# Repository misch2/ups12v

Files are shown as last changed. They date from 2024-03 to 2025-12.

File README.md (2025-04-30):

# Goal

A hobby project to create simple 12 V UPS to backup my router and mini PC. Both appliances use 12 volts on input. 
This UPS:
 - should be powered by 18650 batteries
 - does not need to run for a long time, 15 minutes is perfectly OK, 30 minutes is luxury
 - should allow some sort of monitoring, ideally with an HomeAssistant integration (for charts etc.)
 - should provide at least this amount of power
   - 1A (for router)
   - or 3A (for mini PC)
 - should run primarily from the main source and switch to the batteries only when the main voltage drops. This is to protect the batteries and charging circuit so that it doesn't need to constantly provide relatively high power for a device.
 - might allow powering off itself on request when running on batteries, to allow mini PC to automatically power on later after a shutdown.

# Features

 - Can be controlled and monitored using HomeAssistant (ESP32C3 chip, ESPHome software)
 - 12 V / 3 A output
 - (optional) SW controllable output poweroff, can be used to power cycle the device attached to UPS
 - (optional) Battery calibration, i.e. one-off measuring of real available battery capacity.
 - (optional) UPS cut off on power loss and low battery, to allow for a full shutdown of both UPS and the attached device.

# Inspiration
* https://www.hackster.io/news/a-diy-mini-ups-for-wi-fi-router-9b8f11540294
* https://digitalab.org/2021/08/router-ups/
* Lithium battery charger module (12W, 3A) with 5V to 12V booster from Aliexpress:
https://vi.aliexpress.com/item/1005005742927465.html?gatewayAdapt=glo2vnm

# Version 1

Deployed to production, used for a backup of my Archer C6 router only. 
But it's mostly a proof of concept, with power limitations and without a proper PCB (components are just wired up together).

Schema: [schema_v1.pdf](hardware/v1/schema.pdf)

Some photos: [photo1](hardware/v1/IMG_20240301_100945.jpg), [photo2](hardware/v1/IMG_20240302_140645.jpg), [photo3](hardware/v1/IMG_20240302_140731.jpg).

"boosterEnable" input is there not to save power but to prevent running the XL6009 booster in an undervoltage condition. This could have been implemented using a voltage comparator (LM311?) + schmitt trigger for hysteresis. I used software solution because tbne undervoltage condition doesn't occur "suddenly" but it's only a startup condition. And using software to control it allows me to use it for powering off the UPS when it runs on battery.

## Development progress

Replaced AMS1117 with a buck converter due to a large voltage difference and therefore large heat dissipation with LDO.

Added XL6009 "EN" pin control (initial pull down + software control from ESP32).

Used Schottky diodes.

Added a diode between battery power line and XL6009 to prevent backpropagation of voltage when XL6009 is powered down.

The limitations were caused by:
 - BMS module for 18650 batteries can handle only 2A (FIXME?) of current. This is not enough for the mini PC.
 - INA219 module can handle only 3.2A of current. Again, this is not enough for the mini PC (especially not for the battery side of the UPS where the max current can easily be larger).
 - The specific XL6009 booster module doesn't have an undervoltage protection and it can produce more than 12 V on it's output when the input voltage is low. This is not good!

Anyway, this works well for the router. It can run for more than 2 hours from batteries because the router consumes only about 3 watts and the output current is therefore mostly below 300 mA. So I might call this a success ✅!

# Version 1.5

I wanted to overcome the limitations of the first version and to make it handle larger current to power the mini PC which might need up to 3 A. This higher current would also require something better than the INA219.

I also added relays to allow the UPS to be powered off completely when running on batteries. This is to allow the mini PC to power on automatically after a power outage. And a 2nd relay allows to power cycle the UPS or to run calibration.

ACS712 sensors paired with an ADS1115 ADC are used for current and voltage monitoring. It can handle up to 20 A. 

A pair of XL74610 ideal diodes is used instead of Schottky diodes in v1, to achieve a lower voltage drop and to allow for higher currents.

TP5100 charger module is used for charging the batteries, combined with BMS for 2S 8.4V/20A.

Alas, while everything looked good on the paper, reality was different ❌. The "better" booster module ([LM2587 version](https://www.laskakit.cz/step-up-boost-menic-lm2587--4-30v-30w/)) advertises up to 5A and 30W, but something might be wrong with it. I'm not able to pull more than 1 A from the UPS, the voltage drastically drops if I try to pull more.

Possible causes (investigating ⌛):
 - Batteries don't provide enough current? Not very probable, I'm using 3000 mAh cells from a reputable manufacturer.
 - BMS module can't handle the current? It should be able to handle 20 A but does it?
 - Booster module can't handle the current? It should be able to handle 5 A but does it?
 - Something else?

An idea: disconnect the LM2587 booster and attach an electronic load to the battery instead of it. Then try to pull whatever it takes to see if the batteries can provide the current. If they can, then the problem is with the booster. If they can't, then the problem is with the batteries or BMS.

Result: ⌛

# FIXME TODO 

Maybe this was a completely bad approach. Sticking to 2x 18650 doesn't make sense if I need to pull 3 A. I should have used 4S 18650 (13.6 V - 16.8 V) and eliminate the boost converter completely. When stepping down to 12 V, the current would be lower and the voltage drop would be lower.
Also no need to stick with 12 V and a boost converter on input.

# Version 2

Using **BQ25798** battery charger IC from Texas Instruments. According to the datasheet it can handle up to 5 A on the output and 3A on the input and has a built-in buck-boost converter usable for either battery charging or for the UPS backup mode. It can also be controlled and monitored extensively using I2C.

Product info: https://www.ti.com/product/BQ25798

Most important features:
* Buck-boost charger for 1-4 cell batteries
* Narrow voltage DC (NVDC) power path
* Backup Mode with Ultra-fast switchover to adjustable voltage
* Flexible autonomous and I2C mode for optimal system performance
* Intelligent current management to prevent source overload when charging batteries
* Integrated 16-bit ADC for voltage, current, and temperature monitoring

It's essentially a battery charger capable of using boost converter to charge the batteries, but it can also detect a drop in input voltage and switch to the backup mode aka battery mode very fast. In the backup mode it works as buck converter and uses the batteries to power the load.

So, theoretically, with this IC I can eliminate all the former external circuitry because BQ25798 will take care of both charging the batteries and providing power to the load. And it has hundreds of I2C registers to set up and monitor the system.

#### Normal mode power path:

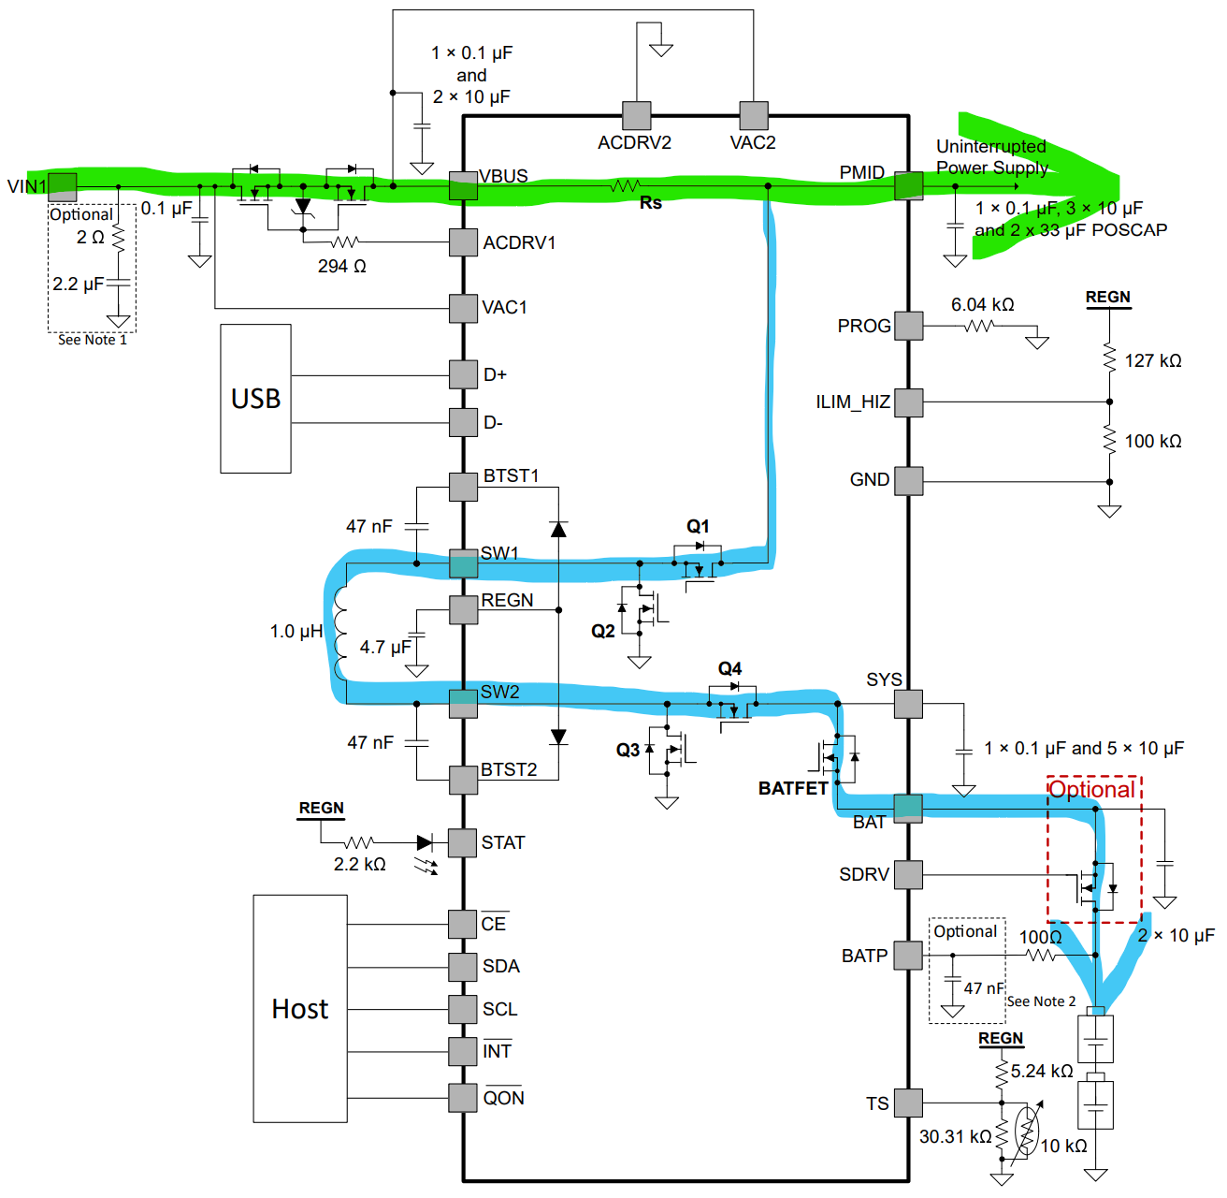
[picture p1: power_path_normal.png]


#### Backup mode power path:

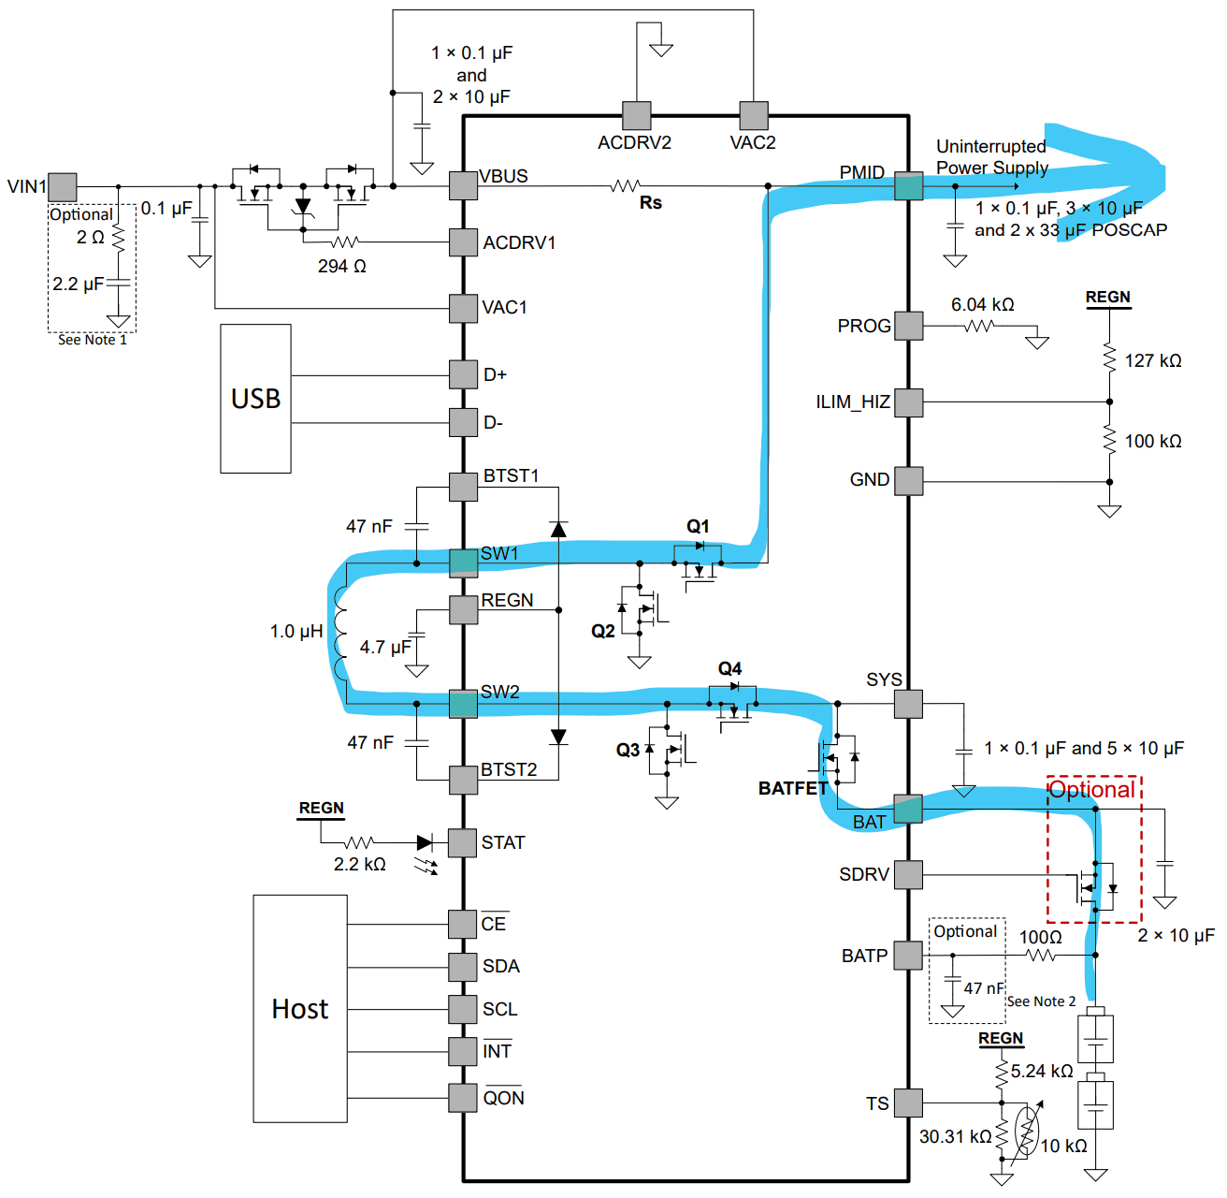
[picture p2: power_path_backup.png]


#### Inductor selection

See page 133 of datasheet:

```
L = 2.2 µH (only two inductor values are available: 2.2 µH and 1 µH)

Isat >= MAX((Iin + Iripple/2), Ichg + Iripple/2)

Iripple_buck = Vsys / Vbus * (Vbus - Vsys) / (Fsw * L)
Iripple_boost = Vbus /Vsys * (Vsys - Vbus) / (Fsw * L)
```

For my purposes (12 V input, 12 V output, 4S Li-Ion battery pack, 3 A power source) the values are:

```
Iin = 3 A (input current)
Vbus = 12 V (input voltage)
Vsys = +16.8 V (battery voltage)

Iripple_buck = 12 V / 16.8 V * (16.8 V - 12 V) / (750 kHz * 2.2 uH) = 3.43 / 1.65 = 2.08 A
Iripple_boost = 16.8 V / 12 V * (12 V - 16.8 V) / (750 kHz * 2.2 uH) = -6.72 / 1.65 = -4.07 A

Isat >= MAX(5.08 A, 7.07 A) = 7.07 A
```

#### PROG resistor selection

See page 25 of datasheet:

2.2 uH inductor requires 750 kHz switching frequency. Therefore the PROG resistor = **27 kOhm** which means:
 - Switching frequency = 750 kHz
 - Cell count: 4
 - ICHG: 1 A
 - VSYSMIN: 12 V
 - VREG: 16.8 V (range 14 V - 18.8 V)

### Principle:

#### Forward (battery charge) mode:

In this mode PMID follows VBUS, i.e. it's not regulated. PMID is also the input to the buck-boost converter. 

#### Battery backup mode:

The FETs between AC1 and VBUS provide reverse blocking (prevents battery voltage from being seen at VBUS). PMID is output of the buck/boost converter.

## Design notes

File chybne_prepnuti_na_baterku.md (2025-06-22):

```
[T+ 90.540s]      ADC_DONE_STAT (bool) = TRUE                                                   (was false)
[T+ 90.540s]             ADC_EN (bool) = false                                                  (was TRUE)
[T+ 90.540s]         TS_ADC (float, %) = 60.059                  (was 58.887)
[T+ 90.540s]       DPLUS_ADC (int, mV) = 4                        (was     3)
Main stats: VSYS_REG! NO_VBAT! +EN_BACKUP +EN_CHG +EN_ACDRV1 CHG=[1]"Trickle Charge" 

[T+ 94.714s]           CHG_FLAG (bool) = TRUE                                                   (was false)
[T+ 94.714s]   VBATOTG_LOW_FLAG (bool) = TRUE                                                   (was false)
Main stats: VSYS_REG! NO_VBAT! +EN_BACKUP +EN_CHG +EN_ACDRV1 CHG=[1]"Trickle Charge"

[T+ 96.702s]           CHG_STAT (enum) = [0] "Not Charging"                                     (was [1] "Trickle Charge")
[T+ 96.702s]          VSYS_STAT (enum) = [0] "Not in VSYSMIN regulation (VBAT > VSYSMIN)"       (was [1] "In VSYSMIN regulation (VBAT < VSYSMIN)")
[T+ 96.702s]   VBATOTG_LOW_STAT (enum) = [0] "VBAT is too low to enable OTG mode"               (was [1] "VBAT is high enough to enable OTG operation")
[T+ 96.702s]      VBAT_OVP_STAT (bool) = TRUE                                                   (was false)
[T+ 96.702s]           CHG_FLAG (bool) = TRUE                                                   (was false)
Main stats: NO_VBAT! +EN_BACKUP +EN_CHG +EN_ACDRV1 CHG=[0]"Not Charging"

[T+ 96.958s]           CHG_STAT (enum) = [1] "Trickle Charge"                                   (was [0] "Not Charging")
[T+ 96.958s]          VSYS_STAT (enum) = [1] "In VSYSMIN regulation (VBAT < VSYSMIN)"           (was [0] "Not in VSYSMIN regulation (VBAT > VSYSMIN)")
[T+ 96.958s]   VBATOTG_LOW_STAT (enum) = [1] "VBAT is high enough to enable OTG operation"      (was [0] "VBAT is too low to enable OTG mode")
[T+ 96.958s]      VBAT_OVP_STAT (bool) = false                                                  (was TRUE)
[T+ 96.958s]   VBATOTG_LOW_FLAG (bool) = TRUE                                                   (was false)
Main stats: VSYS_REG! NO_VBAT! +EN_BACKUP +EN_CHG +EN_ACDRV1 CHG=[1]"Trickle Charge" 

[T+ 98.198s]           CHG_STAT (enum) = [0] "Not Charging"                                     (was [1] "Trickle Charge")
[T+ 98.198s]          VSYS_STAT (enum) = [0] "Not in VSYSMIN regulation (VBAT > VSYSMIN)"       (was [1] "In VSYSMIN regulation (VBAT < VSYSMIN)")
[T+ 98.198s]   VBATOTG_LOW_STAT (enum) = [0] "VBAT is too low to enable OTG mode"               (was [1] "VBAT is high enough to enable OTG operation")
[T+ 98.198s]      VBAT_OVP_STAT (bool) = TRUE                                                   (was false)
[T+ 98.198s]           CHG_FLAG (bool) = TRUE                                                   (was false)
Main stats: NO_VBAT! +EN_BACKUP +EN_CHG +EN_ACDRV1 CHG=[0]"Not Charging"
```

Tady se to po připojení baterie krásně přepnulo a drželo:
```
[T+ 99.635s]  VBAT_PRESENT_STAT (enum) = [1] "VBAT present"                                     (was [0] "VBAT NOT present")
Main stats: +EN_BACKUP +EN_CHG +EN_ACDRV1 CHG=[0]"Not Charging" 

[T+120.330s]      ADC_DONE_STAT (bool) = false                                                  (was TRUE)
[T+120.330s]             ADC_EN (bool) = TRUE                                                   (was false)
[T+120.330s]        IBUS_ADC (int, mA) = 19                       (was    58)
[T+120.330s]        VBUS_ADC (int, mV) = 4814                     (was  5025)
[T+120.330s]        VAC1_ADC (int, mV) = 4799                     (was  5010)
[T+120.330s]        VAC2_ADC (int, mV) = 4800                     (was  5009)
[T+120.330s]        VBAT_ADC (int, mV) = 7922                     (was  2014)
[T+120.330s]        VSYS_ADC (int, mV) = 16130                    (was  3397)
Main stats: +EN_BACKUP +EN_CHG +EN_ACDRV1 CHG=[0]"Not Charging"

[T+120.586s]      ADC_DONE_STAT (bool) = TRUE                                                   (was false)
[T+120.586s]             ADC_EN (bool) = false                                                  (was TRUE)
[T+120.586s]         TS_ADC (float, %) = 61.816                  (was 60.059)
[T+120.586s]    TDIE_ADC (float, degC) = 61.500                  (was 18.500)
[T+120.586s]       DPLUS_ADC (int, mV) = 35                       (was     4)
[T+120.586s]      DMINUS_ADC (int, mV) = 35                       (was     3)
Main stats: +EN_BACKUP +EN_CHG +EN_ACDRV1 CHG=[0]"Not Charging"
```

Ale po chvíli se to přepnulo zpátky do normálního režimu, což při odpojeném napájení znamená problém:
```
[T+131.261s]          EN_BACKUP (bool) = false                                                  (was TRUE)
[T+131.261s]          EN_ACDRV1 (bool) = false                                                  (was TRUE)
[T+131.261s]        ICO_ILIM (int, mA) = 500                      (was  3000)
[T+131.261s]            PG_STAT (enum) = [0] "Not in power good status"                         (was [1] "Power good")
[T+131.261s]   AC2_PRESENT_STAT (enum) = [0] "VAC2 NOT present"                                 (was [1] "VAC2 present (above present threshold)")
[T+131.261s]   AC1_PRESENT_STAT (enum) = [0] "VAC1 NOT present"                                 (was [1] "VAC1 present (above present threshold)")
[T+131.261s]  VBUS_PRESENT_STAT (enum) = [0] "VBUS NOT present"                                 (was [1] "VBUS present (above present threshold)")
[T+131.261s]          VBUS_STAT (enum) = [0] "No Input or BHOT or BCOLD in OTG mode"            (was [5] "Unknown adaptor (3A)")
[T+131.261s]      VBAT_OVP_STAT (bool) = false                                                  (was TRUE)
Main stats: NOT_PG! NO_VBUS! NO_AC1! +EN_CHG CHG=[0]"Not Charging"

[T+150.471s]      ADC_DONE_STAT (bool) = false                                                  (was TRUE)
[T+150.471s]      VBAT_OVP_STAT (bool) = TRUE                                                   (was false)
[T+150.471s]             ADC_EN (bool) = TRUE                                                   (was false)
[T+150.471s]        IBUS_ADC (int, mA) = 0                        (was    19)
[T+150.471s]        VBUS_ADC (int, mV) = 0                        (was  4814)
[T+150.471s]        VAC1_ADC (int, mV) = 0                        (was  4799)
[T+150.471s]        VAC2_ADC (int, mV) = 0                        (was  4800)
[T+150.471s]        VBAT_ADC (int, mV) = 7989                     (was  7922)
[T+150.471s]        VSYS_ADC (int, mV) = 16194                    (was 16130)
Main stats: NOT_PG! NO_VBUS! NO_AC1! +EN_CHG CHG=[0]"Not Charging"

[T+150.738s]      ADC_DONE_STAT (bool) = TRUE                                                   (was false)
[T+150.738s]      VBAT_OVP_STAT (bool) = false                                                  (was TRUE)
[T+150.738s]             ADC_EN (bool) = false                                                  (was TRUE)
[T+150.738s]         TS_ADC (float, %) = 61.426                  (was 61.816)
[T+150.738s]    TDIE_ADC (float, degC) = 20.000                  (was 61.500)
[T+150.738s]       DPLUS_ADC (int, mV) = 25                       (was    35)
[T+150.738s]      DMINUS_ADC (int, mV) = 25                       (was    35)
Main stats: NOT_PG! NO_VBUS! NO_AC1! +EN_CHG CHG=[0]"Not Charging"
```

Proč? Viz VBAT_OVP_STAT. Myslelo si to, že je baterka přebitá. Důvodem bylo toto, chybná startovací konfigurace:
```
[T+  0.000s]         VSYSMIN (int, mV) = 3500
[T+  0.000s]            VREG (int, mV) = 4200
[T+  0.000s]            ICHG (int, mA) = 1000
[T+  0.000s]               CELL (enum) = [0] "1S"
[T+  0.000s]           PWM_FREQ (enum) = [1] "750 kHz"
[T+  0.000s]  VBAT_PRESENT_STAT (enum) = [0] "VBAT NOT present"
```
To odpovídá PROG rezistoru 4k7, nikoli 27k:
```
Table 9-1. PROG Pin Resistance to Set Default Switching Frequency and Battery Cell Count
SWITCHING FREQUENCY CELL COUNT TYPICAL RESISTANCE AT PROG PIN
1.5 MHz 1s 3.0 kΩ
750 kHz 1s 4.7 kΩ
1.5 MHz 2s 6.04 kΩ
750 kHz 2s 8.2 kΩ
1.5 MHz 3s 10.5 kΩ
750 kHz 3s 13.7 kΩ
1.5 MHz 4s 17.4 kΩ
750 kHz 4s 27.0 kΩ
```

!!! OK !!!

Po kontrole PCB je to už OK:
```
[T+  0.000s]         VSYSMIN (int, mV) = 12000
[T+  0.000s]            VREG (int, mV) = 16800
[T+  0.000s]            ICHG (int, mA) = 1000
[T+  0.000s]               CELL (enum) = [3] "4S"
[T+  0.000s]        VBUS_ADC (int, mV) = 5064
```

Nastavení a detekce napětí z 5V taky vypadá dobře (5 V na VAC1, 12 V na SYS -- tedy přes boost converter):
```
[T+  1.435s]      ADC_DONE_STAT (bool) = TRUE                                                   (was false)
[T+  1.435s]             ADC_EN (bool) = false                                                  (was TRUE)
[T+  1.435s]        VAC1_ADC (int, mV) = 5068                     (was  5151)
[T+  1.435s]        VAC2_ADC (int, mV) = 5064                     (was  5151)
[T+  1.435s]        VBAT_ADC (int, mV) = 266                      (was   348)
[T+  1.435s]        VSYS_ADC (int, mV) = 12269                    (was  2893)
[T+  1.435s]    TDIE_ADC (float, degC) = 30.500                  (was 12.000)
[T+  1.435s]       DPLUS_ADC (int, mV) = 0                        (was  3388)
Main stats: VSYS_REG! NO_VBAT! +EN_BACKUP +EN_CHG +EN_ACDRV1 CHG=[0]"Not Charging"
```

Po připojení baterie se mimo jiné zvedne proud IBUS na 230 mA. Napětí VBUS i VAC1 zůstávají na 5 V, nově je detekováno 16.5 V na VBAT, a zvedne se automaticky VSYS na 17.1 V:
```
[T+ 16.824s]          VSYS_STAT (enum) = [0] "Not in VSYSMIN regulation (VBAT > VSYSMIN)"       (was [1] "In VSYSMIN regulation (VBAT < VSYSMIN)")
[T+ 16.824s]   VBATOTG_LOW_STAT (enum) = [0] "VBAT is too low to enable OTG mode"               (was [1] "VBAT is high enough to enable OTG operation")

Main stats: NO_VBAT! +EN_BACKUP +EN_CHG +EN_ACDRV1 CHG=[0]"Not Charging"

[T+ 18.032s]  VBAT_PRESENT_STAT (enum) = [1] "VBAT present"                                     (was [0] "VBAT NOT present")
Main stats: +EN_BACKUP +EN_CHG +EN_ACDRV1 CHG=[0]"Not Charging"

[T+ 30.250s]      ADC_DONE_STAT (bool) = false                                                  (was TRUE)
[T+ 30.250s]             ADC_EN (bool) = TRUE                                                   (was false)
[T+ 30.250s]        IBUS_ADC (int, mA) = 231                      (was   155)
[T+ 30.250s]        VBUS_ADC (int, mV) = 5007                     (was  5064)
[T+ 30.250s]        VAC1_ADC (int, mV) = 5003                     (was  5068)
[T+ 30.250s]        VAC2_ADC (int, mV) = 4996                     (was  5064)
[T+ 30.250s]        VBAT_ADC (int, mV) = 16474                    (was   266)
[T+ 30.250s]        VSYS_ADC (int, mV) = 17124                    (was 12269)
Main stats: +EN_BACKUP +EN_CHG +EN_ACDRV1 CHG=[0]"Not Charging"

[T+ 30.506s]      ADC_DONE_STAT (bool) = TRUE                                                   (was false)
[T+ 30.506s]             ADC_EN (bool) = false                                                  (was TRUE)
[T+ 30.506s]         TS_ADC (float, %) = 84.473                  (was 84.570)
[T+ 30.506s]    TDIE_ADC (float, degC) = 46.000                  (was 30.500)
Main stats: +EN_BACKUP +EN_CHG +EN_ACDRV1 CHG=[0]"Not Charging"

[T+ 60.279s]      ADC_DONE_STAT (bool) = false                                                  (was TRUE)
[T+ 60.279s]             ADC_EN (bool) = TRUE                                                   (was false)
[T+ 60.279s]        IBUS_ADC (int, mA) = 233                      (was   231)
[T+ 60.279s]        VAC2_ADC (int, mV) = 4999                     (was  4996)
[T+ 60.279s]        VBAT_ADC (int, mV) = 16477                    (was 16474)
[T+ 60.279s]        VSYS_ADC (int, mV) = 17127                    (was 17124)
Main stats: +EN_BACKUP +EN_CHG +EN_ACDRV1 CHG=[0]"Not Charging"

[T+ 60.525s]      ADC_DONE_STAT (bool) = TRUE                                                   (was false)
[T+ 60.525s]             ADC_EN (bool) = false                                                  (was TRUE)
[T+ 60.525s]    TDIE_ADC (float, degC) = 48.000                  (was 46.000)
Main stats: +EN_BACKUP +EN_CHG +EN_ACDRV1 CHG=[0]"Not Charging"

[T+ 90.290s]      ADC_DONE_STAT (bool) = false                                                  (was TRUE)
[T+ 90.290s]             ADC_EN (bool) = TRUE                                                   (was false)
[T+ 90.290s]        VAC1_ADC (int, mV) = 4999                     (was  5003)
[T+ 90.290s]        VAC2_ADC (int, mV) = 4995                     (was  4999)
[T+ 90.290s]        VBAT_ADC (int, mV) = 16483                    (was 16477)
[T+ 90.290s]        VSYS_ADC (int, mV) = 17133                    (was 17127)
Main stats: +EN_BACKUP +EN_CHG +EN_ACDRV1 CHG=[0]"Not Charging"

[T+ 90.535s]      ADC_DONE_STAT (bool) = TRUE                                                   (was false)
[T+ 90.535s]             ADC_EN (bool) = false                                                  (was TRUE)
[T+ 90.535s]    TDIE_ADC (float, degC) = 49.000                  (was 48.000)
Main stats: +EN_BACKUP +EN_CHG +EN_ACDRV1 CHG=[0]"Not Charging"
```

(PMID jsem bohužel neměřil)

Po odpojení napájení:
 
- vypne se ACDRV, to je OK
- zapne se OTG, což je taky OK
- !!! VBUS_STAT se změní na [0] "No Input or BHOT or BCOLD in OTG mode", ale má to správně být [7] "In OTG mode"
- VBUS_PRESENT_STAT se správně změní na [0] "VBUS NOT present" 

??? Proč si myslí že je BHOT či BCOLD?

Ale s napětími a proudem je to horší:
IBUS klesne na 0 A (OK), VBUS na 1.5 V (OK), VBAT zůstává na 16.4 V a VSYS zůstává na 17.1 V.

Zatím OK, ale proč nejede v OTG režimu a neposkytuje napětí na VBUS?

```
[T+136.913s]          EN_BACKUP (bool) = false                                                  (was TRUE)
[T+136.913s]          DIS_ACDRV (bool) = TRUE                                                   (was false)
[T+136.913s]             EN_OTG (bool) = TRUE                                                   (was false)
[T+136.913s]          EN_ACDRV1 (bool) = false                                                  (was TRUE)
[T+136.913s]        ICO_ILIM (int, mA) = 500                      (was  3000)
[T+136.913s]            PG_STAT (enum) = [0] "Not in power good status"                         (was [1] "Power good")
[T+136.913s]   AC1_PRESENT_STAT (enum) = [0] "VAC1 NOT present"                                 (was [1] "VAC1 present (above present threshold)")
[T+136.913s]          VBUS_STAT (enum) = [0] "No Input or BHOT or BCOLD in OTG mode"            (was [5] "Unknown adaptor (3A)")
[T+136.913s]        IINDPM_FLAG (bool) = TRUE                                                   (was false)
Main stats: NOT_PG! NO_AC1! +EN_OTG +EN_CHG CHG=[0]"Not Charging"

[T+138.973s]  VBUS_PRESENT_STAT (enum) = [0] "VBUS NOT present"                                 (was [1] "VBUS present (above present threshold)")
Main stats: NOT_PG! NO_VBUS! NO_AC1! +EN_OTG +EN_CHG CHG=[0]"Not Charging"

[T+139.187s]   AC2_PRESENT_STAT (enum) = [0] "VAC2 NOT present"                                 (was [1] "VAC2 present (above present threshold)")
Main stats: NOT_PG! NO_VBUS! NO_AC1! +EN_OTG +EN_CHG CHG=[0]"Not Charging"

[T+150.431s]      ADC_DONE_STAT (bool) = false                                                  (was TRUE)
[T+150.431s]             ADC_EN (bool) = TRUE                                                   (was false)
[T+150.431s]        IBUS_ADC (int, mA) = 0                        (was   234)
[T+150.431s]        VBUS_ADC (int, mV) = 1457                     (was  5005)
[T+150.431s]        VAC1_ADC (int, mV) = 8                        (was  4990)
[T+150.431s]        VAC2_ADC (int, mV) = 1455                     (was  4997)
[T+150.431s]        VBAT_ADC (int, mV) = 16400                    (was 16485)
[T+150.431s]        VSYS_ADC (int, mV) = 16429                    (was 17130)
Main stats: NOT_PG! NO_VBUS! NO_AC1! +EN_OTG +EN_CHG CHG=[0]"Not Charging"

[T+150.687s]      ADC_DONE_STAT (bool) = TRUE                                                   (was false)
[T+150.687s]             ADC_EN (bool) = false                                                  (was TRUE)
[T+150.687s]         TS_ADC (float, %) = 84.570                  (was 84.473)
[T+150.687s]    TDIE_ADC (float, degC) = 38.000                  (was 49.000)
Main stats: NOT_PG! NO_VBUS! NO_AC1! +EN_OTG +EN_CHG CHG=[0]"Not Charging"
```

Ale:
CHG_STAT pin = 4.99 v
REGN pin = 0.1 V
PMID pin = 1.43 V
BAT pin = 16.12 V

tzn. zjevně neposílá nic na výstup. Ale proč?
A proč je REGN tak nízký?

Přitom ale funguje a komunikuje přes I2C. Tzn. napětí si z baterie bere, jen na výstup nic neposílá.

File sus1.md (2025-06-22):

```
[T+  1.433s]        VBUS_ADC (int, mV) = 5213                     (was  5215)
Main stats: +EN_CHG +EN_ACDRV1 CHG=[0]"Not Charging"

[T+  1.636s]        VBUS_ADC (int, mV) = 5211                     (was  5213)
Main stats: +EN_CHG +EN_ACDRV1 CHG=[0]"Not Charging"

[T+  2.229s]        IINDPM_FLAG (bool) = TRUE                                                   (was false)
[T+  2.229s]        VBUS_ADC (int, mV) = 5216                     (was  5211)
Main stats: +EN_CHG +EN_ACDRV1 CHG=[0]"Not Charging"

[T+  2.832s]        IINDPM_FLAG (bool) = TRUE                                                   (was false)
[T+  2.832s]        VBUS_ADC (int, mV) = 5213                     (was  5216)
Main stats: +EN_CHG +EN_ACDRV1 CHG=[0]"Not Charging"

[T+  3.240s]        VBUS_ADC (int, mV) = 5209                     (was  5213)
Main stats: +EN_CHG +EN_ACDRV1 CHG=[0]"Not Charging"

[T+  3.443s]             EN_HIZ (bool) = TRUE                                                   (was false)
[T+  3.443s]        ICO_ILIM (int, mA) = 500                      (was  3000)
[T+  3.443s]        IINDPM_FLAG (bool) = TRUE                                                   (was false)
[T+  3.443s]        IBAT_ADC (int, mA) = 0                        (was    -1)
[T+  3.443s]        VBUS_ADC (int, mV) = 5215                     (was  5209)
[T+  3.443s]        VAC1_ADC (int, mV) = 5200                     (was  5203)
[T+  3.443s]        VBAT_ADC (int, mV) = 16384                    (was 16378)
[T+  3.443s]        VSYS_ADC (int, mV) = 16421                    (was 16418)
Main stats: HIZ_EN! +EN_CHG +EN_ACDRV1 CHG=[0]"Not Charging"
```

Čím to může být, že se sám od sebe zapnul EN_HIZ?

No, jelikož se sám od sebe změnil i ICO_ILIM (ale ICO_STAT zůstal v \[0] "ICO disabled"), tak ...???

Doc:

Reset to 0:

> (EN_HIZ) This bit will be also reset to 0, when the adapter is plugged in at VBUS

> The EN_HIZ bit is cleared automatically when the adapter is plugged in, so cycling the adapter will also force an
> immediate retry of the poor source qualification.

Set to 1:

> Alternatively, some of the faults, like VSYS_SHORT and IBUS_OCP, force the charger into HIZ mode by setting EN_HIZ=1.

> If a poor source is detected (when pulling IPOORSRC, the VBUS voltage drops below VPOORSRC), the EN_HIZ bit
> is set to 1, PG_STAT bit remains low, PG_FLAG will be set to 1, and an INT pulse will be asserted if PG_MASK
> = 0. The device will repeat the poor source qualification routine every 7 minutes until either the adapter is
> removed or the source is qualified. Each failed poor source qualification will cause EN_HIZ and PG_FLAG to
> be set to 1, and an INT pulse will be asserted if PG_MASK = 0. In the 7 minute interim between poor source
> qualification attempts, the host may set EN_HIZ = 0 to force an immediate retry of the poor source qualification.

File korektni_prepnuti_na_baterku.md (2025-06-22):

Po připojení teplotního čidla už funguje vše:

Otestováno:
 - připojení baterie
 - odpojení původního USB
 - připojení zátěže na výstup
     - nejprve 1 A
     - pak 2 A
     - pak 3 A
     - pak 3,2 A (simulace přetížení výstupu)
- odpojení zátěže

Všechno zafungovalo!

```
[T+  0.000s]         VSYSMIN (int, mV) = 12000
[T+  0.000s]            VREG (int, mV) = 16800
[T+  0.000s]            ICHG (int, mA) = 1000
[T+  0.000s]          VINDPM (int, mV) = 4400
[T+  0.000s]          IINDPM (int, mA) = 3000
[T+  0.000s]          VBAT_LOWV (enum) = [3] "71.4%(VREG)"
[T+  0.000s]         IPRECHG (int, mA) = 120
[T+  0.000s]            REG_RST (bool) = false
[T+  0.000s]        STOP_WD_CHG (bool) = false
[T+  0.000s]           ITERM (int, mA) = 200
[T+  0.000s]               CELL (enum) = [3] "4S"
[T+  0.000s]             TRECHG (enum) = [2] "1024 ms"
[T+  0.000s]          VRECHG (int, mV) = 200
[T+  0.000s]            VOTG (int, mV) = 12000
[T+  0.000s]         PRECHG_TMR (enum) = [0] "2 hours"
[T+  0.000s]            IOTG (int, mA) = 3000
[T+  0.000s]         TOPOFF_TMR (enum) = [0] "Disabled"
[T+  0.000s]      EN_TRICHG_TMR (bool) = TRUE
[T+  0.000s]      EN_PRECHG_TMR (bool) = TRUE
[T+  0.000s]         EN_CHG_TMR (bool) = TRUE
[T+  0.000s]            CHG_TMR (enum) = [2] "12 hours"
[T+  0.000s]           TMR2X_EN (bool) = TRUE
[T+  0.000s]    EN_AUTO_IBATDIS (bool) = TRUE
[T+  0.000s]      FORCE_IBATDIS (bool) = false
[T+  0.000s]             EN_CHG (bool) = TRUE
[T+  0.000s]             EN_ICO (bool) = false
[T+  0.000s]          FORCE_ICO (bool) = false
[T+  0.000s]             EN_HIZ (bool) = false
[T+  0.000s]            EN_TERM (bool) = TRUE                                                   
[T+  0.000s]          EN_BACKUP (bool) = TRUE
[T+  0.000s]        VBUS_BACKUP (enum) = [2] "<80%(VINDPM)"
[T+  0.000s]            VAC_OVP (enum) = [0] ">26V"
[T+  0.000s]             WD_RST (bool) = false
[T+  0.000s]           WATCHDOG (enum) = [5] "40s"
[T+  0.000s]        FORCE_INDET (bool) = false
[T+  0.000s]      AUTO_INDET_EN (bool) = TRUE
[T+  0.000s]             EN_12V (bool) = false
[T+  0.000s]              EN_9V (bool) = false                                                  
[T+  0.000s]           HVDCP_EN (bool) = false
[T+  0.000s]          SDRV_CTRL (enum) = [0] "Idle"
[T+  0.000s]           SDRV_DLY (enum) = [0] "10s"
[T+  0.000s]          DIS_ACDRV (bool) = false
[T+  0.000s]             EN_OTG (bool) = false
[T+  0.000s]        PFM_OTG_DIS (bool) = false
[T+  0.000s]        PFM_FWD_DIS (bool) = false
[T+  0.000s]           WKUP_DLY (enum) = [0] "1s"
[T+  0.000s]            DIS_LDO (bool) = false
[T+  0.000s]        DIS_OTG_OOA (bool) = false
[T+  0.000s]        DIS_FWD_OOA (bool) = false                                                  
[T+  0.000s]          EN_ACDRV2 (bool) = false
[T+  0.000s]          EN_ACDRV1 (bool) = TRUE
[T+  0.000s]           PWM_FREQ (enum) = [1] "750 kHz"
[T+  0.000s]           DIS_STAT (bool) = false
[T+  0.000s]     DIS_VSYS_SHORT (bool) = false
[T+  0.000s]       DIS_VOTG_UVP (bool) = false
[T+  0.000s]   FORCE_VINDPM_DET (bool) = false
[T+  0.000s]        EN_IBUS_OCP (bool) = TRUE
[T+  0.000s]       SFET_PRESENT (bool) = false                                                  
[T+  0.000s]            EN_IBAT (bool) = false
[T+  0.000s]           IBAT_REG (enum) = [3] "Disabled"
[T+  0.000s]          EN_IINDPM (bool) = TRUE
[T+  0.000s]         EN_EXTILIM (bool) = TRUE
[T+  0.000s]           EN_BATOC (bool) = false
[T+  0.000s]            VOC_PCT (enum) = [5] "0.875"
[T+  0.000s]            VOC_DLY (enum) = [2] "2s"
[T+  0.000s]           VOC_RATE (enum) = [2] "10min"
[T+  0.000s]            EN_MPPT (bool) = false
[T+  0.000s]               TREG (enum) = [3] "120'C"
[T+  0.000s]              TSHUT (enum) = [0] "150'C"
[T+  0.000s]         VBUS_PD_EN (bool) = false
[T+  0.000s]         VAC1_PD_EN (bool) = false
[T+  0.000s]         VAC2_PD_EN (bool) = false
[T+  0.000s]     BKUP_ACFET1_ON (enum) = [0] "Idle"
[T+  0.000s]         JEITA_VSET (enum) = [3] "Set VREG to VREG-400mV (default)"
[T+  0.000s]        JEITA_ISETH (enum) = [3] "ICHG unchanged"
[T+  0.000s]        JEITA_ISETC (enum) = [1] "Set ICHG to 20%* ICHG (default)"
[T+  0.000s]            TS_COOL (enum) = [1] "10'C (default)"
[T+  0.000s]            TS_WARM (enum) = [1] "45'C (default)"
[T+  0.000s]               BHOT (enum) = [1] "60'C (default)"
[T+  0.000s]              BCOLD (enum) = [0] "-10'C (default)"                                  
[T+  0.000s]          TS_IGNORE (bool) = false
[T+  0.000s]        ICO_ILIM (int, mA) = 3000
[T+  0.000s]        IINDPM_STAT (enum) = [0] "Normal"
[T+  0.000s]        VINDPM_STAT (enum) = [0] "Normal"
[T+  0.000s]            WD_STAT (enum) = [0] "Normal"
[T+  0.000s]            PG_STAT (enum) = [1] "Power good"
[T+  0.000s]   AC2_PRESENT_STAT (enum) = [1] "VAC2 present (above present threshold)"
[T+  0.000s]   AC1_PRESENT_STAT (enum) = [1] "VAC1 present (above present threshold)"
[T+  0.000s]  VBUS_PRESENT_STAT (enum) = [1] "VBUS present (above present threshold)"
[T+  0.000s]           CHG_STAT (enum) = [0] "Not Charging"
[T+  0.000s]          VBUS_STAT (enum) = [5] "Unknown adaptor (3A)"
[T+  0.000s]     BC12_DONE_STAT (bool) = false
[T+  0.000s]           ICO_STAT (enum) = [0] "ICO disabled"
[T+  0.000s]          TREG_STAT (enum) = [0] "Normal"
[T+  0.000s]          DPDM_STAT (enum) = [0] "D+/D- detection NOT started yet or done"          
[T+  0.000s]  VBAT_PRESENT_STAT (enum) = [0] "VBAT NOT present"
[T+  0.000s]         ACRB2_STAT (bool) = false
[T+  0.000s]         ACRB1_STAT (bool) = TRUE
[T+  0.000s]      ADC_DONE_STAT (bool) = false
[T+  0.000s]          VSYS_STAT (enum) = [1] "In VSYSMIN regulation (VBAT < VSYSMIN)"
[T+  0.000s]       CHG_TMR_STAT (enum) = [0] "Normal"
[T+  0.000s]    TRICHG_TMR_STAT (enum) = [0] "Normal"
[T+  0.000s]    PRECHG_TMR_STAT (enum) = [0] "Normal"
[T+  0.000s]   VBATOTG_LOW_STAT (enum) = [1] "VBAT is high enough to enable OTG operation"
[T+  0.000s]       TS_COLD_STAT (enum) = [1] "TS in cold range"
[T+  0.000s]       TS_COOL_STAT (enum) = [0] "TS NOT in cool range"
[T+  0.000s]       TS_WARM_STAT (enum) = [0] "TS NOT in warm range"
[T+  0.000s]        TS_HOT_STAT (enum) = [0] "TS NOT in hot range"
[T+  0.000s]      IBAT_REG_STAT (bool) = false
[T+  0.000s]      VBUS_OVP_STAT (bool) = false
[T+  0.000s]      VBAT_OVP_STAT (bool) = false
[T+  0.000s]      IBUS_OCP_STAT (bool) = false
[T+  0.000s]      IBAT_OCP_STAT (bool) = false
[T+  0.000s]      CONV_OCP_STAT (bool) = false
[T+  0.000s]      VAC2_OVP_STAT (bool) = false
[T+  0.000s]      VAC1_OVP_STAT (bool) = false
[T+  0.000s]    VSYS_SHORT_STAT (bool) = false
[T+  0.000s]      VSYS_OVP_STAT (bool) = false
[T+  0.000s]       OTG_OVP_STAT (bool) = false                                                  
[T+  0.000s]       OTG_UVP_STAT (bool) = false
[T+  0.000s]         TSHUT_STAT (bool) = false
[T+  0.000s]             ADC_EN (bool) = TRUE
[T+  0.000s]           ADC_RATE (enum) = [1] "One-shot"
[T+  0.000s]         ADC_SAMPLE (enum) = [0] "15-bit"
[T+  0.000s]            ADC_AVG (enum) = [0] "No averaging"
[T+  0.000s]       ADC_AVG_INIT (bool) = false
[T+  0.000s]       IBUS_ADC_DIS (bool) = false
[T+  0.000s]       IBAT_ADC_DIS (bool) = false
[T+  0.000s]       VBUS_ADC_DIS (bool) = false
[T+  0.000s]       VBAT_ADC_DIS (bool) = false
[T+  0.000s]       VSYS_ADC_DIS (bool) = false
[T+  0.000s]         TS_ADC_DIS (bool) = false
[T+  0.000s]       TDIE_ADC_DIS (bool) = false
[T+  0.000s]      DPLUS_ADC_DIS (bool) = false
[T+  0.000s]     DMINUS_ADC_DIS (bool) = false
[T+  0.000s]       VAC2_ADC_DIS (bool) = false
[T+  0.000s]       VAC1_ADC_DIS (bool) = false
[T+  0.000s]        IBUS_ADC (int, mA) = 160
[T+  0.000s]        IBAT_ADC (int, mA) = 0
[T+  0.000s]        VBUS_ADC (int, mV) = 5039
[T+  0.000s]        VAC1_ADC (int, mV) = 5040
[T+  0.000s]        VAC2_ADC (int, mV) = 4975
[T+  0.000s]        VBAT_ADC (int, mV) = 255
[T+  0.000s]        VSYS_ADC (int, mV) = 12268
[T+  0.000s]         TS_ADC (float, %) = 84.570
[T+  0.000s]    TDIE_ADC (float, degC) = 31.000
[T+  0.000s]       DPLUS_ADC (int, mV) = 0
[T+  0.000s]      DMINUS_ADC (int, mV) = 0
[T+  0.000s]          DPLUS_DAC (enum) = [0] "HIZ"
[T+  0.000s]         DMINUS_DAC (enum) = [0] "HIZ"
[T+  0.000s]                 PN (enum) = [3] "BQ25798"
[T+  0.000s]            DEV_REV (enum) = [1] "BQ25798"
Main stats: VSYS_REG! NO_VBAT! +EN_BACKUP +EN_CHG +EN_ACDRV1 CHG=[0]"Not Charging"

[T+  1.434s]      ADC_DONE_STAT (bool) = TRUE                                                   (was false)
[T+  1.434s]             ADC_EN (bool) = false                                                  (was TRUE)
[T+  1.434s]        VAC1_ADC (int, mV) = 5041                     (was  5040)
[T+  1.434s]        VAC2_ADC (int, mV) = 5040                     (was  4975)
Main stats: VSYS_REG! NO_VBAT! +EN_BACKUP +EN_CHG +EN_ACDRV1 CHG=[0]"Not Charging"

[T+ 30.382s]      ADC_DONE_STAT (bool) = false                                                  (was TRUE)
[T+ 30.382s]             ADC_EN (bool) = TRUE                                                   (was false)
[T+ 30.382s]        IBUS_ADC (int, mA) = 163                      (was   160)
[T+ 30.382s]        VBUS_ADC (int, mV) = 5048                     (was  5039)
[T+ 30.382s]        VAC1_ADC (int, mV) = 5037                     (was  5041)
[T+ 30.382s]        VAC2_ADC (int, mV) = 5033                     (was  5040)
[T+ 30.382s]        VBAT_ADC (int, mV) = 260                      (was   255)
[T+ 30.382s]        VSYS_ADC (int, mV) = 12266                    (was 12268)
Main stats: VSYS_REG! NO_VBAT! +EN_BACKUP +EN_CHG +EN_ACDRV1 CHG=[0]"Not Charging" 

[T+ 30.640s]      ADC_DONE_STAT (bool) = TRUE                                                   (was false)
[T+ 30.640s]             ADC_EN (bool) = false                                                  (was TRUE)
[T+ 30.640s]    TDIE_ADC (float, degC) = 33.500                  (was 31.000)
Main stats: VSYS_REG! NO_VBAT! +EN_BACKUP +EN_CHG +EN_ACDRV1 CHG=[0]"Not Charging" 

[T+ 50.881s]           CHG_STAT (enum) = [1] "Trickle Charge"                                   (was [0] "Not Charging")
[T+ 50.881s]       TS_COLD_STAT (enum) = [0] "TS NOT in cold range"                             (was [1] "TS in cold range")
[T+ 50.881s]           CHG_FLAG (bool) = TRUE                                                   (was false)
Main stats: VSYS_REG! NO_VBAT! +EN_BACKUP +EN_CHG +EN_ACDRV1 CHG=[1]"Trickle Charge"

[T+ 51.307s]           CHG_STAT (enum) = [0] "Not Charging"                                     (was [1] "Trickle Charge")
[T+ 51.307s]       TS_COLD_STAT (enum) = [1] "TS in cold range"                                 (was [0] "TS NOT in cold range")
Main stats: VSYS_REG! NO_VBAT! +EN_BACKUP +EN_CHG +EN_ACDRV1 CHG=[0]"Not Charging"

[T+ 51.733s]           CHG_STAT (enum) = [1] "Trickle Charge"                                   (was [0] "Not Charging")
[T+ 51.733s]       TS_COLD_STAT (enum) = [0] "TS NOT in cold range"                             (was [1] "TS in cold range")
[T+ 51.733s]           CHG_FLAG (bool) = TRUE                                                   (was false)
Main stats: VSYS_REG! NO_VBAT! +EN_BACKUP +EN_CHG +EN_ACDRV1 CHG=[1]"Trickle Charge"

[T+ 60.477s]      ADC_DONE_STAT (bool) = false                                                  (was TRUE)
[T+ 60.477s]             ADC_EN (bool) = TRUE                                                   (was false)
[T+ 60.477s]        IBUS_ADC (int, mA) = 192                      (was   163)
[T+ 60.477s]        VBUS_ADC (int, mV) = 4895                     (was  5048)
[T+ 60.477s]        VAC1_ADC (int, mV) = 4877                     (was  5037)
[T+ 60.477s]        VAC2_ADC (int, mV) = 4816                     (was  5033)
[T+ 60.477s]        VBAT_ADC (int, mV) = 1902                     (was   260)
[T+ 60.477s]        VSYS_ADC (int, mV) = 12091                    (was 12266)
Main stats: VSYS_REG! NO_VBAT! +EN_BACKUP +EN_CHG +EN_ACDRV1 CHG=[1]"Trickle Charge"

[T+ 60.735s]      ADC_DONE_STAT (bool) = TRUE                                                   (was false)
[T+ 60.735s]             ADC_EN (bool) = false                                                  (was TRUE)
[T+ 60.735s]         TS_ADC (float, %) = 60.352                  (was 84.570)
[T+ 60.735s]    TDIE_ADC (float, degC) = 38.500                  (was 33.500)
[T+ 60.735s]       DPLUS_ADC (int, mV) = 191                      (was     0)
[T+ 60.735s]      DMINUS_ADC (int, mV) = 178                      (was     0)
Main stats: VSYS_REG! NO_VBAT! +EN_BACKUP +EN_CHG +EN_ACDRV1 CHG=[1]"Trickle Charge"

[T+ 65.141s]          VSYS_STAT (enum) = [0] "Not in VSYSMIN regulation (VBAT > VSYSMIN)"       (was [1] "In VSYSMIN regulation (VBAT < VSYSMIN)")
[T+ 65.141s]   VBATOTG_LOW_STAT (enum) = [0] "VBAT is too low to enable OTG mode"               (was [1] "VBAT is high enough to enable OTG operation")
Main stats: NO_VBAT! +EN_BACKUP +EN_CHG +EN_ACDRV1 CHG=[1]"Trickle Charge"

✅Připojení baterie:

[T+ 66.556s]        VINDPM_STAT (enum) = [1] "In VINDPM regulation or VOTG regulation"          (was [0] "Normal")
[T+ 66.556s]           CHG_STAT (enum) = [3] "Fast Charge (CC mode)"                            (was [1] "Trickle Charge")
[T+ 66.556s]  VBAT_PRESENT_STAT (enum) = [1] "VBAT present"                                     (was [0] "VBAT NOT present")
[T+ 66.556s]           CHG_FLAG (bool) = TRUE                                                   (was false)
Main stats: IN_DPM! +EN_BACKUP +EN_CHG +EN_ACDRV1 CHG=[3]"Fast Charge (CC mode)"

✅Odpojení napájení (a automatické přepnutí na baterku):

[T+ 78.734s]          DIS_ACDRV (bool) = TRUE                                                   (was false)
[T+ 78.734s]             EN_OTG (bool) = TRUE                                                   (was false)
[T+ 78.734s]          EN_ACDRV1 (bool) = false                                                  (was TRUE)
[T+ 78.734s]        ICO_ILIM (int, mA) = 500                      (was  3000)
[T+ 78.734s]            PG_STAT (enum) = [0] "Not in power good status"                         (was [1] "Power good")
[T+ 78.734s]   AC1_PRESENT_STAT (enum) = [0] "VAC1 NOT present"                                 (was [1] "VAC1 present (above present threshold)")
[T+ 78.734s]           CHG_STAT (enum) = [0] "Not Charging"                                     (was [3] "Fast Charge (CC mode)")
[T+ 78.734s]          VBUS_STAT (enum) = [7] "In OTG mode"                                      (was [5] "Unknown adaptor (3A)")
[T+ 78.734s]        IINDPM_FLAG (bool) = TRUE                                                   (was false)
[T+ 78.734s]           CHG_FLAG (bool) = TRUE                                                   (was false)
Main stats: IN_DPM! NOT_PG! NO_AC1! +EN_OTG +EN_CHG CHG=[0]"Not Charging" 

[T+ 79.034s]          EN_BACKUP (bool) = false                                                  (was TRUE)
Main stats: IN_DPM! NOT_PG! NO_AC1! +EN_OTG +EN_CHG CHG=[0]"Not Charging"

❗Teď bych si měl začít hlídat vstup, a případně znovu zapnout EN_BACKUP aby se po opětovném připojení napájení opět přepnul provoz na AC1.

✅Správně teď platí že VSYS = VBAT = 16.4 V, přičemž VBUS (=PMID) je cca 11.9 V

[T+ 90.527s]          VINDPM (int, mV) = 10500                    (was  4400)
[T+ 90.527s]      ADC_DONE_STAT (bool) = false                                                  (was TRUE)
[T+ 90.527s]             ADC_EN (bool) = TRUE                                                   (was false)
[T+ 90.527s]        IBUS_ADC (int, mA) = -13                      (was   192)
[T+ 90.527s]        IBAT_ADC (int, mA) = -1                       (was     0)
[T+ 90.527s]        VBUS_ADC (int, mV) = 11911                    (was  4895)
[T+ 90.527s]        VAC1_ADC (int, mV) = 19                       (was  4877)
[T+ 90.527s]        VAC2_ADC (int, mV) = 11893                    (was  4816)
[T+ 90.527s]        VBAT_ADC (int, mV) = 16414                    (was  1902)
[T+ 90.527s]        VSYS_ADC (int, mV) = 16435                    (was 12091)
Main stats: IN_DPM! NOT_PG! NO_AC1! +EN_OTG +EN_CHG CHG=[0]"Not Charging"

[T+ 90.805s]      ADC_DONE_STAT (bool) = TRUE                                                   (was false)
[T+ 90.805s]             ADC_EN (bool) = false                                                  (was TRUE)
[T+ 90.805s]         TS_ADC (float, %) = 59.082                  (was 60.352)
[T+ 90.805s]    TDIE_ADC (float, degC) = 36.000                  (was 38.500)
[T+ 90.805s]       DPLUS_ADC (int, mV) = 44                       (was   191)
[T+ 90.805s]      DMINUS_ADC (int, mV) = 35                       (was   178)
Main stats: IN_DPM! NOT_PG! NO_AC1! +EN_OTG +EN_CHG CHG=[0]"Not Charging" 

[T+120.556s]      ADC_DONE_STAT (bool) = false                                                  (was TRUE)
[T+120.556s]             ADC_EN (bool) = TRUE                                                   (was false)
[T+120.556s]        IBUS_ADC (int, mA) = -10                      (was   -13)
[T+120.556s]        IBAT_ADC (int, mA) = 0                        (was    -1)
[T+120.556s]        VBUS_ADC (int, mV) = 11906                    (was 11911)
[T+120.556s]        VAC2_ADC (int, mV) = 11894                    (was 11893)
[T+120.556s]        VBAT_ADC (int, mV) = 16405                    (was 16414)
[T+120.556s]        VSYS_ADC (int, mV) = 16429                    (was 16435)
Main stats: IN_DPM! NOT_PG! NO_AC1! +EN_OTG +EN_CHG CHG=[0]"Not Charging"

[T+120.814s]      ADC_DONE_STAT (bool) = TRUE                                                   (was false)
[T+120.814s]             ADC_EN (bool) = false                                                  (was TRUE)
[T+120.814s]         TS_ADC (float, %) = 54.199                  (was 59.082)
[T+120.814s]    TDIE_ADC (float, degC) = 35.500                  (was 36.000)
[T+120.814s]       DPLUS_ADC (int, mV) = 58                       (was    44)
[T+120.814s]      DMINUS_ADC (int, mV) = 46                       (was    35)
Main stats: IN_DPM! NOT_PG! NO_AC1! +EN_OTG +EN_CHG CHG=[0]"Not Charging"

[T+150.572s]      ADC_DONE_STAT (bool) = false                                                  (was TRUE)
[T+150.572s]             ADC_EN (bool) = TRUE                                                   (was false)
[T+150.572s]        VBUS_ADC (int, mV) = 11914                    (was 11906)
[T+150.572s]        VAC1_ADC (int, mV) = 24                       (was    19)
[T+150.572s]        VAC2_ADC (int, mV) = 11893                    (was 11894)
[T+150.572s]        VBAT_ADC (int, mV) = 16407                    (was 16405)
[T+150.572s]        VSYS_ADC (int, mV) = 16423                    (was 16429)
Main stats: IN_DPM! NOT_PG! NO_AC1! +EN_OTG +EN_CHG CHG=[0]"Not Charging"

[T+150.830s]      ADC_DONE_STAT (bool) = TRUE                                                   (was false)
[T+150.830s]             ADC_EN (bool) = false                                                  (was TRUE)
[T+150.830s]         TS_ADC (float, %) = 59.473                  (was 54.199)
[T+150.830s]       DPLUS_ADC (int, mV) = 47                       (was    58)
[T+150.830s]      DMINUS_ADC (int, mV) = 38                       (was    46)
Main stats: IN_DPM! NOT_PG! NO_AC1! +EN_OTG +EN_CHG CHG=[0]"Not Charging"

[T+180.768s]      ADC_DONE_STAT (bool) = false                                                  (was TRUE)
[T+180.768s]             ADC_EN (bool) = TRUE                                                   (was false)
[T+180.768s]        IBUS_ADC (int, mA) = -13                      (was   -10)
[T+180.768s]        IBAT_ADC (int, mA) = -1                       (was     0)
[T+180.768s]        VBUS_ADC (int, mV) = 11906                    (was 11914)
[T+180.768s]        VAC1_ADC (int, mV) = 20                       (was    24)
[T+180.768s]        VAC2_ADC (int, mV) = 11888                    (was 11893)
[T+180.768s]        VBAT_ADC (int, mV) = 16406                    (was 16407)
[T+180.768s]        VSYS_ADC (int, mV) = 16425                    (was 16423)
Main stats: IN_DPM! NOT_PG! NO_AC1! +EN_OTG +EN_CHG CHG=[0]"Not Charging" 

[T+181.036s]      ADC_DONE_STAT (bool) = TRUE                                                   (was false)
[T+181.036s]             ADC_EN (bool) = false                                                  (was TRUE)
[T+181.036s]         TS_ADC (float, %) = 58.984                  (was 59.473)
[T+181.036s]       DPLUS_ADC (int, mV) = 43                       (was    47)
[T+181.036s]      DMINUS_ADC (int, mV) = 33                       (was    38)
Main stats: IN_DPM! NOT_PG! NO_AC1! +EN_OTG +EN_CHG CHG=[0]"Not Charging"

[T+210.776s]      ADC_DONE_STAT (bool) = false                                                  (was TRUE)
[T+210.776s]             ADC_EN (bool) = TRUE                                                   (was false)
[T+210.776s]        IBUS_ADC (int, mA) = -12                      (was   -13)
[T+210.776s]        IBAT_ADC (int, mA) = 0                        (was    -1)
[T+210.776s]        VBUS_ADC (int, mV) = 11912                    (was 11906)
[T+210.776s]        VAC1_ADC (int, mV) = 24                       (was    20)
[T+210.776s]        VAC2_ADC (int, mV) = 11893                    (was 11888)
[T+210.776s]        VBAT_ADC (int, mV) = 16399                    (was 16406)
[T+210.776s]        VSYS_ADC (int, mV) = 16422                    (was 16425)
Main stats: IN_DPM! NOT_PG! NO_AC1! +EN_OTG +EN_CHG CHG=[0]"Not Charging" 

[T+211.044s]      ADC_DONE_STAT (bool) = TRUE                                                   (was false)
[T+211.044s]             ADC_EN (bool) = false                                                  (was TRUE)
[T+211.044s]         TS_ADC (float, %) = 59.570                  (was 58.984)
[T+211.044s]    TDIE_ADC (float, degC) = 36.000                  (was 35.500)
[T+211.044s]       DPLUS_ADC (int, mV) = 38                       (was    43)
[T+211.044s]      DMINUS_ADC (int, mV) = 29                       (was    33)
Main stats: IN_DPM! NOT_PG! NO_AC1! +EN_OTG +EN_CHG CHG=[0]"Not Charging" 

[T+240.795s]      ADC_DONE_STAT (bool) = false                                                  (was TRUE)
[T+240.795s]             ADC_EN (bool) = TRUE                                                   (was false)
[T+240.795s]        IBUS_ADC (int, mA) = -13                      (was   -12)
[T+240.795s]        VBUS_ADC (int, mV) = 11908                    (was 11912)
[T+240.795s]        VAC1_ADC (int, mV) = 25                       (was    24)
[T+240.795s]        VAC2_ADC (int, mV) = 11891                    (was 11893)
[T+240.795s]        VBAT_ADC (int, mV) = 16408                    (was 16399)
[T+240.795s]        VSYS_ADC (int, mV) = 16421                    (was 16422)
Main stats: IN_DPM! NOT_PG! NO_AC1! +EN_OTG +EN_CHG CHG=[0]"Not Charging" 

[T+241.053s]      ADC_DONE_STAT (bool) = TRUE                                                   (was false)
[T+241.053s]             ADC_EN (bool) = false                                                  (was TRUE)
[T+241.053s]         TS_ADC (float, %) = 58.496                  (was 59.570)
[T+241.053s]    TDIE_ADC (float, degC) = 36.500                  (was 36.000)
[T+241.053s]       DPLUS_ADC (int, mV) = 34                       (was    38)
[T+241.053s]      DMINUS_ADC (int, mV) = 25                       (was    29)
Main stats: IN_DPM! NOT_PG! NO_AC1! +EN_OTG +EN_CHG CHG=[0]"Not Charging"

[T+270.808s]      ADC_DONE_STAT (bool) = false                                                  (was TRUE)
[T+270.808s]             ADC_EN (bool) = TRUE                                                   (was false)
[T+270.808s]        IBAT_ADC (int, mA) = -1                       (was     0)
[T+270.808s]        VAC1_ADC (int, mV) = 26                       (was    25)
[T+270.808s]        VAC2_ADC (int, mV) = 11893                    (was 11891)
[T+270.808s]        VBAT_ADC (int, mV) = 16399                    (was 16408)
[T+270.808s]        VSYS_ADC (int, mV) = 16422                    (was 16421)
Main stats: IN_DPM! NOT_PG! NO_AC1! +EN_OTG +EN_CHG CHG=[0]"Not Charging"

[T+271.066s]      ADC_DONE_STAT (bool) = TRUE                                                   (was false)
[T+271.066s]             ADC_EN (bool) = false                                                  (was TRUE)
[T+271.066s]         TS_ADC (float, %) = 58.008                  (was 58.496)
[T+271.066s]       DPLUS_ADC (int, mV) = 36                       (was    34)
[T+271.066s]      DMINUS_ADC (int, mV) = 29                       (was    25)
Main stats: IN_DPM! NOT_PG! NO_AC1! +EN_OTG +EN_CHG CHG=[0]"Not Charging" 

[T+300.866s]      ADC_DONE_STAT (bool) = false                                                  (was TRUE)
[T+300.866s]             ADC_EN (bool) = TRUE                                                   (was false)
[T+300.866s]        IBUS_ADC (int, mA) = -14                      (was   -13)
[T+300.866s]        VBUS_ADC (int, mV) = 11907                    (was 11908)
[T+300.866s]        VAC1_ADC (int, mV) = 23                       (was    26)
[T+300.866s]        VAC2_ADC (int, mV) = 11888                    (was 11893)
[T+300.866s]        VBAT_ADC (int, mV) = 16398                    (was 16399)
[T+300.866s]        VSYS_ADC (int, mV) = 16419                    (was 16422)
Main stats: IN_DPM! NOT_PG! NO_AC1! +EN_OTG +EN_CHG CHG=[0]"Not Charging"

[T+301.124s]      ADC_DONE_STAT (bool) = TRUE                                                   (was false)
[T+301.124s]             ADC_EN (bool) = false                                                  (was TRUE)
[T+301.124s]         TS_ADC (float, %) = 53.711                  (was 58.008)
[T+301.124s]    TDIE_ADC (float, degC) = 37.000                  (was 36.500)
[T+301.124s]       DPLUS_ADC (int, mV) = 37                       (was    36)
[T+301.124s]      DMINUS_ADC (int, mV) = 27                       (was    29)
Main stats: IN_DPM! NOT_PG! NO_AC1! +EN_OTG +EN_CHG CHG=[0]"Not Charging" 

[T+331.008s]      ADC_DONE_STAT (bool) = false                                                  (was TRUE)
[T+331.008s]             ADC_EN (bool) = TRUE                                                   (was false)
[T+331.008s]        IBUS_ADC (int, mA) = -49                      (was   -14)
[T+331.008s]        IBAT_ADC (int, mA) = -5                       (was    -1)
[T+331.008s]        VBUS_ADC (int, mV) = 11896                    (was 11907)
[T+331.008s]        VAC1_ADC (int, mV) = 31                       (was    23)
[T+331.008s]        VAC2_ADC (int, mV) = 11880                    (was 11888)
[T+331.008s]        VBAT_ADC (int, mV) = 15770                    (was 16398)
[T+331.008s]        VSYS_ADC (int, mV) = 15766                    (was 16419)
Main stats: IN_DPM! NOT_PG! NO_AC1! +EN_OTG +EN_CHG CHG=[0]"Not Charging" 

[T+331.276s]      ADC_DONE_STAT (bool) = TRUE                                                   (was false)
[T+331.276s]             ADC_EN (bool) = false                                                  (was TRUE)
[T+331.276s]         TS_ADC (float, %) = 54.785                  (was 53.711)
[T+331.276s]    TDIE_ADC (float, degC) = 36.000                  (was 37.000)
[T+331.276s]       DPLUS_ADC (int, mV) = 325                      (was    37)
[T+331.276s]      DMINUS_ADC (int, mV) = 279                      (was    27)
Main stats: IN_DPM! NOT_PG! NO_AC1! +EN_OTG +EN_CHG CHG=[0]"Not Charging" 

[T+349.832s]        VAC2_ADC (int, mV) = 11985                    (was 11880)
Main stats: IN_DPM! NOT_PG! NO_AC1! +EN_OTG +EN_CHG CHG=[0]"Not Charging"

[T+351.039s]            ICHG (int, mA) = 950                      (was  1000)
[T+351.039s]         IPRECHG (int, mA) = 0                        (was   120)
[T+351.039s]        VAC2_ADC (int, mV) = 11880                    (was 11985)
Main stats: IN_DPM! NOT_PG! NO_AC1! +EN_OTG +EN_CHG CHG=[0]"Not Charging"

[T+351.256s]            ICHG (int, mA) = 1000                     (was   950)
[T+351.256s]         IPRECHG (int, mA) = 120                      (was     0)
Main stats: IN_DPM! NOT_PG! NO_AC1! +EN_OTG +EN_CHG CHG=[0]"Not Charging" 

[T+355.068s]        VBUS_BACKUP (enum) = [0] "<40%(VINDPM)"                                     (was [2] "<80%(VINDPM)")
[T+355.068s]          EN_IINDPM (bool) = false                                                  (was TRUE)
Main stats: IN_DPM! NOT_PG! NO_AC1! +EN_OTG +EN_CHG CHG=[0]"Not Charging"

[T+355.284s]      EN_TRICHG_TMR (bool) = false                                                  (was TRUE)
[T+355.284s]        VBUS_BACKUP (enum) = [2] "<80%(VINDPM)"                                     (was [0] "<40%(VINDPM)")
[T+355.284s]          EN_IINDPM (bool) = TRUE                                                   (was false)
Main stats: IN_DPM! NOT_PG! NO_AC1! +EN_OTG +EN_CHG CHG=[0]"Not Charging"

[T+355.511s]      EN_TRICHG_TMR (bool) = TRUE                                                   (was false)
Main stats: IN_DPM! NOT_PG! NO_AC1! +EN_OTG +EN_CHG CHG=[0]"Not Charging" 

[T+355.716s]      EN_TRICHG_TMR (bool) = false                                                  (was TRUE)
[T+355.716s]           IBAT_REG (enum) = [0] "3A"                                               (was [3] "Disabled")
Main stats: IN_DPM! NOT_PG! NO_AC1! +EN_OTG +EN_CHG CHG=[0]"Not Charging" 

[T+356.933s]          VINDPM (int, mV) = 0                        (was 10500)
[T+356.933s]      EN_TRICHG_TMR (bool) = TRUE                                                   (was false)
[T+356.933s]           IBAT_REG (enum) = [3] "Disabled"                                         (was [0] "3A")
Main stats: IN_DPM! NOT_PG! NO_AC1! +EN_OTG +EN_CHG CHG=[0]"Not Charging"

[T+358.160s]          VINDPM (int, mV) = 10500                    (was     0)
[T+358.160s]        EN_IBUS_OCP (bool) = false                                                  (was TRUE)
Main stats: IN_DPM! NOT_PG! NO_AC1! +EN_OTG +EN_CHG CHG=[0]"Not Charging" 

[T+358.375s]        EN_IBUS_OCP (bool) = TRUE                                                   (was false)
[T+358.375s]        IBAT_ADC (int, mA) = 0                        (was    -5)
Main stats: IN_DPM! NOT_PG! NO_AC1! +EN_OTG +EN_CHG CHG=[0]"Not Charging" 

[T+358.592s]        IBAT_ADC (int, mA) = -5                       (was     0)
Main stats: IN_DPM! NOT_PG! NO_AC1! +EN_OTG +EN_CHG CHG=[0]"Not Charging"

[T+360.196s]         TS_ADC (float, %) = 0.000                   (was 54.785)
Main stats: IN_DPM! NOT_PG! NO_AC1! +EN_OTG +EN_CHG CHG=[0]"Not Charging"

[T+360.402s]         JEITA_VSET (enum) = [0] "Charge Suspend"                                   (was [3] "Set VREG to VREG-400mV (default)")
[T+360.402s]         TS_ADC (float, %) = 54.785                  (was 0.000)
Main stats: IN_DPM! NOT_PG! NO_AC1! +EN_OTG +EN_CHG CHG=[0]"Not Charging"

[T+360.619s]         JEITA_VSET (enum) = [3] "Set VREG to VREG-400mV (default)"                 (was [0] "Charge Suspend")
Main stats: IN_DPM! NOT_PG! NO_AC1! +EN_OTG +EN_CHG CHG=[0]"Not Charging" 

✅Po zvýšení zátěže (na 3 A?) se postupně zvedla teplota čipu až na 70 °C, což je ale naprosto v pohodě.

[T+362.035s]      ADC_DONE_STAT (bool) = false                                                  (was TRUE)
[T+362.035s]        IBUS_ADC (int, mA) = -178                     (was   -49)
[T+362.035s]        IBAT_ADC (int, mA) = -122                     (was    -5)
[T+362.035s]        VBUS_ADC (int, mV) = 11841                    (was 11896)
[T+362.035s]        VAC1_ADC (int, mV) = 74                       (was    31)
[T+362.035s]        VAC2_ADC (int, mV) = 11828                    (was 11880)
[T+362.035s]        VBAT_ADC (int, mV) = 14637                    (was 15770)
[T+362.035s]        VSYS_ADC (int, mV) = 14580                    (was 15766)
[T+362.035s]         TS_ADC (float, %) = 54.297                  (was 54.785)
[T+362.035s]    TDIE_ADC (float, degC) = 68.500                  (was 36.000)
[T+362.035s]       DPLUS_ADC (int, mV) = 445                      (was   325)
[T+362.035s]      DMINUS_ADC (int, mV) = 406                      (was   279)
Main stats: IN_DPM! NOT_PG! NO_AC1! +EN_OTG +EN_CHG CHG=[0]"Not Charging" 

[T+364.325s]        ICO_ILIM (int, mA) = 0                        (was   500)
[T+364.325s]      ADC_DONE_STAT (bool) = TRUE                                                   (was false)
Main stats: IN_DPM! NOT_PG! NO_AC1! +EN_OTG +EN_CHG CHG=[0]"Not Charging" 

[T+366.542s]               TREG (enum) = [0] "60'C"                                             (was [3] "120'C")
[T+366.542s]        ICO_ILIM (int, mA) = 500                      (was     0)
Main stats: IN_DPM! NOT_PG! NO_AC1! +EN_OTG +EN_CHG CHG=[0]"Not Charging" 

[T+367.758s]      EN_TRICHG_TMR (bool) = false                                                  (was TRUE)
[T+367.758s]               TREG (enum) = [3] "120'C"                                            (was [0] "60'C")
Main stats: IN_DPM! NOT_PG! NO_AC1! +EN_OTG +EN_CHG CHG=[0]"Not Charging"

[T+367.975s]      EN_TRICHG_TMR (bool) = TRUE                                                   (was false)
Main stats: IN_DPM! NOT_PG! NO_AC1! +EN_OTG +EN_CHG CHG=[0]"Not Charging" 

[T+369.974s]             EN_CHG (bool) = false                                                  (was TRUE)
Main stats: IN_DPM! NOT_PG! NO_AC1! +EN_OTG +EN_CHG CHG=[0]"Not Charging"

[T+370.180s]             EN_CHG (bool) = TRUE                                                   (was false)
[T+370.180s]         ACRB1_STAT (bool) = false                                                  (was TRUE)
Main stats: IN_DPM! NOT_PG! NO_AC1! +EN_OTG +EN_CHG CHG=[0]"Not Charging" 

[T+370.396s]         ACRB1_STAT (bool) = TRUE                                                   (was false)
Main stats: IN_DPM! NOT_PG! NO_AC1! +EN_OTG +EN_CHG CHG=[0]"Not Charging"

[T+374.582s]        IBAT_ADC (int, mA) = 0                        (was  -122)
Main stats: IN_DPM! NOT_PG! NO_AC1! +EN_OTG +EN_CHG CHG=[0]"Not Charging"

[T+374.788s]        IBAT_ADC (int, mA) = -122                     (was     0)
Main stats: IN_DPM! NOT_PG! NO_AC1! +EN_OTG +EN_CHG CHG=[0]"Not Charging" 

[T+388.739s]          IINDPM (int, mA) = 0                        (was  3000)
Main stats: IN_DPM! NO_AC1! +EN_OTG +EN_CHG CHG=[0]"Not Charging"

[T+396.944s]          IINDPM (int, mA) = 3000                     (was     0)
[T+396.944s]           ITERM (int, mA) = 0                        (was   200)
[T+396.944s]            CHG_TMR (enum) = [0] "5 hours"                                          (was [2] "12 hours")
[T+396.944s]            EN_IBAT (bool) = TRUE                                                   (was false)
[T+396.944s]         JEITA_VSET (enum) = [0] "Charge Suspend"                                   (was [3] "Set VREG to VREG-400mV (default)")
[T+396.944s]        JEITA_ISETH (enum) = [0] "Charge Suspend"                                   (was [3] "ICHG unchanged")
[T+396.944s]               BHOT (enum) = [0] "55'C"                                             (was [1] "60'C (default)")
[T+396.944s]      VAC1_OVP_FLAG (bool) = TRUE                                                   (was false)
[T+396.944s]        VBAT_ADC (int, mV) = 0                        (was 14637)
[T+396.944s]        VSYS_ADC (int, mV) = 0                        (was 14580)
Main stats: NOT_PG! NO_AC1! +EN_OTG +EN_CHG CHG=[0]"Not Charging" 

[T+400.231s]           ITERM (int, mA) = 200                      (was     0)
[T+400.231s]             TRECHG (enum) = [0] "64 ms"                                            (was [2] "1024 ms")
[T+400.231s]            CHG_TMR (enum) = [2] "12 hours"                                         (was [0] "5 hours")
[T+400.231s]            EN_TERM (bool) = false                                                  (was TRUE)
[T+400.231s]           PWM_FREQ (enum) = [0] "1.5 MHz"                                          (was [1] "750 kHz")
[T+400.231s]            EN_IBAT (bool) = false                                                  (was TRUE)
[T+400.231s]         EN_EXTILIM (bool) = false                                                  (was TRUE)
[T+400.231s]            VOC_PCT (enum) = [0] "0.5625"                                           (was [5] "0.875")
[T+400.231s]         JEITA_VSET (enum) = [3] "Set VREG to VREG-400mV (default)"                 (was [0] "Charge Suspend")
[T+400.231s]        JEITA_ISETH (enum) = [3] "ICHG unchanged"                                   (was [0] "Charge Suspend")
[T+400.231s]               BHOT (enum) = [1] "60'C (default)"                                   (was [0] "55'C")
[T+400.231s]        IBUS_ADC (int, mA) = -186                     (was  -178)
[T+400.231s]        IBAT_ADC (int, mA) = -124                     (was  -122)
[T+400.231s]        VBUS_ADC (int, mV) = 11850                    (was 11841)
[T+400.231s]        VAC1_ADC (int, mV) = 96                       (was    74)
[T+400.231s]        VAC2_ADC (int, mV) = 11833                    (was 11828)
[T+400.231s]        VBAT_ADC (int, mV) = 29183                    (was     0)
[T+400.231s]        VSYS_ADC (int, mV) = 14345                    (was     0)
[T+400.231s]    TDIE_ADC (float, degC) = 66.500                  (was 68.500)
[T+400.231s]       DPLUS_ADC (int, mV) = 511                      (was   445)
[T+400.231s]      DMINUS_ADC (int, mV) = 473                      (was   406)
Main stats: IN_DPM! NOT_PG! NO_AC1! +EN_OTG +EN_CHG CHG=[0]"Not Charging" 

[T+406.602s]            ICHG (int, mA) = 0                        (was  1000)
[T+406.602s]             TRECHG (enum) = [2] "1024 ms"                                          (was [0] "64 ms")
[T+406.602s]            VOTG (int, mV) = 2800                     (was 12000)
[T+406.602s]    EN_AUTO_IBATDIS (bool) = false                                                  (was TRUE)
[T+406.602s]            EN_TERM (bool) = TRUE                                                   (was false)
[T+406.602s]           PWM_FREQ (enum) = [1] "750 kHz"                                          (was [0] "1.5 MHz")
[T+406.602s]           IBAT_REG (enum) = [0] "3A"                                               (was [3] "Disabled")
[T+406.602s]         EN_EXTILIM (bool) = TRUE                                                   (was false)
[T+406.602s]            VOC_PCT (enum) = [5] "0.875"                                            (was [0] "0.5625")
[T+406.602s]         JEITA_VSET (enum) = [0] "Charge Suspend"                                   (was [3] "Set VREG to VREG-400mV (default)")
[T+406.602s]        JEITA_ISETH (enum) = [2] "Set ICHG to 40%* ICHG"                            (was [3] "ICHG unchanged")
[T+406.602s]        JEITA_ISETC (enum) = [0] "Charge Suspend"                                   (was [1] "Set ICHG to 20%* ICHG (default)")
[T+406.602s]        ICO_ILIM (int, mA) = 0                        (was   500)
[T+406.602s]      ADC_DONE_STAT (bool) = false                                                  (was TRUE)
[T+406.602s]        VBAT_ADC (int, mV) = 14404                    (was 29183)
[T+406.602s]        VSYS_ADC (int, mV) = 14340                    (was 14345)
Main stats: IN_DPM! NOT_PG! NO_AC1! +EN_OTG +EN_CHG CHG=[0]"Not Charging"

[T+407.952s]            ICHG (int, mA) = 1000                     (was     0)
[T+407.952s]            VOTG (int, mV) = 12000                    (was  2800)
[T+407.952s]    EN_AUTO_IBATDIS (bool) = TRUE                                                   (was false)
[T+407.952s]        VBUS_BACKUP (enum) = [0] "<40%(VINDPM)"                                     (was [2] "<80%(VINDPM)")
[T+407.952s]           IBAT_REG (enum) = [3] "Disabled"                                         (was [0] "3A")
[T+407.952s]        JEITA_ISETH (enum) = [3] "ICHG unchanged"                                   (was [2] "Set ICHG to 40%* ICHG")
[T+407.952s]        JEITA_ISETC (enum) = [1] "Set ICHG to 20%* ICHG (default)"                  (was [0] "Charge Suspend")
[T+407.952s]        ICO_ILIM (int, mA) = 500                      (was     0)
[T+407.952s]      ADC_DONE_STAT (bool) = TRUE                                                   (was false)
Main stats: IN_DPM! NOT_PG! NO_AC1! +EN_OTG +EN_CHG CHG=[0]"Not Charging" 

[T+408.231s]        VBUS_BACKUP (enum) = [2] "<80%(VINDPM)"                                     (was [0] "<40%(VINDPM)")
[T+408.231s]         JEITA_VSET (enum) = [3] "Set VREG to VREG-400mV (default)"                 (was [0] "Charge Suspend")
[T+408.231s]        ICO_ILIM (int, mA) = 0                        (was   500)
Main stats: IN_DPM! NOT_PG! NO_AC1! +EN_OTG +EN_CHG CHG=[0]"Not Charging"

[T+409.458s]        ICO_ILIM (int, mA) = 500                      (was     0)
Main stats: IN_DPM! NOT_PG! NO_AC1! +EN_OTG +EN_CHG CHG=[0]"Not Charging" 

[T+411.261s]  VBAT_PRESENT_STAT (enum) = [0] "VBAT NOT present"                                 (was [1] "VBAT present")
Main stats: IN_DPM! NOT_PG! NO_AC1! +EN_OTG +EN_CHG CHG=[0]"Not Charging" 

[T+412.479s]            VOC_PCT (enum) = [0] "0.5625"                                           (was [5] "0.875")
[T+412.479s]  VBAT_PRESENT_STAT (enum) = [1] "VBAT present"                                     (was [0] "VBAT NOT present")
Main stats: IN_DPM! NOT_PG! NO_AC1! +EN_OTG +EN_CHG CHG=[0]"Not Charging" 

[T+413.705s]            VOC_PCT (enum) = [5] "0.875"                                            (was [0] "0.5625")
[T+413.705s]               TREG (enum) = [0] "60'C"                                             (was [3] "120'C")
[T+413.705s]        VSYS_ADC (int, mV) = 0                        (was 14340)
Main stats: IN_DPM! NOT_PG! NO_AC1! +EN_OTG +EN_CHG CHG=[0]"Not Charging"

[T+413.932s]               TREG (enum) = [3] "120'C"                                            (was [0] "60'C")
[T+413.932s]        VSYS_ADC (int, mV) = 14340                    (was     0)
Main stats: IN_DPM! NOT_PG! NO_AC1! +EN_OTG +EN_CHG CHG=[0]"Not Charging"

[T+414.149s]            VOC_DLY (enum) = [3] "5s"                                               (was [2] "2s")
Main stats: IN_DPM! NOT_PG! NO_AC1! +EN_OTG +EN_CHG CHG=[0]"Not Charging"

[T+415.355s]            VOC_DLY (enum) = [2] "2s"                                               (was [3] "5s")
Main stats: IN_DPM! NOT_PG! NO_AC1! +EN_OTG +EN_CHG CHG=[0]"Not Charging" 

[T+416.760s]          EN_BACKUP (bool) = TRUE                                                   (was false)
Main stats: IN_DPM! NOT_PG! NO_AC1! +EN_OTG +EN_CHG CHG=[0]"Not Charging"

[T+416.966s]          EN_BACKUP (bool) = false                                                  (was TRUE)
Main stats: IN_DPM! NOT_PG! NO_AC1! +EN_OTG +EN_CHG CHG=[0]"Not Charging"

[T+417.370s]     DIS_VSYS_SHORT (bool) = TRUE                                                   (was false)
[T+417.370s]            VOC_PCT (enum) = [0] "0.5625"                                           (was [5] "0.875")
Main stats: IN_DPM! NOT_PG! NO_AC1! +EN_OTG +EN_CHG CHG=[0]"Not Charging"

[T+417.587s]     DIS_VSYS_SHORT (bool) = false                                                  (was TRUE)
[T+417.587s]            VOC_PCT (enum) = [5] "0.875"                                            (was [0] "0.5625")
Main stats: IN_DPM! NOT_PG! NO_AC1! +EN_OTG +EN_CHG CHG=[0]"Not Charging"

[T+418.003s]        VAC1_ADC (int, mV) = 0                        (was    96)
Main stats: IN_DPM! NOT_PG! NO_AC1! +EN_OTG +EN_CHG CHG=[0]"Not Charging"

[T+419.209s]        VAC1_ADC (int, mV) = 96                       (was     0)
Main stats: IN_DPM! NOT_PG! NO_AC1! +EN_OTG +EN_CHG CHG=[0]"Not Charging"

[T+419.416s]        VAC2_ADC (int, mV) = 0                        (was 11833)
Main stats: IN_DPM! NOT_PG! NO_AC1! +EN_OTG +EN_CHG CHG=[0]"Not Charging"

[T+422.623s]        VAC2_ADC (int, mV) = 11833                    (was     0)
Main stats: IN_DPM! NOT_PG! NO_AC1! +EN_OTG +EN_CHG CHG=[0]"Not Charging"

[T+423.028s]           PWM_FREQ (enum) = [0] "1.5 MHz"                                          (was [1] "750 kHz")
[T+423.028s]        VBUS_ADC (int, mV) = 11839                    (was 11850)
Main stats: IN_DPM! NOT_PG! NO_AC1! +EN_OTG +EN_CHG CHG=[0]"Not Charging" 

[T+423.244s]             EN_CHG (bool) = false                                                  (was TRUE)
[T+423.244s]           PWM_FREQ (enum) = [1] "750 kHz"                                          (was [0] "1.5 MHz")
[T+423.244s]        VBUS_ADC (int, mV) = 11850                    (was 11839)
Main stats: IN_DPM! NOT_PG! NO_AC1! +EN_OTG +EN_CHG CHG=[0]"Not Charging"

[T+424.471s]             EN_CHG (bool) = TRUE                                                   (was false)
Main stats: IN_DPM! NOT_PG! NO_AC1! +EN_OTG +EN_CHG CHG=[0]"Not Charging"

[T+426.273s]      DMINUS_ADC (int, mV) = 0                        (was   473)
Main stats: IN_DPM! NOT_PG! NO_AC1! +EN_OTG +EN_CHG CHG=[0]"Not Charging"

[T+428.479s]               TREG (enum) = [0] "60'C"                                             (was [3] "120'C")
[T+428.479s]       CHG_TMR_STAT (enum) = [1] "Safety timer expired"                             (was [0] "Normal")
Main stats: IN_DPM! NOT_PG! NO_AC1! +EN_OTG +EN_CHG CHG=[0]"Not Charging"

[T+428.696s]               TREG (enum) = [3] "120'C"                                            (was [0] "60'C")
[T+428.696s]      ADC_DONE_STAT (bool) = false                                                  (was TRUE)
[T+428.696s]       CHG_TMR_STAT (enum) = [0] "Normal"                                           (was [1] "Safety timer expired")
[T+428.696s]             ADC_EN (bool) = TRUE                                                   (was false)
[T+428.696s]        IBUS_ADC (int, mA) = -173                     (was  -186)
[T+428.696s]        IBAT_ADC (int, mA) = -117                     (was  -124)
[T+428.696s]        VBUS_ADC (int, mV) = 11841                    (was 11850)
[T+428.696s]        VAC1_ADC (int, mV) = 67                       (was    96)
[T+428.696s]        VAC2_ADC (int, mV) = 11826                    (was 11833)
[T+428.696s]        VBAT_ADC (int, mV) = 14571                    (was 14404)
[T+428.696s]        VSYS_ADC (int, mV) = 14515                    (was 14340)
[T+428.696s]      DMINUS_ADC (int, mV) = 473                      (was     0)
Main stats: IN_DPM! NOT_PG! NO_AC1! +EN_OTG +EN_CHG CHG=[0]"Not Charging"

❓Myslím že teď někdy byla zátěž přepnutá na 3,2 A:

[T+428.996s]      ADC_DONE_STAT (bool) = TRUE                                                   (was false)
[T+428.996s]             ADC_EN (bool) = false                                                  (was TRUE)
[T+428.996s]         TS_ADC (float, %) = 53.906                  (was 54.297)
[T+428.996s]    TDIE_ADC (float, degC) = 68.500                  (was 66.500)
[T+428.996s]       DPLUS_ADC (int, mV) = 453                      (was   511)
[T+428.996s]      DMINUS_ADC (int, mV) = 419                      (was   473)
Main stats: IN_DPM! NOT_PG! NO_AC1! +EN_OTG +EN_CHG CHG=[0]"Not Charging"

[T+429.442s]         JEITA_VSET (enum) = [0] "Charge Suspend"                                   (was [3] "Set VREG to VREG-400mV (default)")
Main stats: IN_DPM! NOT_PG! NO_AC1! +EN_OTG +EN_CHG CHG=[0]"Not Charging" 

[T+429.658s]         JEITA_VSET (enum) = [3] "Set VREG to VREG-400mV (default)"                 (was [0] "Charge Suspend")
Main stats: IN_DPM! NOT_PG! NO_VBUS! NO_AC1! +EN_OTG +EN_CHG CHG=[0]"Not Charging" 

[T+431.073s]      ADC_DONE_STAT (bool) = false                                                  (was TRUE)
Main stats: IN_DPM! NOT_PG! NO_VBUS! NO_AC1! +EN_OTG +EN_CHG CHG=[0]"Not Charging" 

[T+431.279s]      ADC_DONE_STAT (bool) = TRUE                                                   (was false)
Main stats: IN_DPM! NOT_PG! NO_AC1! +EN_OTG +EN_CHG CHG=[0]"Not Charging"

[T+433.485s]         TS_ADC (float, %) = 49.902                  (was 53.906)
Main stats: NOT_PG! NO_AC1! +EN_OTG +EN_CHG CHG=[0]"Not Charging" 

[T+433.691s]         TS_ADC (float, %) = 53.906                  (was 49.902)
Main stats: IN_DPM! NOT_PG! NO_AC1! +EN_OTG +EN_CHG CHG=[0]"Not Charging"

[T+433.897s]           ADC_RATE (enum) = [0] "Continuous"                                       (was [1] "One-shot")
[T+433.897s]        VAC2_ADC (int, mV) = 8191                     (was 11826)
[T+433.897s]         TS_ADC (float, %) = 53.027                  (was 53.906)
Main stats: IN_DPM! NOT_PG! NO_AC1! +EN_OTG +EN_CHG CHG=[0]"Not Charging"

[T+434.124s]           ADC_RATE (enum) = [1] "One-shot"                                         (was [0] "Continuous")
[T+434.124s]        VAC2_ADC (int, mV) = 11826                    (was  8191)
[T+434.124s]         TS_ADC (float, %) = 53.906                  (was 53.027)
Main stats: IN_DPM! NOT_PG! NO_AC1! +EN_OTG +EN_CHG CHG=[0]"Not Charging" 

[T+434.549s]         EN_EXTILIM (bool) = false                                                  (was TRUE)
[T+434.549s]           ADC_RATE (enum) = [0] "Continuous"                                       (was [1] "One-shot")
Main stats: IN_DPM! NOT_PG! NO_AC1! +EN_OTG +EN_CHG CHG=[0]"Not Charging"

[T+435.765s]            TS_COOL (enum) = [0] "5'C"                                              (was [1] "10'C (default)")
[T+435.765s]              BCOLD (enum) = [1] "-20'C"                                            (was [0] "-10'C (default)")
[T+435.765s]           ADC_RATE (enum) = [1] "One-shot"                                         (was [0] "Continuous")
[T+435.765s]         TS_ADC (float, %) = 0.000                   (was 53.906)
Main stats: IN_DPM! NOT_PG! NO_AC1! +EN_OTG +EN_CHG CHG=[0]"Not Charging"

[T+436.003s]         EN_EXTILIM (bool) = TRUE                                                   (was false)
[T+436.003s]            TS_COOL (enum) = [1] "10'C (default)"                                   (was [0] "5'C")
[T+436.003s]              BCOLD (enum) = [0] "-10'C (default)"                                  (was [1] "-20'C")
[T+436.003s]         TS_ADC (float, %) = 53.906                  (was 0.000)
Main stats: IN_DPM! NOT_PG! NO_AC1! +EN_OTG +EN_CHG CHG=[0]"Not Charging"

[T+458.813s]      ADC_DONE_STAT (bool) = false                                                  (was TRUE)
[T+458.813s]             ADC_EN (bool) = TRUE                                                   (was false)
[T+458.813s]        IBUS_ADC (int, mA) = -14                      (was  -173)
[T+458.813s]        IBAT_ADC (int, mA) = -2                       (was  -117)
[T+458.813s]        VBUS_ADC (int, mV) = 11909                    (was 11841)
[T+458.813s]        VAC1_ADC (int, mV) = 19                       (was    67)
[T+458.813s]        VAC2_ADC (int, mV) = 11894                    (was 11826)
[T+458.813s]        VBAT_ADC (int, mV) = 16192                    (was 14571)
[T+458.813s]        VSYS_ADC (int, mV) = 16204                    (was 14515)
Main stats: IN_DPM! NOT_PG! NO_AC1! +EN_OTG +EN_CHG CHG=[0]"Not Charging" 

[T+459.081s]      ADC_DONE_STAT (bool) = TRUE                                                   (was false)
[T+459.081s]             ADC_EN (bool) = false                                                  (was TRUE)
[T+459.081s]         TS_ADC (float, %) = 59.082                  (was 53.906)
[T+459.081s]    TDIE_ADC (float, degC) = 41.000                  (was 68.500)
[T+459.081s]       DPLUS_ADC (int, mV) = 47                       (was   453)
[T+459.081s]      DMINUS_ADC (int, mV) = 39                       (was   419)
Main stats: IN_DPM! NOT_PG! NO_AC1! +EN_OTG +EN_CHG CHG=[0]"Not Charging"

[T+488.832s]      ADC_DONE_STAT (bool) = false                                                  (was TRUE)
[T+488.832s]             ADC_EN (bool) = TRUE                                                   (was false)
[T+488.832s]        IBAT_ADC (int, mA) = 0                        (was    -2)
[T+488.832s]        VBUS_ADC (int, mV) = 11908                    (was 11909)
[T+488.832s]        VAC1_ADC (int, mV) = 23                       (was    19)
[T+488.832s]        VAC2_ADC (int, mV) = 11892                    (was 11894)
[T+488.832s]        VBAT_ADC (int, mV) = 16243                    (was 16192)
[T+488.832s]        VSYS_ADC (int, mV) = 16261                    (was 16204)
Main stats: IN_DPM! NOT_PG! NO_AC1! +EN_OTG +EN_CHG CHG=[0]"Not Charging" 

[T+489.090s]      ADC_DONE_STAT (bool) = TRUE                                                   (was false)
[T+489.090s]             ADC_EN (bool) = false                                                  (was TRUE)
[T+489.090s]         TS_ADC (float, %) = 59.570                  (was 59.082)
[T+489.090s]    TDIE_ADC (float, degC) = 40.000                  (was 41.000)
[T+489.090s]       DPLUS_ADC (int, mV) = 49                       (was    47)
[T+489.090s]      DMINUS_ADC (int, mV) = 43                       (was    39)
Main stats: IN_DPM! NOT_PG! NO_AC1! +EN_OTG +EN_CHG CHG=[0]"Not Charging"

[T+505.919s]             EN_HIZ (bool) = TRUE                                                   (was false)
[T+505.919s]             EN_OTG (bool) = false                                                  (was TRUE)
[T+505.919s]           PWM_FREQ (enum) = [0] "1.5 MHz"                                          (was [1] "750 kHz")
[T+505.919s]        EN_IBUS_OCP (bool) = false                                                  (was TRUE)
[T+505.919s]           IBAT_REG (enum) = [0] "3A"                                               (was [3] "Disabled")
[T+505.919s]          EN_IINDPM (bool) = false                                                  (was TRUE)
[T+505.919s]         EN_EXTILIM (bool) = false                                                  (was TRUE)
[T+505.919s]            VOC_PCT (enum) = [0] "0.5625"                                           (was [5] "0.875")
[T+505.919s]            VOC_DLY (enum) = [0] "50ms"                                             (was [2] "2s")
[T+505.919s]           VOC_RATE (enum) = [0] "30s"                                              (was [2] "10min")
[T+505.919s]               TREG (enum) = [0] "60'C"                                             (was [3] "120'C")
[T+505.919s]         JEITA_VSET (enum) = [0] "Charge Suspend"                                   (was [3] "Set VREG to VREG-400mV (default)")
[T+505.919s]        JEITA_ISETH (enum) = [0] "Charge Suspend"                                   (was [3] "ICHG unchanged")
[T+505.919s]        JEITA_ISETC (enum) = [0] "Charge Suspend"                                   (was [1] "Set ICHG to 20%* ICHG (default)")
[T+505.919s]            TS_COOL (enum) = [0] "5'C"                                              (was [1] "10'C (default)")
[T+505.919s]            TS_WARM (enum) = [0] "40'C"                                             (was [1] "45'C (default)")
[T+505.919s]               BHOT (enum) = [0] "55'C"                                             (was [1] "60'C (default)")
[T+505.919s]        ICO_ILIM (int, mA) = 0                        (was   500)
[T+505.919s]        VINDPM_STAT (enum) = [0] "Normal"                                           (was [1] "In VINDPM regulation or VOTG regulation")
[T+505.919s]   AC2_PRESENT_STAT (enum) = [0] "VAC2 NOT present"                                 (was [1] "VAC2 present (above present threshold)")
[T+505.919s]  VBUS_PRESENT_STAT (enum) = [0] "VBUS NOT present"                                 (was [1] "VBUS present (above present threshold)")
[T+505.919s]          VBUS_STAT (enum) = [0] "No Input or BHOT or BCOLD in OTG mode"            (was [7] "In OTG mode")
[T+505.919s]  VBAT_PRESENT_STAT (enum) = [0] "VBAT NOT present"                                 (was [1] "VBAT present")
[T+505.919s]         ACRB1_STAT (bool) = false                                                  (was TRUE)
[T+505.919s]      ADC_DONE_STAT (bool) = false                                                  (was TRUE)
[T+505.919s]           ADC_RATE (enum) = [0] "Continuous"                                       (was [1] "One-shot")
[T+505.919s]        IBUS_ADC (int, mA) = 0                        (was   -14)
[T+505.919s]        VBUS_ADC (int, mV) = 0                        (was 11908)
[T+505.919s]        VAC1_ADC (int, mV) = 0                        (was    23)
[T+505.919s]        VAC2_ADC (int, mV) = 0                        (was 11892)
[T+505.919s]        VBAT_ADC (int, mV) = 0                        (was 16243)
[T+505.919s]        VSYS_ADC (int, mV) = 0                        (was 16261)
[T+505.919s]         TS_ADC (float, %) = 0.000                   (was 59.570)
[T+505.919s]    TDIE_ADC (float, degC) = 0.000                   (was 40.000)
[T+505.919s]       DPLUS_ADC (int, mV) = 0                        (was    49)
[T+505.919s]      DMINUS_ADC (int, mV) = 0                        (was    43)
[T+505.919s]                 PN (enum) = [0] "?"                                                (was [3] "BQ25798")
[T+505.919s]            DEV_REV (enum) = [0] "?"                                                (was [1] "BQ25798")
Main stats: NOT_PG! NO_VBUS! NO_AC1! NO_VBAT! CHG=[0]"Not Charging"

[T+506.401s]         VSYSMIN (int, mV) = 2500                     (was 12000)
[T+506.401s]            VREG (int, mV) = 0                        (was 16800)
[T+506.401s]            ICHG (int, mA) = 0                        (was  1000)
[T+506.401s]          VINDPM (int, mV) = 0                        (was 10500)
[T+506.401s]          IINDPM (int, mA) = 0                        (was  3000)
[T+506.401s]          VBAT_LOWV (enum) = [0] "15%(VREG)"                                        (was [3] "71.4%(VREG)")
[T+506.401s]         IPRECHG (int, mA) = 0                        (was   120)
[T+506.401s]           ITERM (int, mA) = 0                        (was   200)
[T+506.401s]               CELL (enum) = [0] "1S"                                               (was [3] "4S")
[T+506.401s]             TRECHG (enum) = [0] "64 ms"                                            (was [2] "1024 ms")
[T+506.401s]          VRECHG (int, mV) = 50                       (was   200)
[T+506.401s]            VOTG (int, mV) = 2800                     (was 12000)
[T+506.401s]            IOTG (int, mA) = 0                        (was  3000)
[T+506.401s]      EN_TRICHG_TMR (bool) = false                                                  (was TRUE)
[T+506.401s]      EN_PRECHG_TMR (bool) = false                                                  (was TRUE)
[T+506.401s]         EN_CHG_TMR (bool) = false                                                  (was TRUE)
[T+506.401s]            CHG_TMR (enum) = [0] "5 hours"                                          (was [2] "12 hours")
[T+506.401s]           TMR2X_EN (bool) = false                                                  (was TRUE)
[T+506.401s]    EN_AUTO_IBATDIS (bool) = false                                                  (was TRUE)
[T+506.401s]             EN_CHG (bool) = false                                                  (was TRUE)
[T+506.401s]             EN_HIZ (bool) = false                                                  (was TRUE)
[T+506.401s]            EN_TERM (bool) = false                                                  (was TRUE)
[T+506.401s]        VBUS_BACKUP (enum) = [0] "<40%(VINDPM)"                                     (was [2] "<80%(VINDPM)")
[T+506.401s]           WATCHDOG (enum) = [0] "Disabled"                                         (was [5] "40s")
[T+506.401s]      AUTO_INDET_EN (bool) = false                                                  (was TRUE)
[T+506.401s]          DIS_ACDRV (bool) = false                                                  (was TRUE)
Main stats: NOT_PG! NO_VBUS! NO_AC1! NO_VBAT! CHG=[0]"Not Charging" 
```

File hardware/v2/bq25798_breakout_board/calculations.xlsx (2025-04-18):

VSYS | 16.8 | V
VBUS | 12 | V
Fsw | 750000 | Hz
L | 2.2e-05 | H | inductor
I_ripple_buck | -0.4072727273 | A
I_ripple_boost | 0.2077922078 | A
I_ripple_max | 0.4072727273 | A
I_in | 3.5 | A
I_chg | 2 | A
I_sat | 3.703636364 | A

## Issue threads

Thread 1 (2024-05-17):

Ideas for V3

misch2, 2024-05-17:
Because the V1 works but for small currents only and the V2 failed, I'm considering a new approach:

1. Use 4S 18650 to achieve 12.8 - 16.8 V which could then be connected to a much more efficient buck (step down) converter
2. Power the whole thing from 19 V or 24 V source, eliminating a need for boost converter charger
3. Use CC/CV capable buck DC-DC converter + BMS to charge the battries. The converter will take care of charging, BMS will protect the batteries.
4. Use 2nd buck converter on the output to produce 12 V (with >= 3A) from batteries
5. Use P-type MOSFET to control batteries output (to prevent continuous load sharing)
6. Optionally generate additional output voltages if needed (9V or 5V etc.), always with it's own additional buck converter.

misch2, 2024-05-17:
For example this step down https://www.laskakit.cz/step-down-menic-s-xl4016e1/ should handle up to 8A and convert 24V to anything between 2V - 22V.

Alwo with 24V / 16.8 V / 12V combo there's no need for a MOSFET to prevent load sharing: when powered the D2 diode has always 24V on cathode and <24V on anode and it won't conduct. Only when the input power drops below the battery voltage the D2 will turn on.

misch2, 2024-05-17:
Updated schematic:
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

misch2, 2024-05-18:
⚠️ Don't forget that IRF5210 (and almost any other MOSFET) has |Vgs(max)| < 20V.

⚠️ CC/CV buck converter has a separate GND on IN vs OUT. There's a shunt resistor between them and it *must not* be clamped otherwise the CC won't work. Separate GND1 and GND2 must be used there!

Simulation for controlling the IRF5210 using 3.3V source:
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

This should be within a safe Vgs range.

misch2, 2024-05-18:
Good point on CCCV modules with isolated ground: https://forum.arduino.cc/t/using-constant-current-buck-converter-with-common-ground/861109/4

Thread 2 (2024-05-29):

[V2] UPS powering off prematurely when on battery

misch2, 2024-05-29:
Step up module: https://www.aliexpress.com/item/1005004596697480.html

Its description says "2-24v to 3-30v 4A 80w CC CV".

On a lab bench supply it was able to produce 12 V / 3 A from 6.8 V input.

When used in UPS and powered from Li-Ion 3000 mAh battries the results are:

Output current | Output voltage | Battery current | Battery voltage
--- | --- | --- | ----
0.01 A | 12 V | - | -
0.5 A | 11.68 V | -0.86 A | 7.78 V
1.0 A | 11.45 V | -1.83 A | 7.5 V
1.5 A | 11.33 V | -2.95 A | 7.15 V
2.0 A | 11.15 V | -4.22 A | 6.78 V
2.5 A | 11.04 V | -5.76 A | 6.42 V
2.9 A | 10.99 V | -7.86 A | 5.8 V
3 A | - | it turns off | (even when I add a capacitor to the output)

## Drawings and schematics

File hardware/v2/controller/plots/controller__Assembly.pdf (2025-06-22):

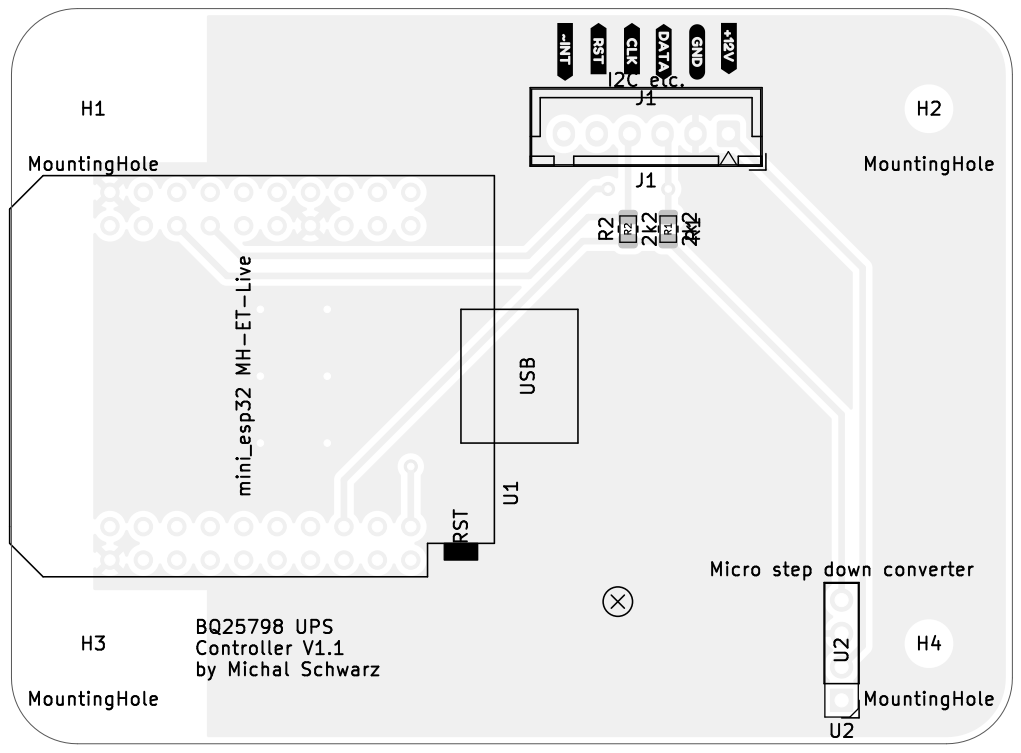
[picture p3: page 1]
BQ25798 UPS Controller V1.1 by Michal Schwarz; U2 U¹ RST; USB; D Date: KiCad; E.D.A. 8.0.2 Size: A4; Rev:; Id: 1/1 Title: File: controller.kicad_pcb Sheet: Black; And; White; TOP; Board2Pdf:; Black; TOP -; Page; MountingHole H2 2k2R¹ MountingHole H3; I2C etc. J1; Micro step down converter U² MountingHole H1; MountingHole H4 mini_esp32 MH⁻ET⁻Live

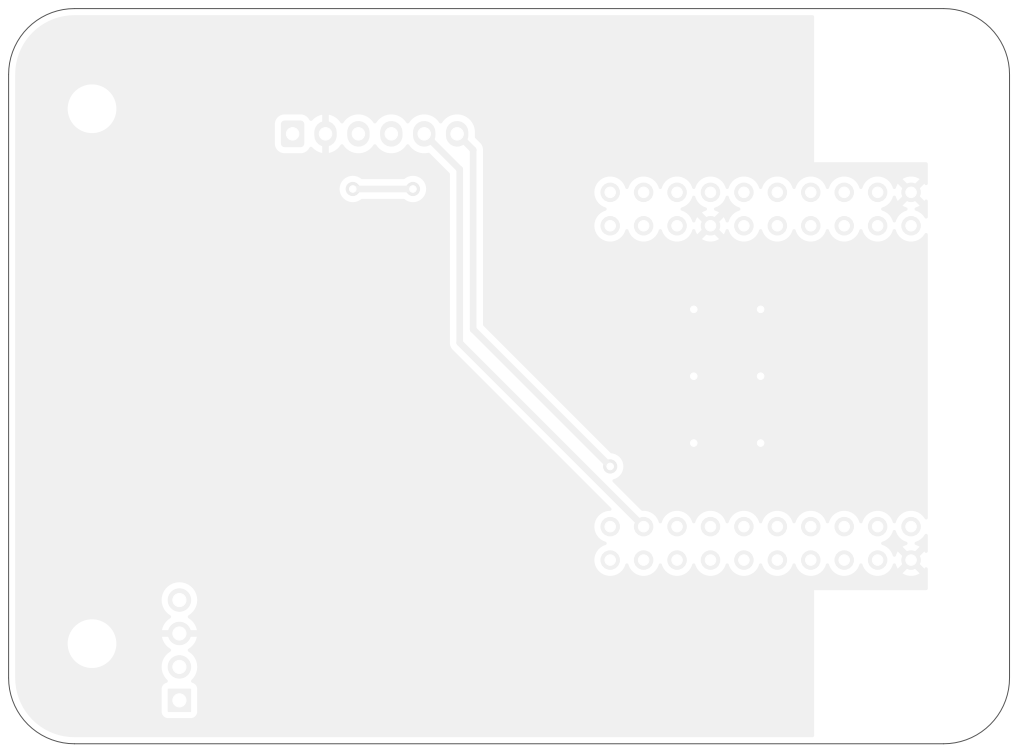
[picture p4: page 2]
D Date: KiCad; E.D.A. 8.0.2 Size: A4; Rev:; Id: 1/1 Title: File: controller.kicad_pcb Sheet: Black; And; White; BOT Board2Pdf:; Black; BOT -; Page 2/2

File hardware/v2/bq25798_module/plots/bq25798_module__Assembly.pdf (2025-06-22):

## TP1 Battery J3

# D2 47u low ESR

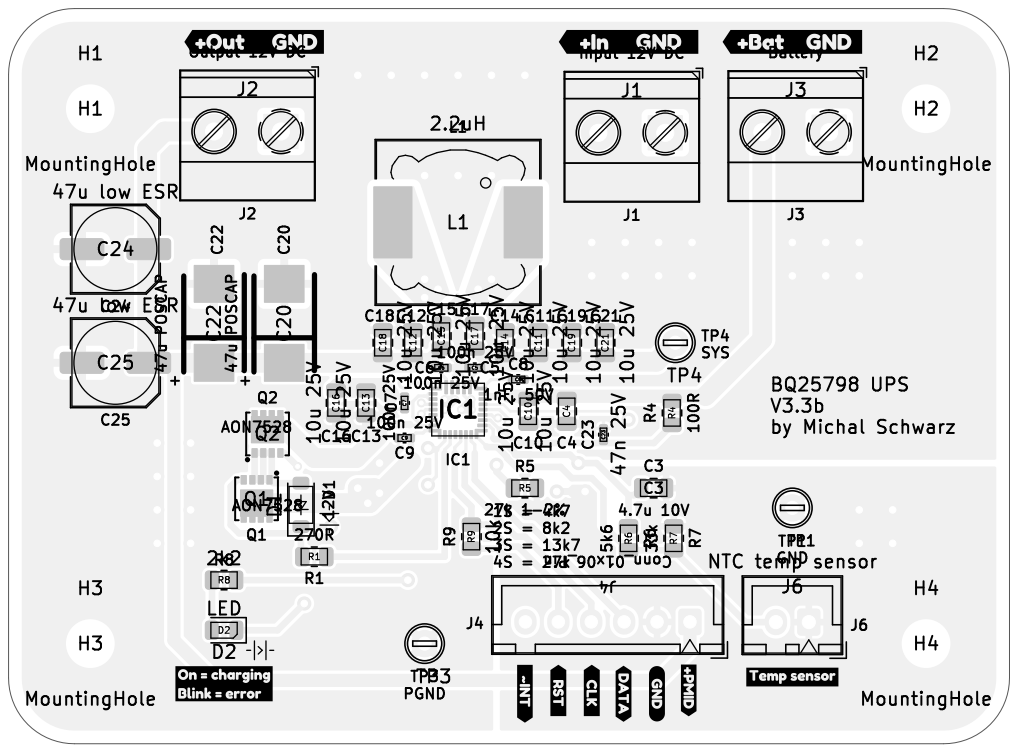
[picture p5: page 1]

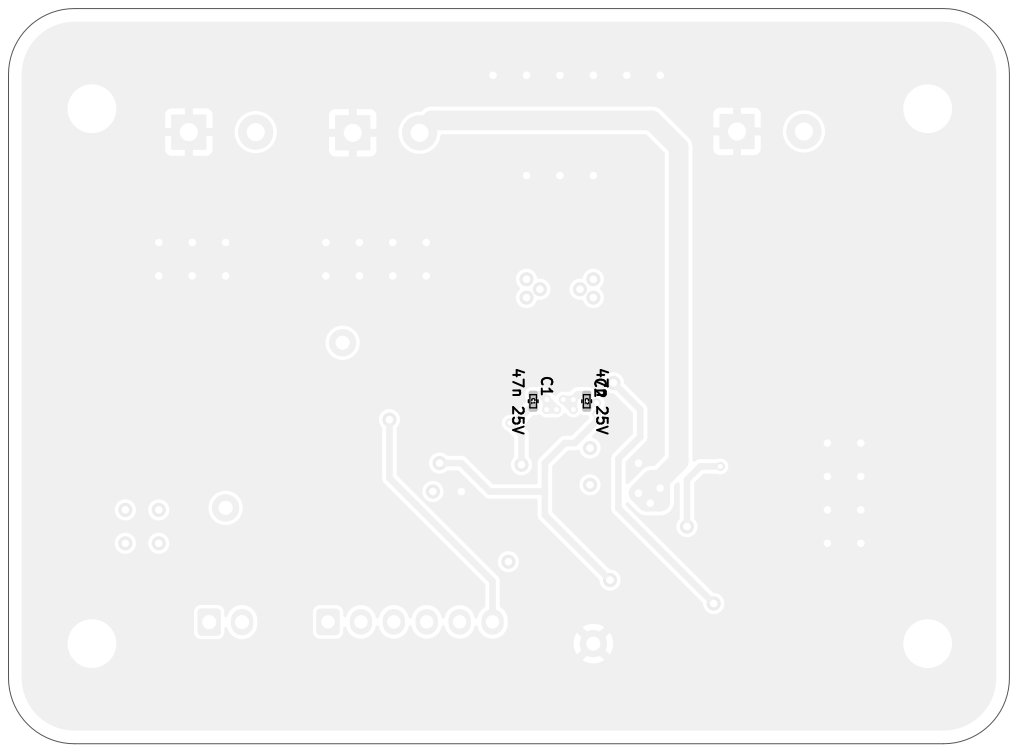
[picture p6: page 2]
D Date: KiCad; E.D.A. 8.0.2 Size: A4; Rev:; Id: 1/1 Title: File: bq25798_module.kicad_pcb Sheet: Black; And; White; BOT Board2Pdf:; Black; BOT -; Page 2/2 ⁴⁷n 25V C2 47n 25V C1

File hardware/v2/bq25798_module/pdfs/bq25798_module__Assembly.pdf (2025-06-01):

## TP1 Battery J3

# D2 47u low ESR

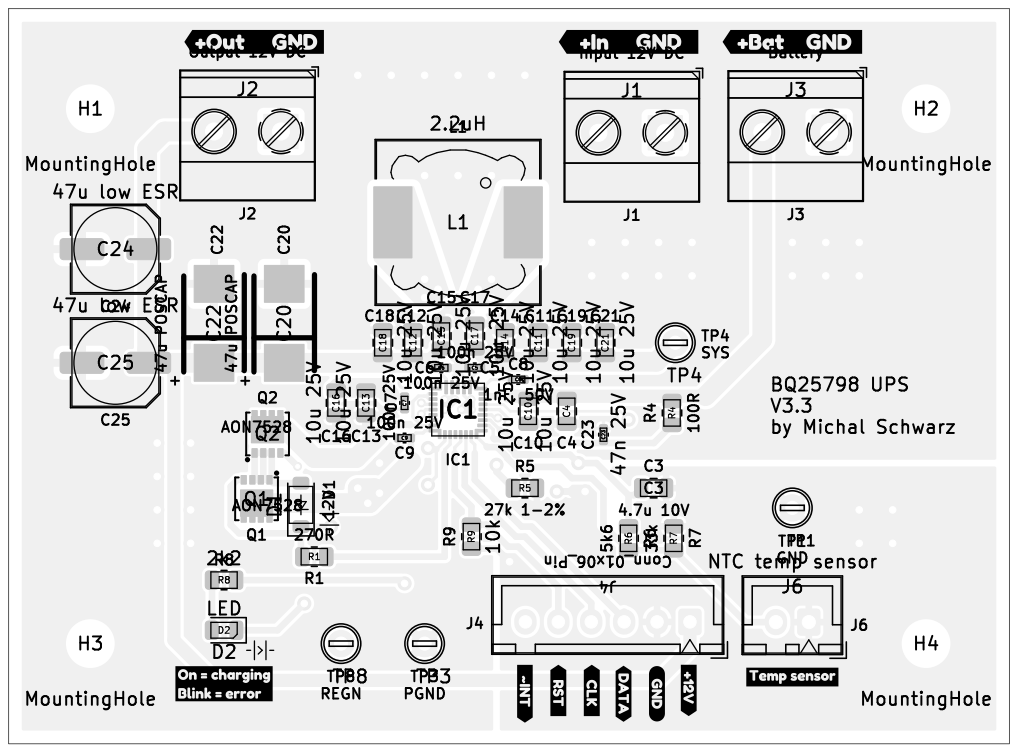
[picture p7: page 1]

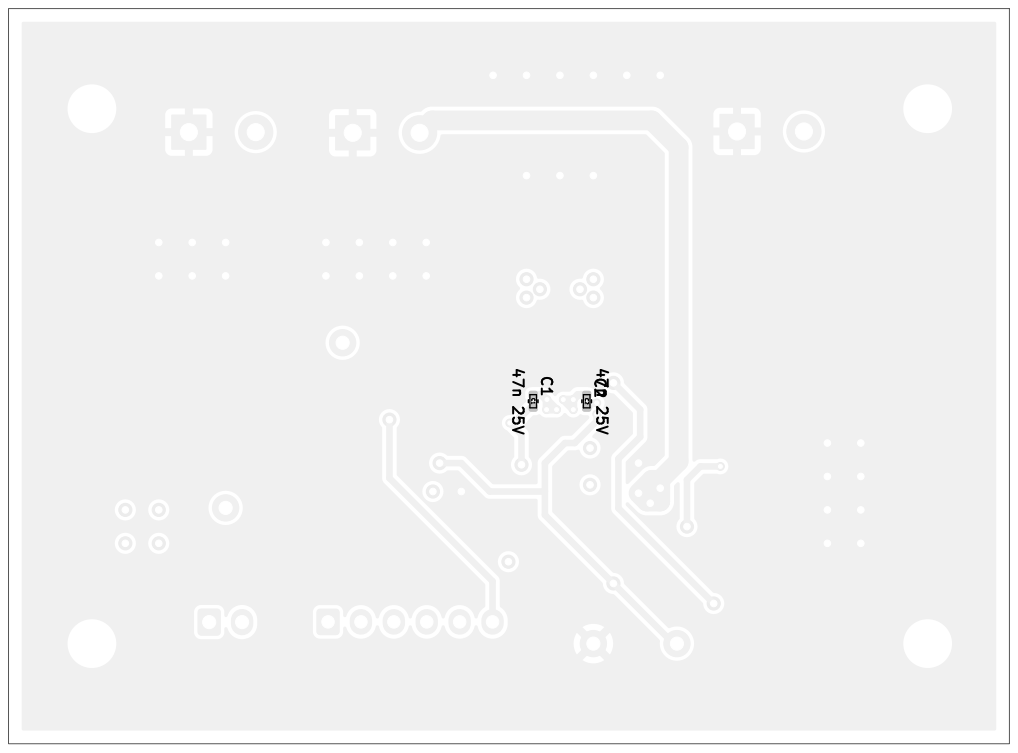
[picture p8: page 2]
D Date: KiCad; E.D.A. 8.0.2 Size: A4; Rev:; Id: 1/1 Title: File: bq25798_module.kicad_pcb Sheet: Black; And; White; BOT Board2Pdf:; Black; BOT -; Page 2/2 ⁴⁷n 25V C2 47n 25V C1

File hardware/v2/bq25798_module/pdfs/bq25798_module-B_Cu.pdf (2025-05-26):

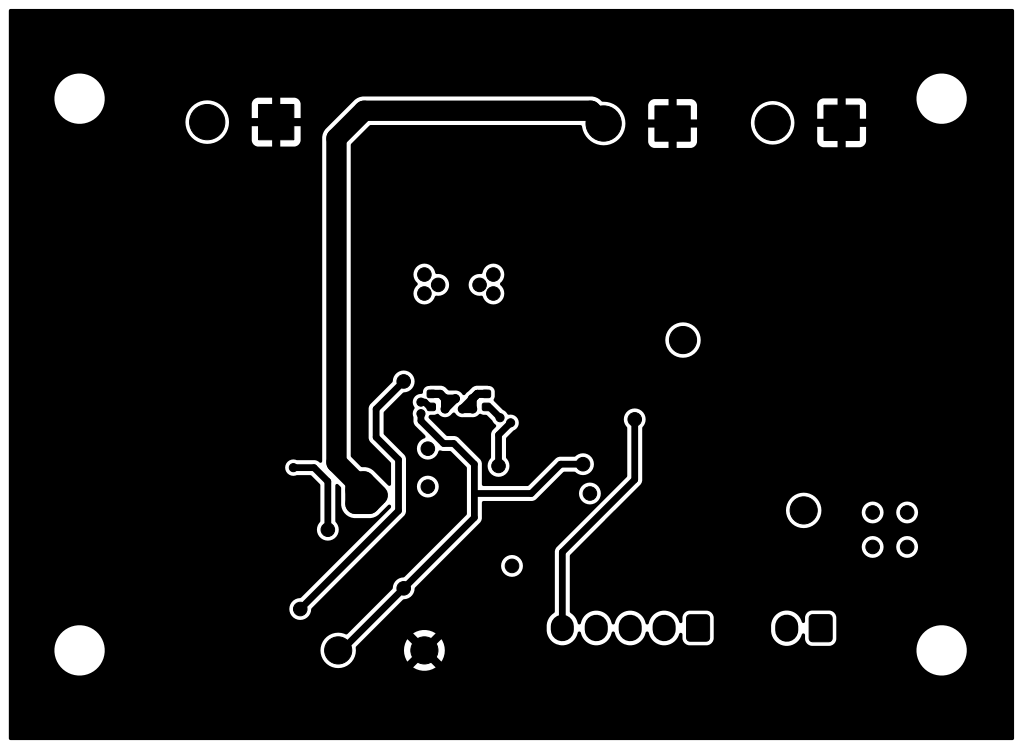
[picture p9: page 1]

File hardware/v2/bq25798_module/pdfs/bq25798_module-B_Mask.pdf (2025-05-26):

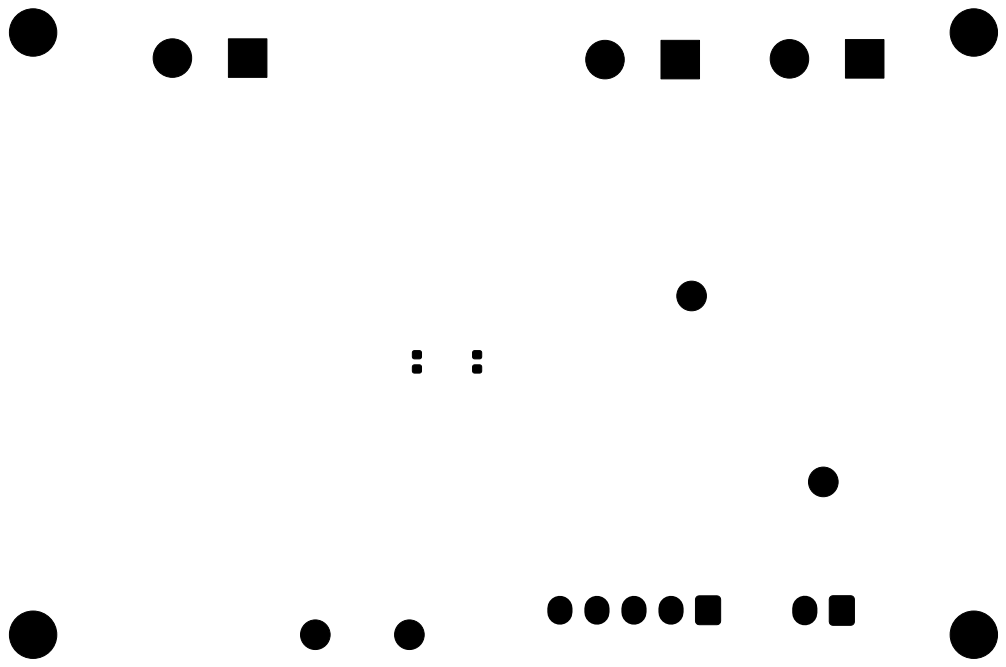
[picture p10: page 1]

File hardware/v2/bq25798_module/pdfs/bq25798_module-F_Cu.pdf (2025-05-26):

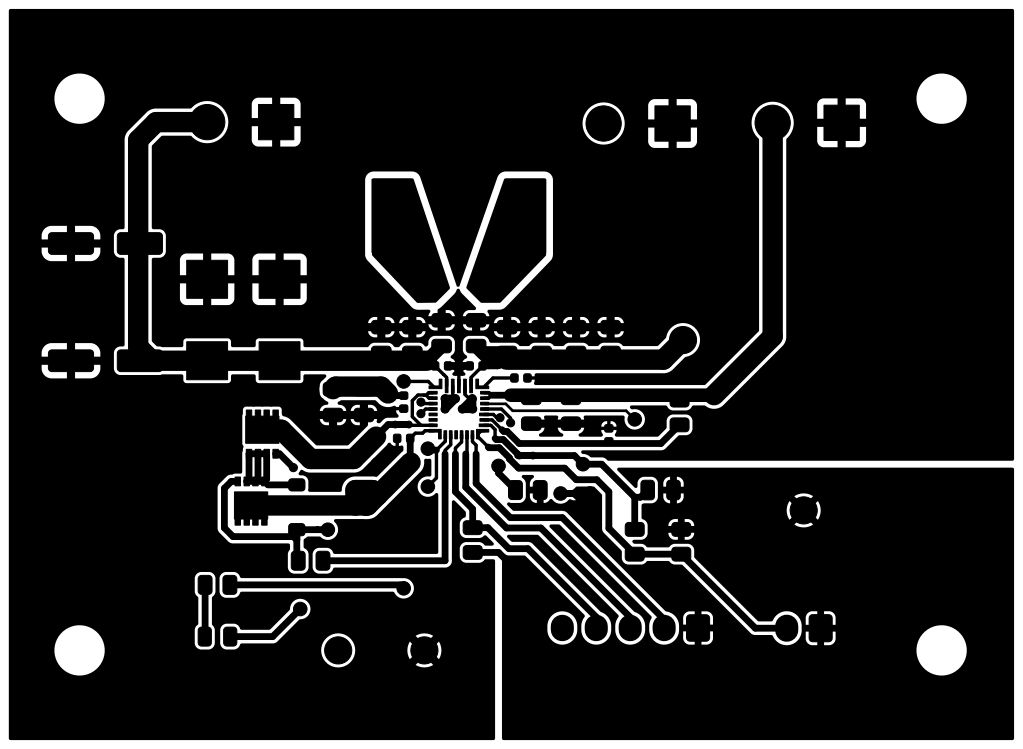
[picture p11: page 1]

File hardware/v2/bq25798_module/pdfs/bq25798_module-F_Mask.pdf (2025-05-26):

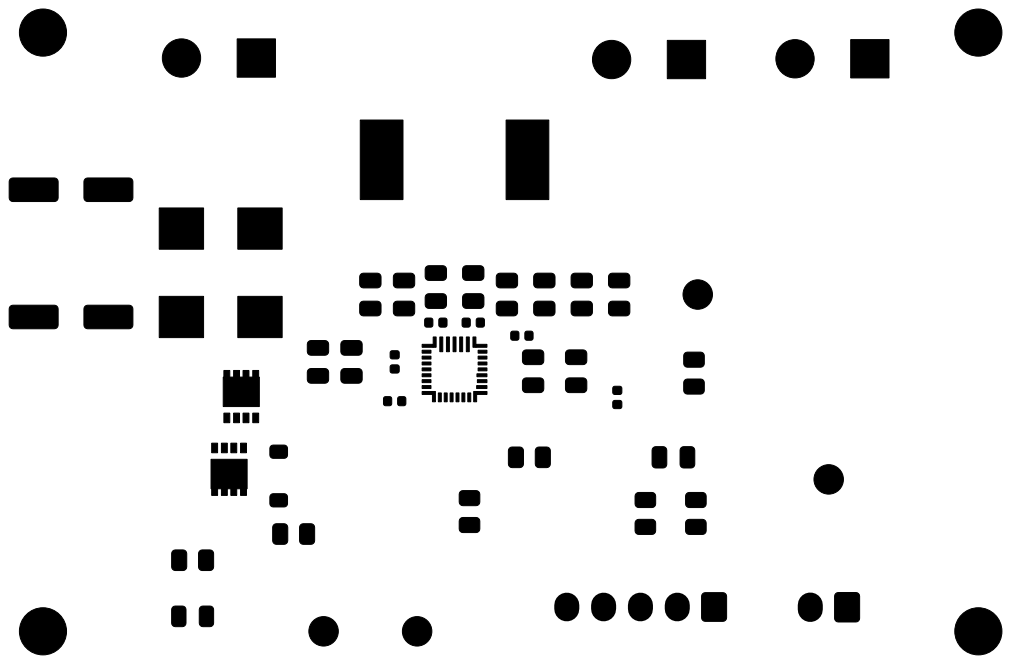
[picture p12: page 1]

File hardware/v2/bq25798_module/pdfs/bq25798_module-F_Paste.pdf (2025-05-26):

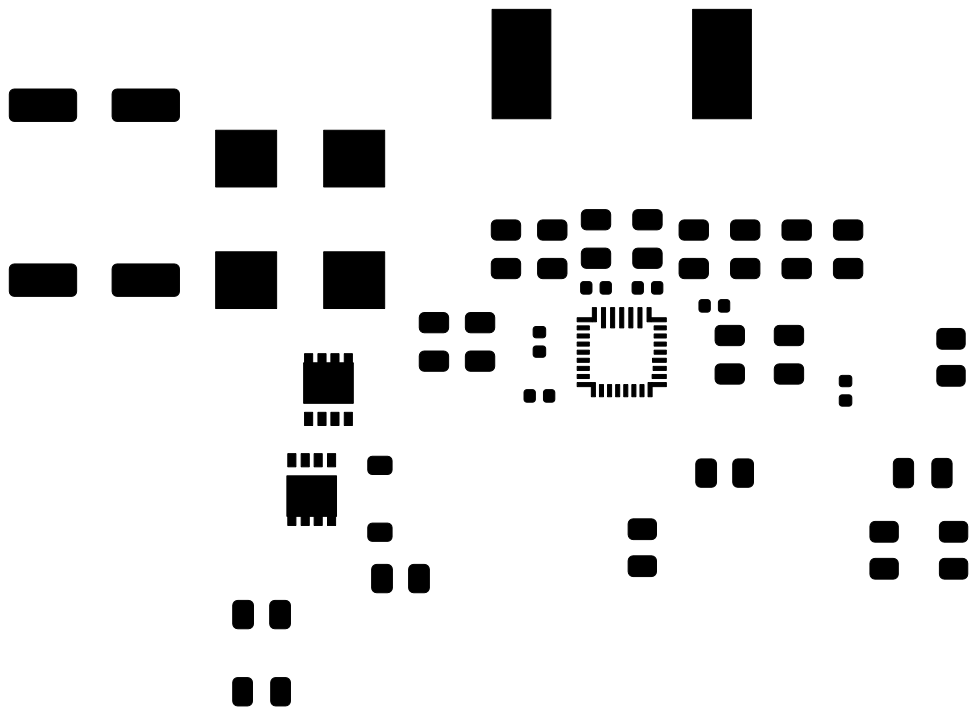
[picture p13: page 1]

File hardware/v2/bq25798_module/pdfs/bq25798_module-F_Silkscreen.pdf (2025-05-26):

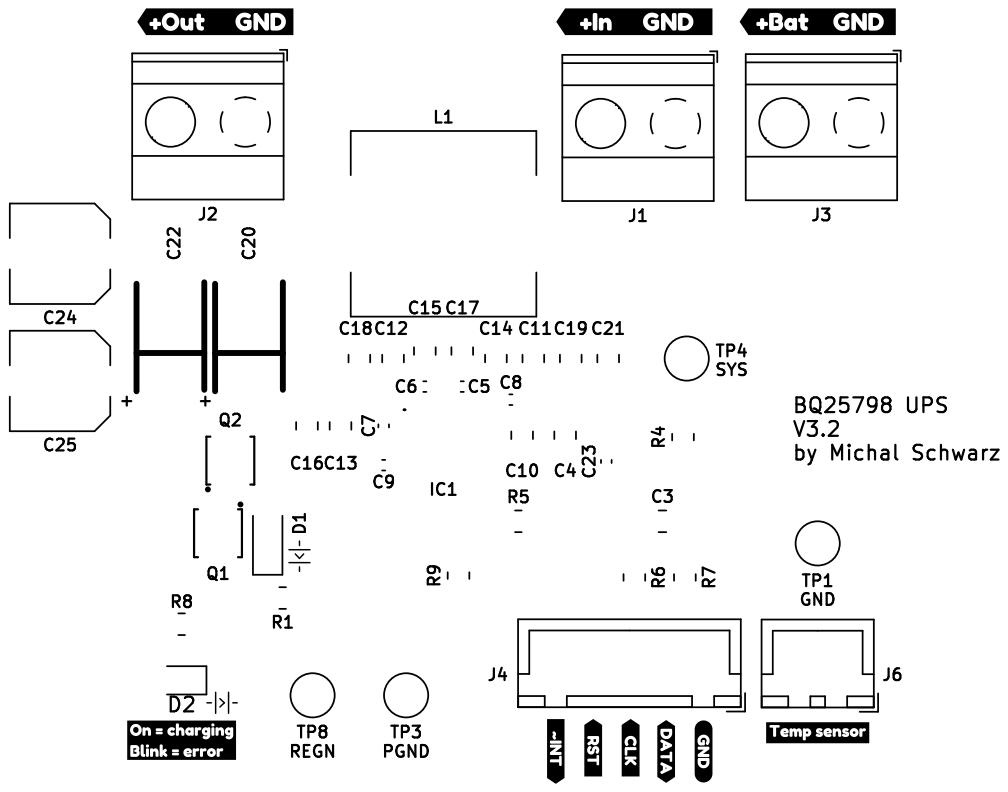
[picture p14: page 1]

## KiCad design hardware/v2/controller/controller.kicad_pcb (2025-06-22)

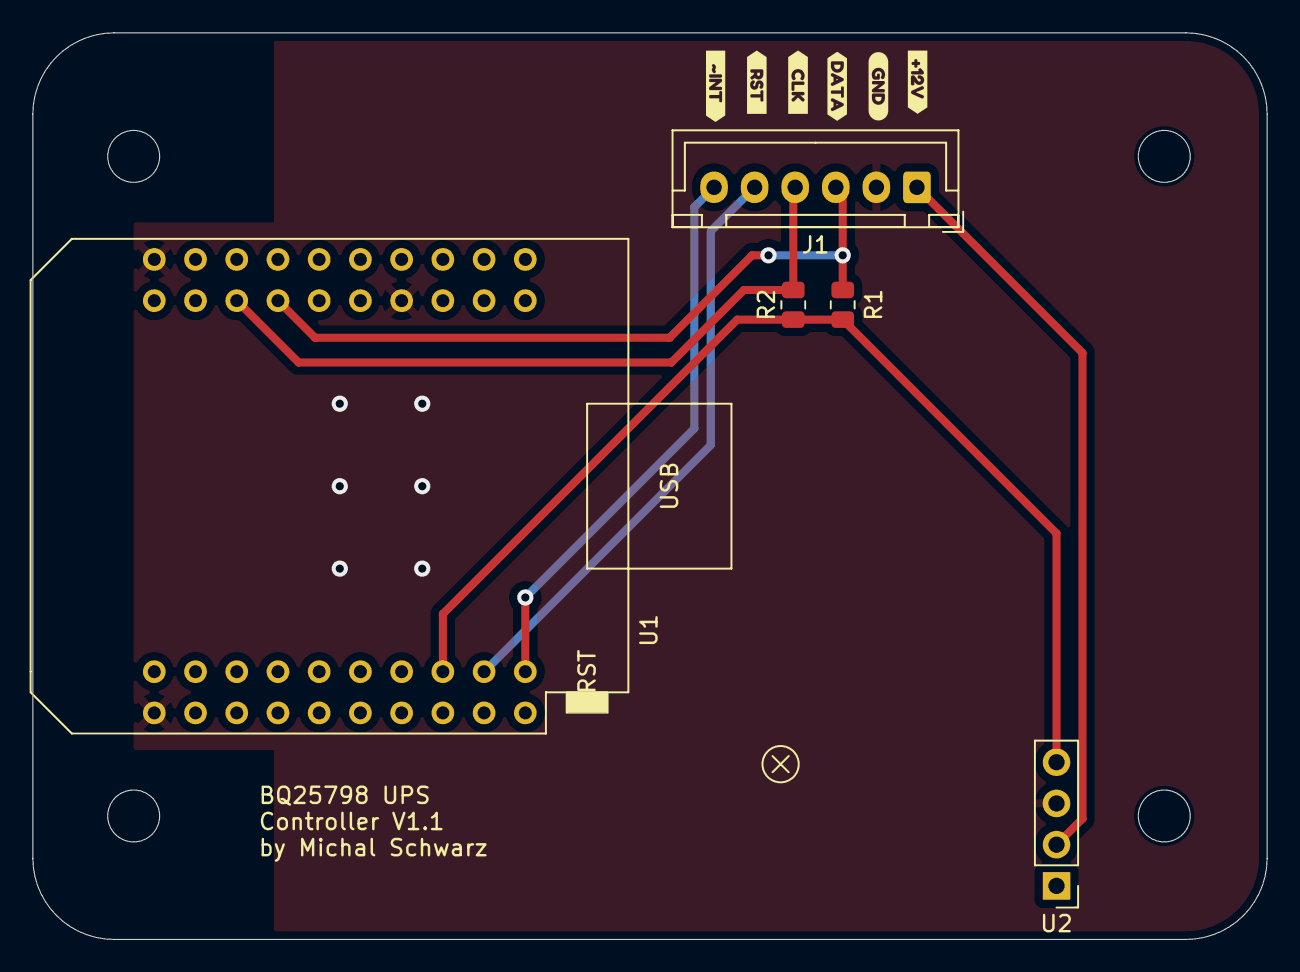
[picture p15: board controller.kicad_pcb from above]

Board: 2 copper layers, 76.0 x 55.9 mm, 15 parts (0 on the bottom side), 7 nets.

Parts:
H1, H2, H3, H4: MountingHole; MountingHole_3.2mm_M3
J1: I2C etc.; JST_XH_B6B-XH-A_1x06_P2.50mm_Vertical
R1, R2: 2k2; R_0805_2012Metric
U1: mini_esp32 MH-ET-Live; ESP32_mini MH-ET-LIVE
U2: Micro step down converter; Micro stepdown converter
kibuzzard-683D9CD5: G***; kibuzzard-683D9CD5
kibuzzard-6810EFE9: G***; kibuzzard-6810EFE9
kibuzzard-6810F0BF: G***; kibuzzard-6810F0BF
kibuzzard-6810F0CD: G***; kibuzzard-6810F0CD
kibuzzard-6810F0D5: G***; kibuzzard-6810F0D5
kibuzzard-6810F062: G***; kibuzzard-6810F062

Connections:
3V3: R1.1, R2.1, U1.16 (3V3), U2.4 (OUT)
/I2C_SCL: J1.4, R2.2, U1.25 (IO_22/D1/SCL)
/I2C_SDA: J1.3, R1.2, U1.27 (IO_21/D2/SDA)
/PWR_IN: J1.1, U2.2 (IN)
/~INT: J1.6, U1.20 (IO_10/SD3)
/~RST: J1.5, U1.18 (IO_13/TCK)
GND: J1.2, U1.1 (GND), U1.22 (GND), U1.33 (GND), U2.3 (GND)

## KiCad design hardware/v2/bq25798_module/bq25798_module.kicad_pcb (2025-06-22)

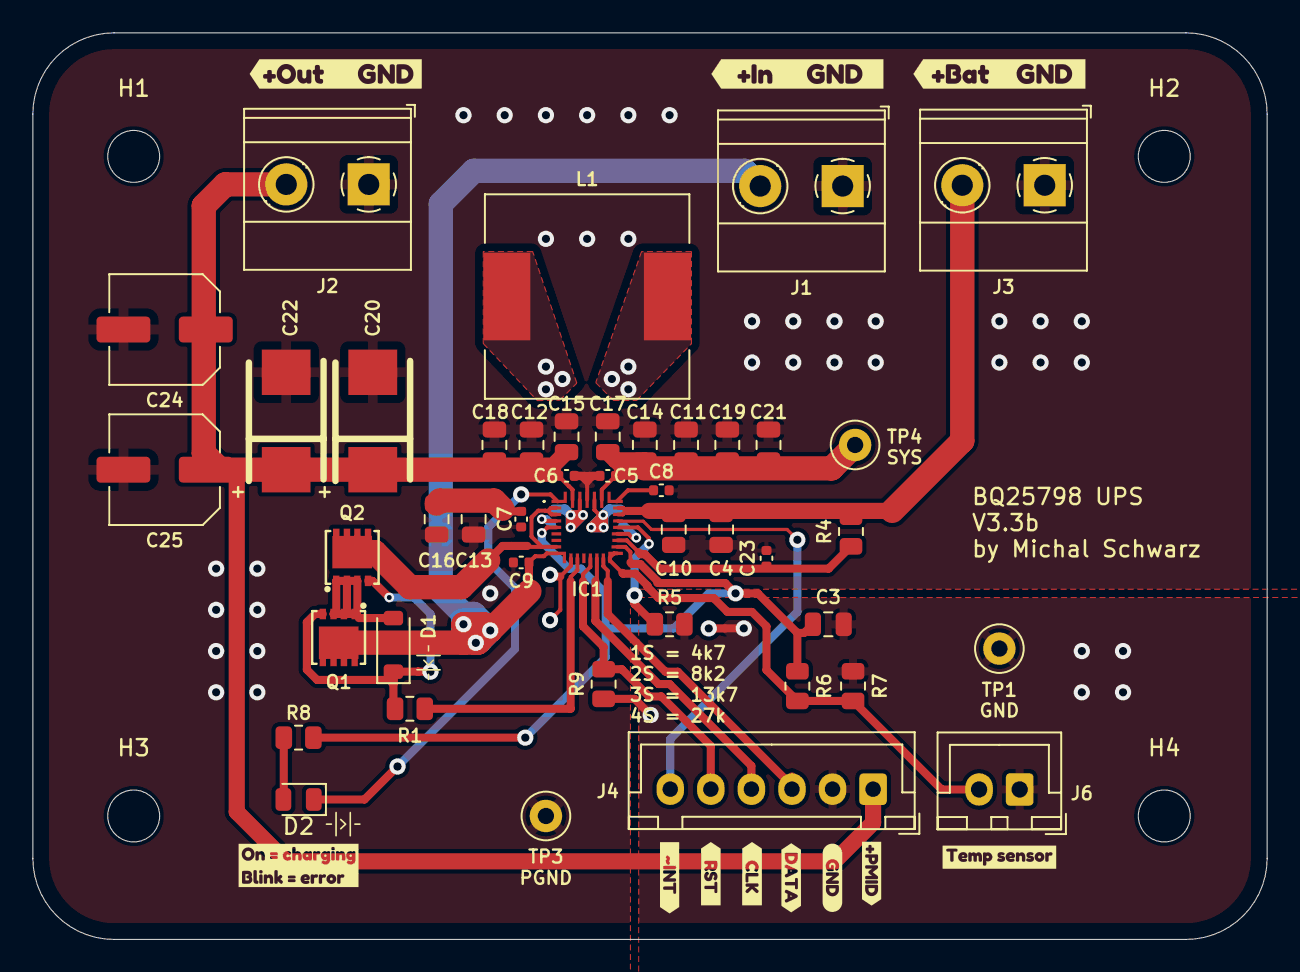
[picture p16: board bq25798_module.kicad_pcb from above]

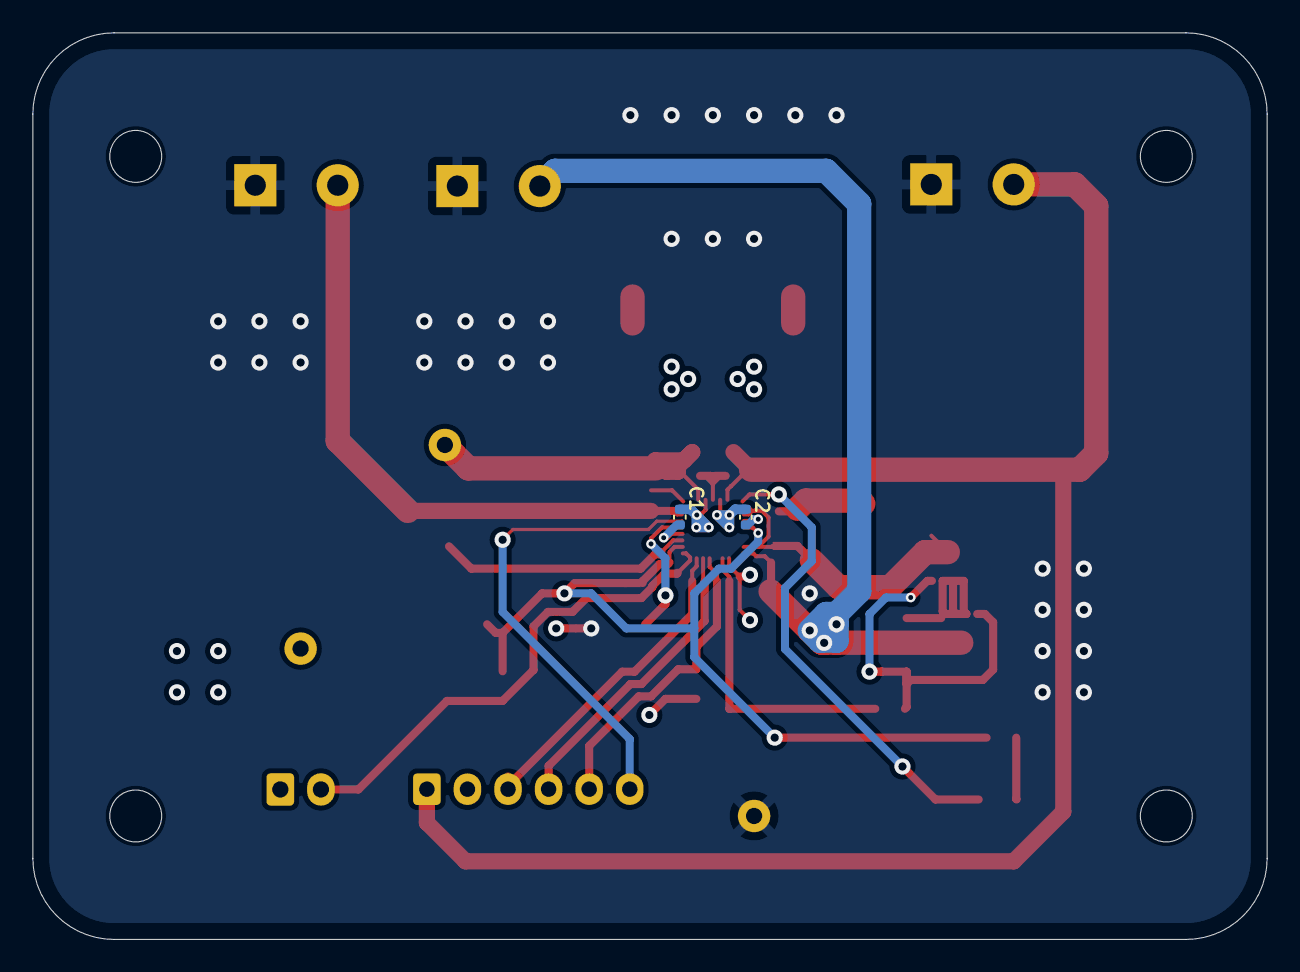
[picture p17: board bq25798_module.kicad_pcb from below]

Board: 4 copper layers, 76.0 x 55.9 mm, 64 parts (2 on the bottom side), 28 nets.

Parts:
C1, C2, C23: 47n 25V; C_0402_1005Metric
C3: 4.7u 10V; C_0805_2012Metric
C4, C10, C11, C12, C13, C14, C15, C16, C17, C18, C19, C21: 10u 25V; C_0805_2012Metric
C5, C6, C7, C9: 100n 25V; C_0402_1005Metric
C8: 1nF, 50V; C_0402_1005Metric
C20, C22: 47u POSCAP; CASE-D_7343
C24, C25: 47u low ESR; C_Elec_6.3x5.8
D1: 12V; D_SOD-123
D2: LED; LED_0805_2012Metric
H1, H2, H3, H4: MountingHole; MountingHole_3.2mm_M3
IC1: BQ25798RQMR; BQ25798RQMR_smaller_protected_area
J1: Input 12V DC; TerminalBlock_Phoenix_MKDS-1,5-2-5.08_1x02_P5.08mm_Horizont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
J2: Output 12V DC; TerminalBlock_Phoenix_MKDS-1,5-2-5.08_1x02_P5.08mm_Horizont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
J3: Battery; TerminalBlock_Phoenix_MKDS-1,5-2-5.08_1x02_P5.08mm_Horizont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
J4: Conn_01x06_Pin; JST_XH_B6B-XH-A_1x06_P2.50mm_Vertical
J6: NTC temp sensor; JST_XH_B2B-XH-A_1x02_P2.50mm_Vertical
L1: 2.2uH; L_12x12mm_H6mm
NT1, NT2, NT4: NetTie-2_SMD_Pad0.5mm
Q1, Q2: AON7528; DFN-8_L3.3-W3.3-P0.65-BL-3
R1: 270R; R_0805_2012Metric
R4: 100R; R_0805_2012Metric
R5: 27k 1-2%; R_0805_2012Metric
R6: 5k6; R_0805_2012Metric
R7: 33k; R_0805_2012Metric
R8: 2k2; R_0805_2012Metric
R9: 10k; R_0805_2012Metric
TP1: GND; TestPoint_Loop_D1.80mm_Drill1.0mm_Beaded
TP3: PGND; TestPoint_Loop_D1.80mm_Drill1.0mm_Beaded
TP4: SYS; TestPoint_Loop_D1.80mm_Drill1.0mm_Beaded
kibuzzard-680F50CE: G***; kibuzzard-680F50CE
kibuzzard-680F50E1: G***; kibuzzard-680F50E1
kibuzzard-680F50F5: G***; kibuzzard-680F50F5
kibuzzard-680F5553: G***; kibuzzard-680F5553
kibuzzard-680FCC32: G***; kibuzzard-680FCC32
kibuzzard-6810EFE9: G***; kibuzzard-6810EFE9
kibuzzard-6810F0BF: G***; kibuzzard-6810F0BF
kibuzzard-6810F0CD: G***; kibuzzard-6810F0CD
kibuzzard-6810F0D5: G***; kibuzzard-6810F0D5
kibuzzard-6810F062: G***; kibuzzard-6810F062
kibuzzard-68585403: G***; kibuzzard-68585403

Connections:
/I2C_SCL: IC1.14 (SCL), J4.4
/I2C_SDA: IC1.15 (SDA), J4.3
/~INT: IC1.21 (~INT), J4.6
/~RST: IC1.13 (~CE), J4.5, R9.2
BATTERY: C4.1, C10.1, IC1.22 (BAT_1), IC1.23 (BAT_2), J3.2, R4.2
BTST1: C2.1, IC1.4 (BTST1)
BTST2: C1.2, IC1.19 (BTST2)
GND: C3.2, IC1.10 (ACDRV2), J4.2, J6.1, NT1.1, R5.2, R7.1, R9.1, TP1.1
ILIM_HIZ: IC1.17 (ILIM_HIZ), NT2.1
unnamed: D1.2 (A), Q1.1 (S), Q1.2 (S), Q1.3 (S), Q2.1 (S), Q2.2 (S), Q2.3 (S)
unnamed: D1.1 (K), Q1.4 (G), Q2.4 (G), R1.2
unnamed: D2.2 (A), R8.2
unnamed: IC1.11 (ACDRV1), R1.1
unnamed: C23.1, IC1.18 (BATP), R4.1
unnamed: IC1.20 (PROG), R5.1
unnamed: IC1.2 (VBUS_1), IC1.3 (VBUS_2), IC1.8 (VAC2), NT4.1
unnamed: NT4.2, Q2.5 (D), Q2.6 (D), Q2.7 (D), Q2.8 (D), Q2.9 (D)
PGND: C4.2, C5.2, C6.2, C7.2, C8.2, C9.2, C10.2, C11.2, C12.2, C13.2, C14.2, C15.2, C16.2, C17.2, C18.2, C19.2, C20.2, C21.2, C22.2, C23.2, C24.2, C25.2, IC1.27 (GND), J1.1, J2.1, J3.1, NT1.2, TP3.1
PMID: C6.1, C12.1, C15.1, C18.1, C20.1, C22.1, C24.1, C25.1, IC1.29 (PMID), J2.2, J4.1
REGN: C3.1, IC1.5 (REGN), NT2.2, R6.1, R8.1
SDRV: C8.1, IC1.24 (SDRV_1), IC1.33 (SDRV_2)
STAT: D2.1 (K), IC1.1 (STAT_1), IC1.30 (STAT_2)
SW1: C2.2, IC1.28 (SW1), L1.2
SW2: C1.1, IC1.26 (SW2), L1.1
SYS: C5.1, C11.1, C14.1, C17.1, C19.1, C21.1, IC1.25 (SYS), TP4.1
TS: IC1.16 (TS_1), IC1.32 (TS_2), J6.2, R6.2, R7.2
VBUS: C7.1, C13.1, C16.1
VIN1: C9.1, IC1.9 (VAC1_1), IC1.31 (VAC1_2), J1.2, Q1.5 (D), Q1.6 (D), Q1.7 (D), Q1.8 (D), Q1.9 (D)

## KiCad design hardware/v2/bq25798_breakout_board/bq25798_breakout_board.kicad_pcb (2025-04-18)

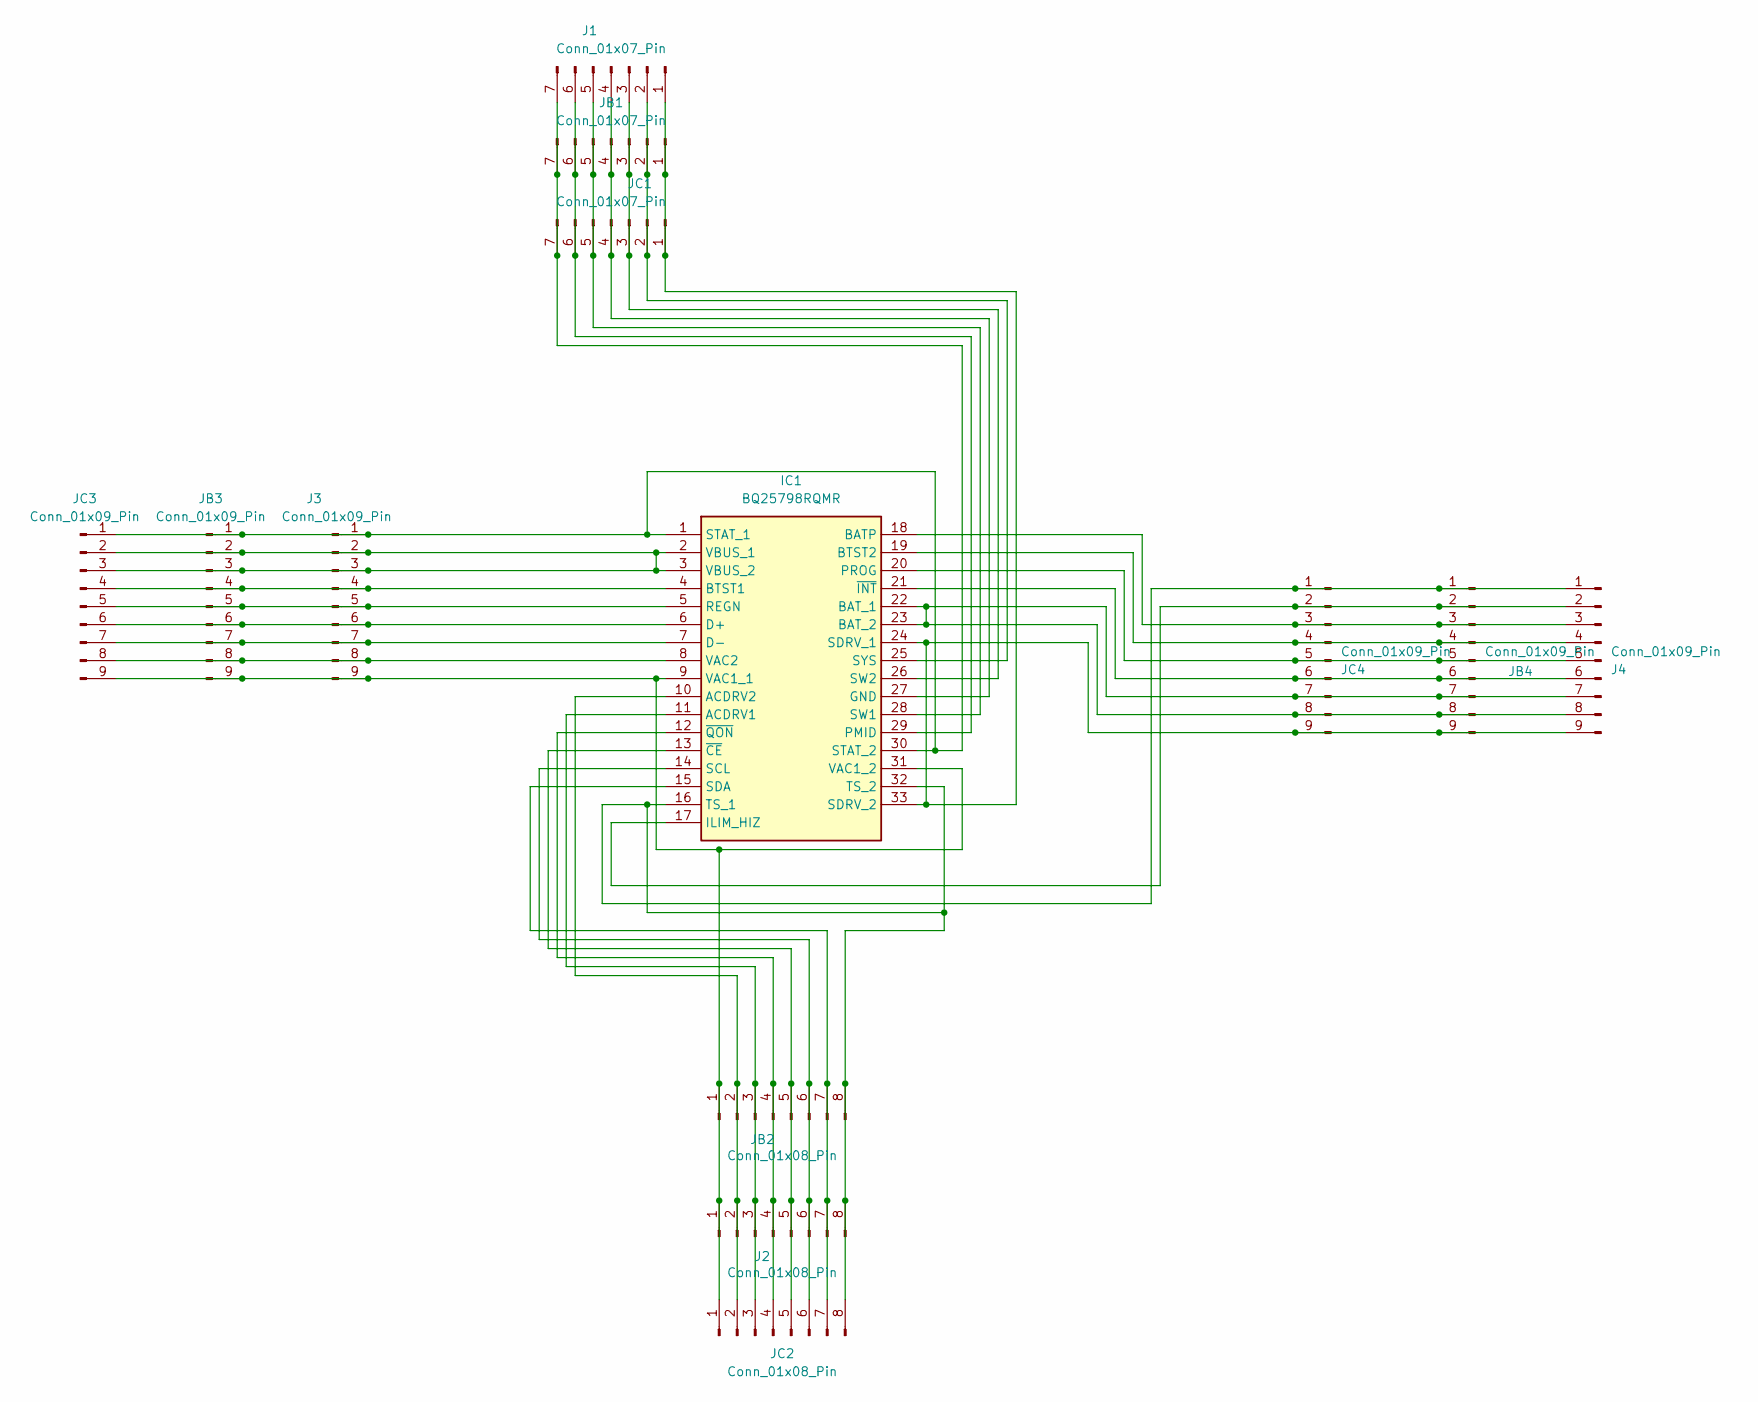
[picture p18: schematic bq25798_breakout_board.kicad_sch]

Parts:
IC1: BQ25798RQMR; Manufacturer_Part_Number BQ25798RQMR; Mouser Part Number 595-BQ25798RQMR
J1: Conn_01x07_Pin; PinHeader_1x07_P2.54mm_Vertical
J2: Conn_01x08_Pin; PinHeader_1x08_P2.54mm_Vertical
J3, J4: Conn_01x09_Pin; PinHeader_1x09_P2.54mm_Vertical
JB1: Conn_01x07_Pin; PinHeader_1x07_P2.54mm_Vertical
JB2: Conn_01x08_Pin; PinHeader_1x08_P2.54mm_Vertical
JB3, JB4: Conn_01x09_Pin; PinHeader_1x09_P2.54mm_Vertical
JC1: Conn_01x07_Pin; PinHeader_1x07_P2.54mm_Vertical
JC2: Conn_01x08_Pin; PinHeader_1x08_P2.54mm_Vertical
JC3, JC4: Conn_01x09_Pin; PinHeader_1x09_P2.54mm_Vertical

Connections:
unnamed: IC1.11 (ACDRV1), J2.3, JB2.3, JC2.3
unnamed: IC1.10 (ACDRV2), J2.2, JB2.2, JC2.2
unnamed: IC1.18 (BATP), J4.3, JB4.3, JC4.3
unnamed: IC1.22 (BAT_1), IC1.23 (BAT_2), J4.7, J4.8, JB4.7, JB4.8, JC4.7, JC4.8
unnamed: IC1.4 (BTST1), J3.4, JB3.4, JC3.4
unnamed: IC1.19 (BTST2), J4.4, JB4.4, JC4.4
unnamed: IC1.6 (D+), J3.6, JB3.6, JC3.6
unnamed: IC1.7 (D-), J3.7, JB3.7, JC3.7
unnamed: IC1.27 (GND), J1.4, JB1.4, JC1.4
unnamed: IC1.17 (ILIM_HIZ), J4.2, JB4.2, JC4.2
unnamed: IC1.29 (PMID), J1.6, JB1.6, JC1.6
unnamed: IC1.20 (PROG), J4.5, JB4.5, JC4.5
unnamed: IC1.5 (REGN), J3.5, JB3.5, JC3.5
unnamed: IC1.14 (SCL), J2.6, JB2.6, JC2.6
unnamed: IC1.15 (SDA), J2.7, JB2.7, JC2.7
unnamed: IC1.24 (SDRV_1), IC1.33 (SDRV_2), J1.1, J4.9, JB1.1, JB4.9, JC1.1, JC4.9
unnamed: IC1.1 (STAT_1), IC1.30 (STAT_2), J1.7, J3.1, JB1.7, JB3.1, JC1.7, JC3.1
unnamed: IC1.28 (SW1), J1.5, JB1.5, JC1.5
unnamed: IC1.26 (SW2), J1.3, JB1.3, JC1.3
unnamed: IC1.25 (SYS), J1.2, JB1.2, JC1.2
unnamed: IC1.16 (TS_1), IC1.32 (TS_2), J2.8, J4.1, JB2.8, JB4.1, JC2.8, JC4.1
unnamed: IC1.9 (VAC1_1), IC1.31 (VAC1_2), J2.1, J3.9, JB2.1, JB3.9, JC2.1, JC3.9
unnamed: IC1.8 (VAC2), J3.8, JB3.8, JC3.8
unnamed: IC1.2 (VBUS_1), IC1.3 (VBUS_2), J3.2, J3.3, JB3.2, JB3.3, JC3.2, JC3.3
unnamed: IC1.13 (~CE), J2.5, JB2.5, JC2.5
unnamed: IC1.21 (~INT), J4.6, JB4.6, JC4.6
unnamed: IC1.12 (~QON), J2.4, JB2.4, JC2.4

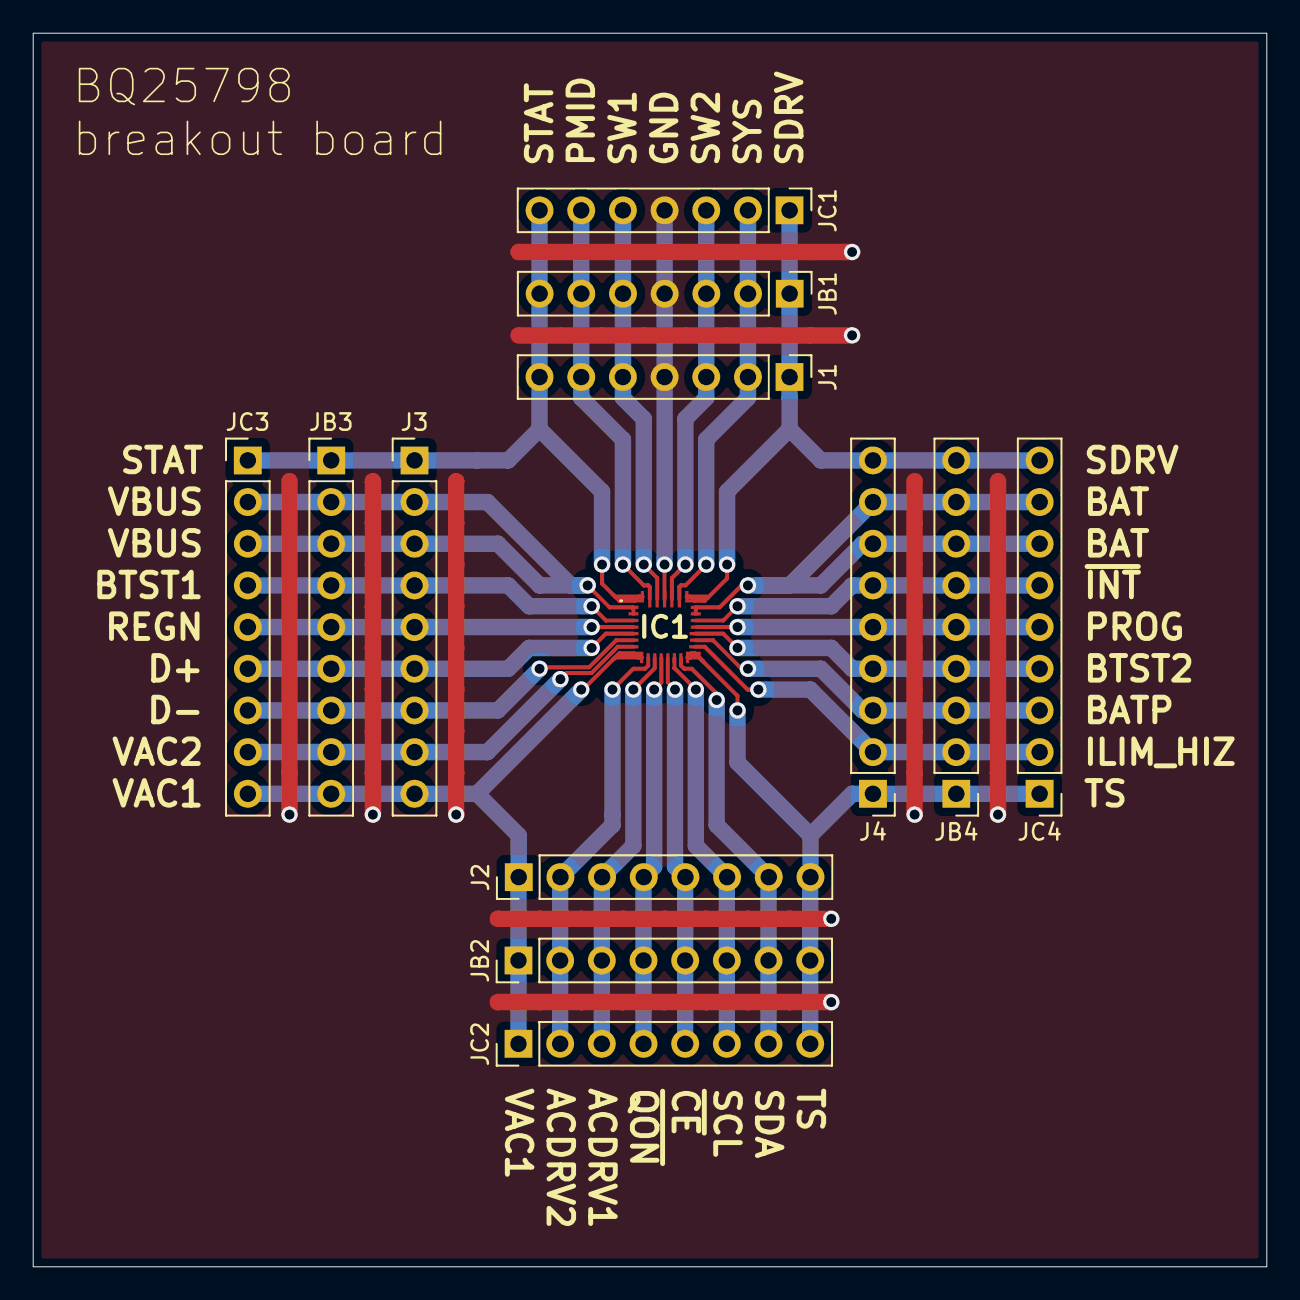
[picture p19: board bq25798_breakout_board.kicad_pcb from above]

Board: 2 copper layers, 75.2 x 75.2 mm, 13 parts (0 on the bottom side), 27 nets.

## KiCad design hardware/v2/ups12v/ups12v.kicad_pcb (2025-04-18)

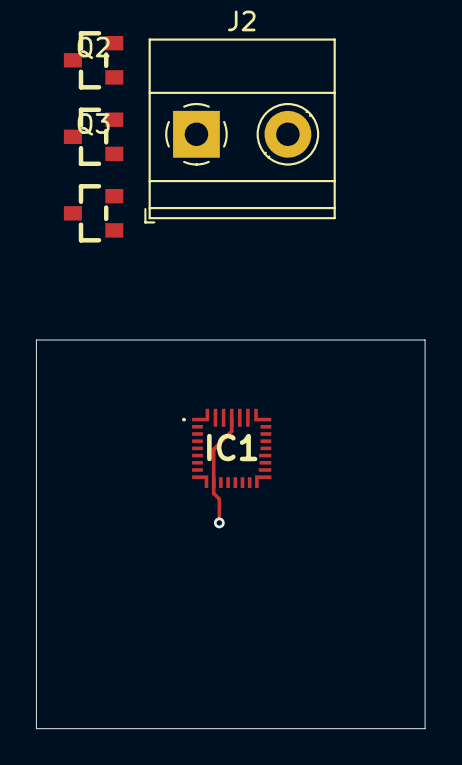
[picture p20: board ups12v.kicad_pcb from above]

Board: 4 copper layers, 21.6 x 21.6 mm, 5 parts (0 on the bottom side), 10 nets.

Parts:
IC1: BQ25798RQMR
J2: BATTERY (BMS); TerminalBlock_Phoenix_MKDS-1,5-2-5.08_1x02_P5.08mm_Horizont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
Q1, Q2, Q3: SI2312CDS-T1-GE3; SOT-23_L2.9-W1.3-P1.90-LS2.4-BR

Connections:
BAT: IC1.22 (BAT_1), IC1.23 (BAT_2), Q3.2 (S)
GND: IC1.10 (ACDRV2), IC1.13 (~CE), IC1.27 (GND), J2.2
unnamed: Q1.2 (S), Q2.2 (S)
unnamed: Q1.1 (G), Q2.1 (G)
unnamed: J2.1, Q3.3 (D)
SDRV: IC1.24 (SDRV_1), IC1.33 (SDRV_2), Q3.1 (G)
STAT: IC1.1 (STAT_1), IC1.30 (STAT_2)
TS: IC1.16 (TS_1), IC1.32 (TS_2)
VBUS: IC1.2 (VBUS_1), IC1.3 (VBUS_2), IC1.8 (VAC2), Q2.3 (D)
VIN1: IC1.9 (VAC1_1), IC1.31 (VAC1_2), Q1.3 (D)

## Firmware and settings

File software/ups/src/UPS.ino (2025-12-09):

#include <ArduinoJson.h>
#include <ArduinoOTA.h>
#include <BQ25798.h>
#include <PubSubClient.h>
#include <Syslog.h>
#include <WiFi.h>
#include <WiFiManager.h>
#include <WiFiUdp.h>
#include <Wire.h>
#include <arduino-timer.h>

#include <array>

#include "board_config.h"
#include "config.h"
#include "homeassistant_mqtt.h"
#include "led_blinker.h"
#include "logger.h"
#include "version.h"

constexpr long ONE_SECOND_IN_MILLIS = 1000;
constexpr double ONE_VOLT_IN_MILLIVOLTS = 1000.0;
constexpr double ONE_AMP_IN_MILLIAMPS = 1000.0;
constexpr double ZERO_DEGC_IN_KELVINS = 273.15;

Logger logger(nullptr, &Serial);  // create a logger instance with Serial as the output stream
WiFiUDP udpClient;
WiFiManager wifiManager;
WiFiClient wifiClient;
PubSubClient mqttClient(wifiClient);
BQ25798 bq25798 = BQ25798();
HomeAssistant::MQTT haClient(mqttClient, logger, config.network.mqtt.haDeviceName, config.hardwareVersion);  // must be unique
Syslog* syslog = nullptr;
LEDBlinker ledBlinker(config.pins.LED, 3 * ONE_SECOND_IN_MILLIS);  // LED blinks every 3 seconds until everything is set up
Timer<10> timers;

std::array<int, BQ25798::SETTINGS_COUNT> oldRawValue;
std::array<int, BQ25798::SETTINGS_COUNT> newRawValue;
std::array<HomeAssistant::EntityMultiConfig, BQ25798::SETTINGS_COUNT> haConfig;

HomeAssistant::EntityConfig haConfigUptime{HomeAssistant::EntityBaseConfig{
    .component = "sensor",
    .config_key = "uptime",
    .state_key = "uptime",
    .entity_category = "diagnostic",
    .device_class = "duration",
    .state_class = "measurement",
    .unit_of_measurement = "s",
    .name = "Uptime",
    .icon = "mdi:chart-box-outline",
}};

HomeAssistant::EntityConfig haConfigBatteryCellCount{HomeAssistant::EntityBaseConfig{
    .component = "sensor",
    .config_key = "battery_cell_count",
    .state_key = "battery_cell_count",
    .entity_category = "diagnostic",
    .device_class = "",
    .state_class = "measurement",
    .unit_of_measurement = "",
    .name = "Battery Cell Count",
    .icon = "mdi:battery-unknown",
}};

HomeAssistant::EntityConfig haConfigBatteryTemperature{HomeAssistant::EntityBaseConfig{
    .component = "sensor",
    .config_key = "battery_temperature",
    .state_key = "battery_temperature",
    .entity_category = "diagnostic",
    .device_class = "temperature",
    .state_class = "measurement",
    .unit_of_measurement = "°C",
    .name = "Battery Temperature",
    .icon = "mdi:thermometer",
}};
HomeAssistant::EntityConfig haConfigBatteryPercent{HomeAssistant::EntityBaseConfig{
    .component = "sensor",
    .config_key = "battery_percent",
    .state_key = "battery_percent",
    .entity_category = "diagnostic",
    .device_class = "battery",
    .state_class = "measurement",
    .unit_of_measurement = "%",
    .name = "Battery Percent",
    .icon = "",
}};
HomeAssistant::EntityConfig haConfigPBAT{HomeAssistant::EntityBaseConfig{
    .component = "sensor",
    .config_key = "PBAT",
    .state_key = "PBAT",
    .entity_category = "diagnostic",
    .device_class = "power",
    .state_class = "measurement",
    .unit_of_measurement = "W",
    .name = "",
    .icon = "",
}};
HomeAssistant::EntityConfig haConfigPBUS{HomeAssistant::EntityBaseConfig{
    .component = "sensor",
    .config_key = "PBUS",
    .state_key = "PBUS",
    .entity_category = "diagnostic",
    .device_class = "power",
    .state_class = "measurement",
    .unit_of_measurement = "W",
    .name = "",
    .icon = "",
}};
HomeAssistant::EntityConfig haConfigResetButton{HomeAssistant::EntityBaseConfig{
    .component = "button",
    .config_key = "reset_button",
    .state_key = "reset_button",
    .entity_category = "config",
    .device_class = "",
    .state_class = "",
    .unit_of_measurement = "",
    .name = "Reset BQ25798",
    .icon = "mdi:restart",
}};

HomeAssistant::EntityConfig haConfigReconfigureButton{HomeAssistant::EntityBaseConfig{
    .component = "button",
    .config_key = "reconfigure_button",
    .state_key = "reconfigure_button",
    .entity_category = "config",
    .device_class = "",
    .state_class = "",
    .unit_of_measurement = "",
    .name = "Reconfigure BQ25798",
    .icon = "mdi:reload",
}};

String fix_unit(String unit) {
  if (unit == "degC") {
    return "°C";
  }
  return unit;
}

void patWatchdog() {
  // To keep the device in host mode, the host has  to reset the watchdog timer
  // by writing 1 to WD_RST bit before the watchdog timer expires
  bq25798.setWD_RST(true);  // reset the watchdog timer
}

bool checkForError() {
  if (bq25798.lastError()) {
    logger.log(LOG_ERR, "Error: %d\n", bq25798.lastError());
    bq25798.clearError();
    return true;
  }
  return false;
}

int batteryCellCount() {
  switch (bq25798.getCELL()) {
    case BQ25798::CELL_t::CELL_1S:
      return 1;
      break;
    case BQ25798::CELL_t::CELL_2S:
      return 2;
      break;
    case BQ25798::CELL_t::CELL_3S:
      return 3;
      break;
    case BQ25798::CELL_t::CELL_4S:
      return 4;
      break;
    default:
      logger.log(LOG_ERR, "Unknown battery cell count: %d", bq25798.getCELL());
      while (true) {
        ledBlinker.loop();
        ArduinoOTA.handle();
        delay(1000);
      }
  }
}

bool firstRun = true;  // flag to indicate if this is the first run of the loop
void trackChanges() {
  long now = millis();

  for (int i = 0; i < BQ25798::SETTINGS_COUNT; i++) {
    BQ25798::Setting setting = bq25798.getSetting(i);
    newRawValue[i] = bq25798.getRaw(setting);
    if (checkForError()) {
      logger.log(LOG_ERR, "Error reading setting %d (%s)\n", i, setting.name);
      return;  // stop tracking changes if there is an error
    }
  }

  if (firstRun) {
    for (int i = 0; i < BQ25798::SETTINGS_COUNT; i++) {
      oldRawValue[i] = newRawValue[i];
    }
  }

  // every next time check if the values changed
  for (int i = 0; i < BQ25798::SETTINGS_COUNT; i++) {
    BQ25798::Setting setting = bq25798.getSetting(i);

    // exception: do not notify about flags set to FALSE because any read
    // operation will reset them to FALSE
    if (setting.is_flag && newRawValue[i] == 0) {
      continue;
    }

    if (setting.type == BQ25798::settings_type_t::BOOL) {
      if (!setting.is_flag) {
        bool old_val = bq25798.rawToBool(oldRawValue[i], setting);
        bool new_val = bq25798.rawToBool(newRawValue[i], setting);
        haClient.publishStateIfNeeded(haConfig[i].configBinarySensor, new_val ? "ON" : "OFF", firstRun || oldRawValue[i] != newRawValue[i]);

        if (oldRawValue[i] != newRawValue[i]) {
          logger.log(LOG_INFO, "%s changed to %s (from %s)", setting.name, new_val ? "ON" : "OFF", old_val ? "ON" : "OFF");
        }
      }

    } else if (setting.type == BQ25798::settings_type_t::ENUM) {
      const char* old_val_string = bq25798.rawToString(oldRawValue[i], setting);
      const char* new_val_string = bq25798.rawToString(newRawValue[i], setting);
      int old_val_int = bq25798.rawToInt(oldRawValue[i], setting);
      int new_val_int = bq25798.rawToInt(newRawValue[i], setting);

      haClient.publishStateIfNeeded(haConfig[i].configText, new_val_string, firstRun || oldRawValue[i] != newRawValue[i]);
      haClient.publishStateIfNeeded(haConfig[i].configSensor, String(new_val_int), firstRun || oldRawValue[i] != newRawValue[i]);
      haClient.publishStateIfNeeded(haConfig[i].configBinarySensor, String(new_val_int ? "ON" : "OFF"), firstRun || oldRawValue[i] != newRawValue[i]);

      if (oldRawValue[i] != newRawValue[i]) {
        logger.log(LOG_INFO, "%s changed to \"%s\" (%d), was \"%s\" (%d)", setting.name, new_val_string, new_val_int, old_val_string, old_val_int);
      }

    } else if (setting.type == BQ25798::settings_type_t::INT) {
      // Float and int values are sent only on HA timeout, not on every tiny change
      int old_val = bq25798.rawToInt(oldRawValue[i], setting);
      int new_val = bq25798.rawToInt(newRawValue[i], setting);
      haClient.publishStateIfNeeded(haConfig[i].configSensor, String(new_val),
                                    firstRun || (abs(old_val - new_val) > abs(old_val * 0.1)));  // 10% change is enough to notify

    } else if (setting.type == BQ25798::settings_type_t::FLOAT) {
      // Float and int values are sent only on HA timeout, not on every tiny change
      float old_val = bq25798.rawToFloat(oldRawValue[i], setting);
      float new_val = bq25798.rawToFloat(newRawValue[i], setting);
      haClient.publishStateIfNeeded(haConfig[i].configSensor, String(new_val),
                                    firstRun || (abs(old_val - new_val) > abs(old_val * 0.1)));  // 10% change is enough to notify
    }
  }

  // update the old values
  for (int i = 0; i < BQ25798::SETTINGS_COUNT; i++) {
    oldRawValue[i] = newRawValue[i];
  }
  firstRun = false;
}

void sendCalculatedValues() {
  // Send calculated values
  double ts_adc = bq25798.getTS_ADC() / 100.0;  // convert from percent to 0.0-1.0 range
  double ts_combo_resistance = ts_adc * config.temperatureSensor.R_vregn / (1.0 - ts_adc);
  double ts_resistance = 1.0 / (1.0 / ts_combo_resistance - 1.0 / config.temperatureSensor.R_gnd);
  double ts_temperature =
      1.0 / (1.0 / (ZERO_DEGC_IN_KELVINS + 25.0) + log(ts_resistance / config.temperatureSensor.resistance_25degC) / config.temperatureSensor.beta) -
      ZERO_DEGC_IN_KELVINS;
  haClient.publishStateIfNeeded(&haConfigBatteryTemperature, String(ts_temperature, 1));

  double vbat_percent = 100 * (bq25798.getVBAT_ADC() / batteryCellCount() - config.power.charger.minCellVoltage_mV) /
                        (config.power.charger.maxCellVoltage_mV - config.power.charger.minCellVoltage_mV);
  vbat_percent = constrain(vbat_percent, 0.0, 100.0);  // constrain to 0-100%
  haClient.publishStateIfNeeded(&haConfigBatteryPercent, String(vbat_percent), firstRun);

  double bat_power = (bq25798.getIBAT_ADC() / ONE_AMP_IN_MILLIAMPS) * (bq25798.getVBAT_ADC() / ONE_VOLT_IN_MILLIVOLTS);
  haClient.publishStateIfNeeded(&haConfigPBAT, String(bat_power), firstRun);

  double bus_power = (bq25798.getIBUS_ADC() / ONE_AMP_IN_MILLIAMPS) * (bq25798.getVBUS_ADC() / ONE_VOLT_IN_MILLIVOLTS);
  haClient.publishStateIfNeeded(&haConfigPBUS, String(bus_power), firstRun);

  haClient.publishStateIfNeeded(&haConfigUptime, String(millis() / ONE_SECOND_IN_MILLIS));
  haClient.publishStateIfNeeded(&haConfigBatteryCellCount, String(batteryCellCount()), firstRun);

  haClient.publishStateIfNeeded(&haConfigResetButton, "available");        // maybe not needed, but just in case
  haClient.publishStateIfNeeded(&haConfigReconfigureButton, "available");  // maybe not needed, but just in case
}

void checkChargerStatus() {
  // Enable the charger if everything is normal
  if (bq25798.getPG_STAT() == BQ25798::PG_STAT_t::PG_STAT_GOOD  //
      && bq25798.getVBUS_STAT() != BQ25798::VBUS_STAT_t::VBUS_STAT_BACKUP_MODE) {
    int cell_mV = bq25798.getVBAT_ADC() / batteryCellCount();
    if (cell_mV > config.power.charger.vbatChgDisableIfCellAbove_mV &&  //
        (bq25798.getCHG_STAT() == BQ25798::CHG_STAT_t::CHG_STAT_NOT_CHARGING || bq25798.getCHG_STAT() == BQ25798::CHG_STAT_t::CHG_STAT_TERMINATED)) {
      if (bq25798.getEN_CHG() == true) {
        logger.log(LOG_INFO,
                   "Disabling charger, power is good, charger is not charging and battery cell (%d) is "
                   "above limit (%d) ...",
                   cell_mV, config.power.charger.vbatChgDisableIfCellAbove_mV);
        bq25798.setEN_CHG(false);  // disable the charger
      }
    } else if (cell_mV < config.power.charger.vbatChgEnableIfCellBelow_mV) {
      if (bq25798.getEN_CHG() == false) {
        logger.log(LOG_INFO,
                   "Enabling charger, power is good and battery cell (%d mV) is "
                   "below limit (%d mV)...",
                   cell_mV, config.power.charger.vbatChgEnableIfCellBelow_mV);
        bq25798.setEN_CHG(true);  // enable the charger
      }
    }
  }
}

void onetimeSetupIfNeeded(bool force = false, bool reset = false) {
  if (bq25798.getVAC2_ADC_DIS() && !force) {
    // VAC2_ADC_DIS is false by default, so if it is true, it means the IC has already been initialized by us
    logger.log(LOG_INFO, "IC already initialized (VAC2_ADC_DIS == true), skipping configuration.");
    return;
  }

  if (reset) {
    logger.log(LOG_INFO, "Resetting the IC completely...");
    bq25798.setREG_RST(true);  // reset the IC
    while (bq25798.getREG_RST()) {
      ledBlinker.loop();
      ArduinoOTA.handle();
      delay(10);
      bq25798.readAllRegisters();
    }
    logger.log(LOG_INFO, "Reset successful.");
  }

  logger.log(LOG_INFO, "Configuring BQ25798...");
  // FIXME to prevent chip reset when the host controller is disconnected
  // temporarily
  bq25798.setWATCHDOG(BQ25798::WATCHDOG_t::WATCHDOG_DISABLE);  // disable watchdog timer

  // enable continuous ADC readout
  bq25798.setADC_RATE(BQ25798::ADC_RATE_t::ADC_RATE_CONTINUOUS);
  bq25798.setADC_SAMPLE(BQ25798::ADC_SAMPLE_t::ADC_SAMPLE_15BIT);
  bq25798.setADC_EN(true);  // trigger ADC one-shot mode

  bq25798.setIBUS_ADC_DIS(false);  // enable IBUS ADC
  bq25798.setIBAT_ADC_DIS(false);  // enable IBAT ADC
  bq25798.setEN_IBAT(true);        // enable IBAT measurement ("Enable the IBAT discharge sensing at battery or OTG condition")
  bq25798.setVAC2_ADC_DIS(true);   // disable VAC2 ADC (not used)

  // Disable HIZ mode (high impedance mode):
  bq25798.setEN_HIZ(false);

  // Disable input type detection:
  bq25798.setAUTO_INDET_EN(false);

  if (config.power.backupMode == Config::Power::BackupMode::VSYS_UNINTERRUPTED) {
    // Set VSYS backup mode
    logger.log(LOG_INFO, "Using VSYS uninterrupted backup mode.");
    // bq25798.setVSYSMIN(config.VSYSMIN_mV);
    // bq25798.setVOTG(2800);  // minimum allowed value
    // bq25798.setIOTG(160);   // minimum allowed value
    // bq25798.setVBUS_BACKUP(BQ25798::VBUS_BACKUP_t::PCT_VBUS_BACKUP_100);
  } else {
    // Set PMID with switchover backup mode
    logger.log(LOG_INFO, "Using PMID with switchover backup mode.");
    if (config.power.output.VOTG_mV > 0) {
      bq25798.setVOTG(config.power.output.VOTG_mV);
    }
    if (config.power.output.IOTG_mA > 0) {
      bq25798.setIOTG(config.power.output.IOTG_mA);
    }
    bq25798.setVBUS_BACKUP(config.power.input.VBUSBackupPercentage);
  }

  if (config.power.input.VINDPM_mV > 0) {
    bq25798.setVINDPM(config.power.input.VINDPM_mV);
  }
  if (config.power.input.IINDPM_mA > 0) {
    bq25798.setIINDPM(config.power.input.IINDPM_mA);
  }
  bq25798.setICHG(config.power.charger.ICHG_mA);

  // Enable BACKUP mode as needed:
  if (config.power.backupMode == Config::Power::BackupMode::VSYS_UNINTERRUPTED) {
    bq25798.setEN_BACKUP(false);
  } else {
    bq25798.setEN_BACKUP(true);
  }

  logger.log(LOG_INFO, "Configuration complete.");
}

bool waitForBQCondition(bool (*condition)(), int timeoutMillis = 5000) {
  long startTime = millis();
  bq25798.readAllRegisters();
  while (!condition()) {
    ledBlinker.loop();
    ArduinoOTA.handle();
    // timers.tick(); // NO, do not use timers.tick() here, we do not want any side effects here, it might asynchronously change the state of IC in
    // rearmBackupMode() etc.
    if (millis() - startTime > timeoutMillis) {
      return false;
    }
    delay(10);
    bq25798.readAllRegisters();
  }
  // timers.tick();
  return true;
}

void rearmBackupMode() {
  if (config.power.backupMode == Config::Power::BackupMode::VSYS_UNINTERRUPTED) {
    logger.log(LOG_INFO, "VSYS uninterrupted backup mode is used, no need to re-arm.");
    return;
  }

  // Re-arm the backup mode by setting EN_BACKUP to false and then true again
  bq25798.readAllRegisters();

  logger.log(LOG_INFO, "Exiting backup mode and re-arming UPS...");

  // When a backup mode is entered automatically, the following happens:
  // DIS_ACDRV is set to TRUE, EN_OTG is set to TRUE, EN_ACDRV1 is set to FALSE,
  // PG is set to FALSE and VBUS_STAT is set to "Backup"
  //
  // So let's check if we are still in backup mode:

  if (bq25798.getVBUS_STAT() != BQ25798::VBUS_STAT_t::VBUS_STAT_BACKUP_MODE) {
    logger.log(LOG_ERR, "Error: VBUS_STAT is not BACKUP_MODE, is: %d", bq25798.getVBUS_STAT());
    return;
  }
  if (!bq25798.getDIS_ACDRV()) {
    logger.log(LOG_ERR, "In backup mode Error: ACDRV is not globally disabled, cannot re-arm.");
    return;
  }
  if (!bq25798.getEN_OTG()) {
    logger.log(LOG_ERR, "In backup mode Error: OTG is not active, cannot re-arm.");
    return;
  }

  // See page 37 of the BQ25798 datasheet:
  // If there is an adapter reconnected while the charger is in backup mode, the
  // user may transition the source which powers the PMID load from the battery
  // back to the adapter. The following sequence is used to switch from the
  // battery power back to ACIN1 while simultaneously re-arming the backup mode:
  // 1. Write BKUP_ACFET1_ON (REG0x16[0]) register bit to 1. Setting BKUP_ACFET1
  // _ON = 1 will cause the device to set DIS_ACDRV = 0 and EN_ACDRV1 = 1. After
  // that, backup mode is disabled, however, the charger remains in the normal
  // OTG mode. The ACFET1-RBFET1 is turned on to connect the adapter to VBUS.
  // The user must ensure the adapter voltage is equal to or higher than the
  // charger VOTG voltage setting, otherwise, the charger OTG output might back
  // drive the adapter connected to VBUS.
  // 2. Determine the source at ACIN1 is valid (is not in overvoltage and did
  // not fail poor source detection) by reading back EN_ACDRV1 as 1.
  // 3. Set EN_OTG = 0, in order to exit OTG mode and enter the forward charging
  // mode without PMID voltage crash. Setting BKUP_ACFET1_ON = 1, also clears
  // BKUP_ACFET1_ON to 0 and sets EN_BACKUP to 1.

  if (bq25798.getAC1_PRESENT_STAT() != BQ25798::AC1_PRESENT_STAT_t::AC1_PRESENT_STAT_PRESENT) {
    logger.log(LOG_ERR, "Error: AC1 is not present, cannot re-arm.");
    return;
  }

  // Disable charger to prevent any charging while we are in the OTG mode
  logger.log(LOG_INFO, "Disabling charger...");
  bq25798.setEN_CHG(false);  // disable the charger

  // BKUP_ACFET1_ON does the following:
  // - set DIS_ACDRV to 0 && set EN_ACDRV1 to 1 (enable ACDRV1)
  // - set EN_BACKUP to 0 (disable backup mode) -- why does it do this???
  // - set BKUP_ACFET1_ON to 1
  // it also sets the VBUS_STAT to OTG
  logger.log(LOG_INFO, "Setting BKUP_ACFET1_ON to 1...");
  bq25798.setBKUP_ACFET1_ON(true);  // turn on the ACFET1-RBFET1 to connect the adapter to VBUS

  logger.log(LOG_INFO, "Waiting for a confirmation of ACFET1 enabled...");
  if (!waitForBQCondition([]() { return bq25798.getEN_ACDRV1() == true; })) {
    logger.log(LOG_ERR, "Error: failed to turn ACDRV1 on.");
    return;
  }

  // EN_OTG should do the following when BKUP_ACFET1_ON is active:
  // - set EN_OTG to 0 (exit OTG mode)
  // - set EN_BACKUP to 1 (re-arm backup mode -- that's because BKUP_ACFET1_ON
  // is still set to 1)
  // - set BKUP_ACFET1_ON to 0
  // it also sets VBUS_STAT to normal input mode
  logger.log(LOG_INFO, "Proceeding to exit OTG mode...");
  bq25798.setEN_OTG(false);  // exit OTG mode and enter the forward charging
                             // mode without PMID voltage crash

  logger.log(LOG_INFO, "Waiting for a confirmation of OTG disabled and backup re-enabled...");
  if (!waitForBQCondition([]() { return bq25798.getEN_OTG() == false && bq25798.getEN_BACKUP() == true; })) {
    logger.log(LOG_ERR, "Error: failed to exit OTG mode and re-arm.");
    return;
  }

  logger.log(LOG_INFO, "Waiting for PG_STAT to be GOOD...");
  if (!waitForBQCondition([]() { return bq25798.getPG_STAT() == BQ25798::PG_STAT_t::PG_STAT_GOOD; })) {
    logger.log(LOG_ERR, "Error: failed to re-arm backup mode, PG_STAT is not GOOD.");
    return;
  }

  logger.log(LOG_INFO, "Backup mode re-armed.");
}

void MQTTcallback(char* topic, byte* payload, unsigned int length) {
  String topicString = String(topic);

  String payloadString = "";
  for (int i = 0; i < length; i++) {
    payloadString += (char)payload[i];
  }

  logger.log(LOG_INFO, "Message arrived on topic %s, payload %s", topicString.c_str(), payloadString.c_str());

  if (topicString == haClient.getCommandTopic(&haConfigResetButton)) {
    onetimeSetupIfNeeded(true, true);  // force reset the IC and re-initialize it
    return;
  } else if (topicString == haClient.getCommandTopic(&haConfigReconfigureButton)) {
    onetimeSetupIfNeeded(true, false);  // reinitialize the IC without resetting it
    publishHAConfigurations();
    return;
  }
}

void setupWiFi() {
  logger.log(LOG_INFO, "Starting WiFi manager...");
  // Connect to WiFi
  wifiManager.setHostname(HOSTNAME);
  wifiManager.setConnectRetries(5);
  wifiManager.setConnectTimeout(15);           // in seconds
  wifiManager.setConfigPortalTimeout(3 * 60);  // Stay 3 minutes max in the AP web portal, then reboot
  bool res = wifiManager.autoConnect();
  if (!res) {
    logger.log(LOG_ERR, "Failed to connect to wifi, rebooting.");
    ESP.restart();
  }
  if (WiFi.localIP() == IPAddress(0, 0, 0, 0)) {
    logger.log(LOG_ERR, "Failed to get an IP address, rebooting.");
    ESP.restart();
  }
  logger.log(LOG_INFO, "Connected to WiFi: %s (%s)\n", WiFi.SSID().c_str(), WiFi.localIP().toString().c_str());
}
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
void loop() {
  // Read all registers to update the state
  bq25798.readAllRegisters();
  checkForError();

  // Process the timers and event handlers
  adjustBlinkSpeed();
  ledBlinker.loop();
  timers.tick();  // DO NOT call timers.tick() from anywhere else! It might cause side effects like a recursion or overlaps in the code flow.
  ArduinoOTA.handle();
  mqttClient.loop();

  if (config.power.backupMode == Config::Power::BackupMode::PMID_WITH_SWITCHOVER) {
    checkForUPSModeChange();  // check if the UPS mode has changed
  }

  delay(20);  // not too long to not interfere with the fastest possible LED blinking
}

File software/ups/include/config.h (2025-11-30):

#pragma once

#include <BQ25798.h>

// Main configuration class containing all board-specific settings
class Config {
 public:
  struct Pins {
    int I2C_SDA = 21;  // GPIO pin for I2C SDA
    int I2C_SCL = 22;  // GPIO pin for I2C SCL
    int LED = 2;       // GPIO pin for the LED
  };

  struct Network {
    struct Syslog {
      const char* serverHostname = "logserver.localnet";
      int serverPort = 514;
      const char* myHostname = "default";
      const char* myAppname = "ups";
    };

    struct MQTT {
      const char* serverHostname = "mqtt.localnet";
      int serverPort = 1883;
      const char* user = "ups";
      const char* password = "6534GagEWGEWgew8743g3321";
      const char* haDeviceName = "default-ups";  // Home Assistant device name
    };

    Syslog syslog;
    MQTT mqtt;
  };

  struct TemperatureSensor {
    double R_vregn = 5600;              // resistor connected to REGN
    double R_gnd = 33000;               // resistor connected to GND
    double resistance_25degC = 10000.0; // resistance of the NTC sensor at 25 degrees Celsius
    double beta = 3435.0;               // beta value of the NTC sensor
  };

  struct Power {
    // Power management settings
    enum BackupMode {
      PMID_WITH_SWITCHOVER = 0,
      VSYS_UNINTERRUPTED = 1,
    };

    struct Input {
      int IINDPM_mA = 1000;                                                                    // Input current limit (DPM threshold) in mA
      int VINDPM_mV = 11500;                                                                   // Input voltage DPM threshold in mV
      BQ25798::VBUS_BACKUP_t VBUSBackupPercentage = BQ25798::VBUS_BACKUP_t::PCT_VBUS_BACKUP_80; // Backup mode setting
    };

    struct Charger {
      int minCellVoltage_mV = 3200;              // Minimum voltage of a single cell in mV for calculations of charge %
      int maxCellVoltage_mV = 4200;              // Maximum voltage of a single cell in mV for calculations of charge %
      int vbatChgEnableIfCellBelow_mV = 4100;    // Lower voltage at which the charger is enabled in mV
      int vbatChgDisableIfCellAbove_mV = 4155;   // Higher Voltage at which the charger is disabled in mV
      int ICHG_mA = 1000;                        // Charge current in mA (max)
    };

    struct Output {
      int IOTG_mA = 1200;  // Output current for OTG mode in mA
      int VOTG_mV = 12000; // Output voltage for OTG mode
    };

    BackupMode backupMode = PMID_WITH_SWITCHOVER;
    Input input;
    Charger charger;
    Output output;
  };

  // Hardware version
  const char* hardwareVersion = "1.0";

  Pins pins;
  Network network;
  TemperatureSensor temperatureSensor;
  Power power;

  // Backup mode settings
  int ACRecoveryPeriodSeconds = 30;  // time to wait for AC to be present and stable
};

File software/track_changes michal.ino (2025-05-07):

#include <Arduino.h>
#include <BQ25798.h>
#include <Wire.h>

#include <array>

#define I2C_SDA_PIN 21
#define I2C_SCL_PIN 22

const int ADC_readout_time_millis = 30000;

BQ25798 bq25798 = BQ25798();

std::array<int, BQ25798::SETTINGS_COUNT> oldRawValues;
std::array<int, BQ25798::SETTINGS_COUNT> newRawValues;
long startMillis = 0;
long lastADCReadMillis = 0;

void printMostImportantStats() {
  Serial.printf("Main stats: ");

  if (bq25798.getBool(bq25798.IINDPM_STAT) || bq25798.getBool(bq25798.VINDPM_STAT)) {
    Serial.printf("DPM! ");
  };
  // if (bq25798.faultFlagRaised()) {
  //   Serial.printf("FAULT_FLAG! ");
  // };
  if (!bq25798.getBool(bq25798.PG_STAT)) {  // inverted logic
    Serial.printf("PG! ");
  };
  if (bq25798.getBool(bq25798.EN_HIZ)) {
    Serial.printf("HIZ! ");
  };
  if (bq25798.getBool(bq25798.VSYS_STAT)) {
    Serial.printf("VSYS! ");
  };
  if (!bq25798.getBool(bq25798.VBUS_PRESENT_STAT)) {  // inverted logic
    Serial.printf("VBUS! ");
  };
  if (!bq25798.getBool(bq25798.AC1_PRESENT_STAT)) {  // inverted logic
    Serial.printf("AC1! ");
  };
  if (!bq25798.getBool(bq25798.VBAT_PRESENT_STAT)) {  // inverted logic
    Serial.printf("VBAT! ");
  };

  if (bq25798.getBool(bq25798.TS_IGNORE)) {
    Serial.printf("+TS_IGNORE ");
  };
  if (bq25798.getBool(bq25798.EN_BACKUP)) {
    Serial.printf("+EN_BACKUP ");
  };
  if (bq25798.getBool(bq25798.EN_OTG)) {
    Serial.printf("+EN_OTG ");
  };
  if (bq25798.getBool(bq25798.EN_CHG)) {
    Serial.printf("+EN_CHG ");
  };
  if (bq25798.getBool(bq25798.EN_ACDRV1)) {
    Serial.printf("+EN_ACDRV1 ");
  };
  Serial.printf("CHG=[%d]\"%s\" ", bq25798.getInt(bq25798.CHG_STAT), bq25798.getString(bq25798.CHG_STAT));

  Serial.println();
}

void trackChanges() {
  if (!bq25798.readAll()) {
    Serial.printf("Error: %d", bq25798.getError());
    bq25798.clearError();
    delay(10000);
    return;
  }

  for (int i = 0; i < BQ25798::SETTINGS_COUNT; i++) {
    BQ25798::Setting setting = bq25798.getSetting(i);
    newRawValues[i] = bq25798.getRaw(setting);
  }

  bool justStarted = false;
  if (startMillis == 0) {
    justStarted = true;
    startMillis = millis();
    lastADCReadMillis = startMillis;

    for (int i = 0; i < BQ25798::SETTINGS_COUNT; i++) {
      oldRawValues[i] = 0xFFFF;  // set to invalid value
    }

    // First time just copy the values
    // Serial.println("First time reading BQ25798 settings...");
    // for (int i = 0; i < BQ25798::SETTINGS_COUNT; i++) {
    //   oldRawValues[i] = newRawValues[i];
    // }
    // Serial.println("Waiting for changes...");
    // return;
  }

  // every next time check if the values changed
  long elapsedMillis = millis() - startMillis;
  bool changed = false;
  for (int i = 0; i < BQ25798::SETTINGS_COUNT; i++) {
    if (oldRawValues[i] != newRawValues[i]) {
      BQ25798::Setting setting = bq25798.getSetting(i);

      // exception: do not notify about flags set to FALSE because any read operation will reset them to FALSE
      if (setting.type == BQ25798::settings_type_t::BOOL && strstr(setting.name, "_FLAG") != nullptr) {
        if (newRawValues[i] == 0) {
          continue;
        }
      }

      changed = true;
      Serial.printf("[T+%7.3fs] %20s ", elapsedMillis / 1000.0f, setting.name);
      if (setting.type == BQ25798::settings_type_t::FLOAT) {
        Serial.printf("(float) = %-50.3f     ",  //
                      bq25798.rawToFloat(newRawValues[i], setting));
        if (!justStarted) {
          Serial.printf("(was %.3f)",  //
                        bq25798.rawToFloat(oldRawValues[i], setting));
        }
      } else if (setting.type == BQ25798::settings_type_t::BOOL) {
        Serial.printf("(bool)  = %-50s     ",  //
                      bq25798.rawToBool(newRawValues[i], setting) ? "TRUE" : "false");
        if (!justStarted) {
          Serial.printf("(was %s)",  //
                        bq25798.rawToBool(oldRawValues[i], setting) ? "TRUE" : "false");
        }
      } else if (setting.type == BQ25798::settings_type_t::ENUM) {
        Serial.printf("(enum)  = [%d] \"%s\"%*s",  //
                      newRawValues[i], bq25798.rawToString(newRawValues[i], setting), 50 - 1 - strlen(bq25798.rawToString(newRawValues[i], setting)), "");
        if (!justStarted) {
          Serial.printf("(was [%d] \"%s\")",  //
                        oldRawValues[i], bq25798.rawToString(oldRawValues[i], setting));
        };
      } else if (setting.type == BQ25798::settings_type_t::INT) {
        Serial.printf("(int)   = %-50d     ",  //
                      bq25798.rawToInt(newRawValues[i], setting));
        if (!justStarted) {
          Serial.printf("(was %5d)",  //
                        bq25798.rawToInt(oldRawValues[i], setting));
        }
      }
      Serial.println();
    }
  }
  if (changed) {
    printMostImportantStats();
    Serial.println();  // group the changes
  }

  // update the old values
  for (int i = 0; i < BQ25798::SETTINGS_COUNT; i++) {
    oldRawValues[i] = newRawValues[i];
  }

  // Every 1 second read the ADC values in one-shot mode
  long elapsedADCMillis = millis() - lastADCReadMillis;
  if (elapsedADCMillis >= ADC_readout_time_millis) {
    // Serial.printf("ADC readout elapsed time: %ld ms\n", elapsedADCMillis);
    lastADCReadMillis = millis();
    bq25798.setAndWriteBool(bq25798.ADC_EN, 1);  // trigger ADC one-shot mode
  }
}

void repeatedSetup() {
  // Disable HIZ mode (high impedance mode):
  bq25798.setAndWriteBool(bq25798.EN_HIZ, 0);

  // Enable OTG and BACKUP mode:
  // bq25798.setAndWriteBool(bq25798.EN_OTG, 1);
  bq25798.setAndWriteBool(bq25798.EN_BACKUP, 1);
}
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

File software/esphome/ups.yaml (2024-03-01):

substitutions:
  devicename: "yyyyyyyyyy"
  deviceip: xxxxxxxxxx
  friendlyname: "Router UPS"
  # ESP32C3 super mini
  board: seeed_xiao_esp32c3

packages:
  esphome: !include include/esphome.yaml
  base: !include include/base.yaml
  wifi: !include include/wifi.yaml
  webserver: !include include/webserver.yaml
  external_components: !include include/external_components.yaml
  sensors: !include include/common_sensors_and_controls.yaml

# -------------------------------------------------
# Individual board settings:
#

i2c:
  id: bus_a
  scl: GPIO20
  sda: GPIO21
  scan: true

# Disable the XL6009 booster by default, enable it ONLY when the charging_bus_voltage is > 5 V and disable it if it's lower
switch:
  - platform: gpio
    id: booster_enable
    name: "Booster enable"
    restore_mode: ALWAYS_OFF
    disabled_by_default: True
    pin: 
      number: GPIO5
      mode:
        output: true
        pulldown: true

text_sensor:
  - platform: template
    name: "State"
    lambda: |-
      if (id(battery_current).state > 0.1) {
        if (id(booster_enable).state) {
          return {"On line power (charging), UPS enabled"};
        } else {
          return {"On line power (charging) but UPS function disabled"};
        }
      } else if (id(battery_current).state < -0.1) {
        return {"On battery, discharging"};
      } else {
        if (id(booster_enable).state) {
          return {"On line power (idle), UPS enabled"};
        } else {
          return {"On line power (idle) but UPS function disabled"};
        }
      }
    update_interval: 1s
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

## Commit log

2025-04-19 update interactive BOM
2025-04-26 track changes
2025-04-28 update board to v2.1
    [bq25798_module.kicad_pcb, bq25798_module.kicad_sch]
2025-04-29 v2.1 final
    [bq25798_module.kicad_pcb, bq25798_module.kicad_sch]
2025-04-30 update test program for esp32
2025-04-30 chore: fix versions, add PDF schematics
2025-05-26 add thermal reliefs, simplify PCB
    [bq25798_module.kicad_pcb, bq25798_module.kicad_sch]
2025-06-01 add power output to the J4
    [Controller.kicad_sch, bq25798_module.kicad_pcb, bq25798_module.kicad_sch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]
2025-06-02 update board for powering the controller, add controller board
    [Controller.kicad_sch, aux_power.kicad_sch, battery_plus_bms.kicad_sch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]
2025-06-22 Fix invalid connections
    [bq25798_module.kicad_sch]
2025-06-22 update controller board too
    [controller.kicad_pcb]
2025-07-01 fix MQTT discovery topics
    [UPS.ino]
2025-07-02 fix charger check
2025-07-02 move LED blinking to a separate class
2025-07-02 use binary sensor for some ENUMs too
2025-07-02 fix publishing the config topics
    [UPS.ino]
2025-07-02 fix charger enable/disable, cleanup
    [UPS.ino]
2025-07-04 reset button
2025-07-12 publish battery cell count via mqtt
2025-11-13 fix backup recovery timer issue
    [UPS.ino]
2025-11-17 feat: log reset reason for better debugging
    [UPS.ino]
2025-11-17 fix: prevent inability to switch back to online power
    [UPS.ino]
2025-11-17 fix: enable battery discharge current sensing
    [UPS.ino]
2025-11-25 feat: configurable VBUS switchover percentage
2025-11-25 fix: minimum cell voltage
    [UPS.ino]
2025-12-09 feat: proper device model reporting
2025-12-09 fix device model info
    [UPS.ino]
